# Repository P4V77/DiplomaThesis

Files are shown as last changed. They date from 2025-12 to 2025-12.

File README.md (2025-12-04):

# Modular Current Source
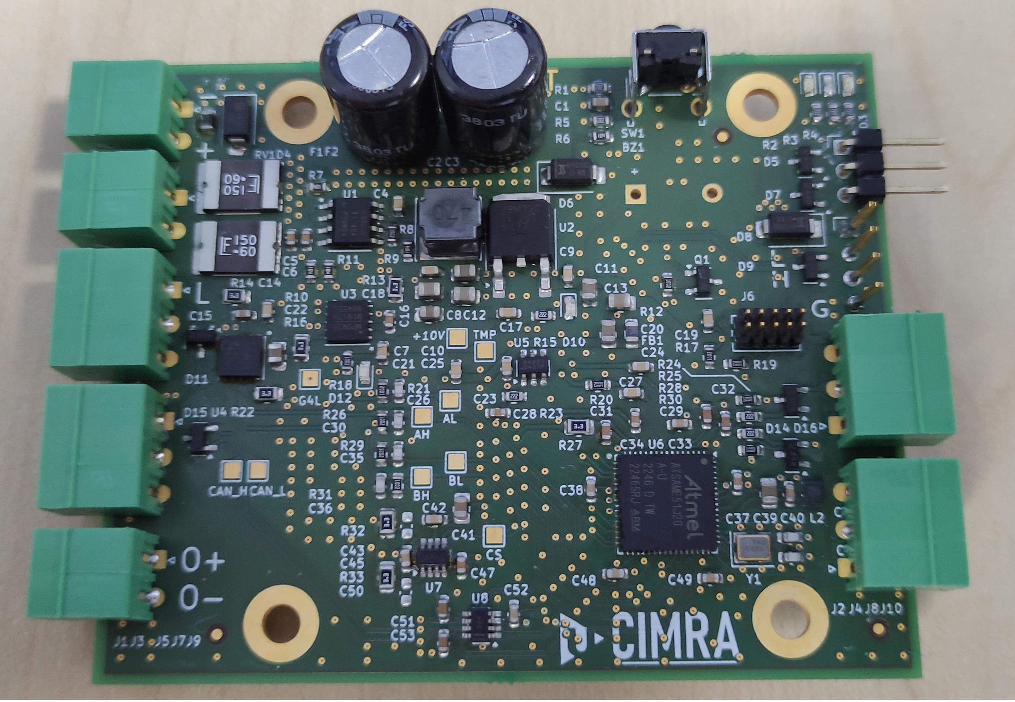
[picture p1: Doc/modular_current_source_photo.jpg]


## Specifications
### v2.0
- **U<sub>IN</sub>** = 12 - 48V
- **I<sub>OUT_DC</sub>** = &plusmn;10 A (max output power limited by PTC fuses to 144W/48V, current is load and input voltage dependent)
- **I<sub>OUT_AC</sub>** = &plusmn;10 A (0 A DC offset, max output power limited by PTC fuses to 144W/48V, current is load and input voltage dependent)
- **Waveforms:**
  - Harmonic with settable DC offset
  - Square with settable DC offset and Duty Cycle <0,100> %
  - Triangle with settable DC offset
- **Default settings:**  
  - I = 0 A
  - DC offset = 0
  - Duty Cycle = 50%
  - Waveform LUT not initialized (DC output set by default)
- **L<sub>load</sub>** at least 100&micro;H, preferably more than 150 &micro;H
- **Communication:**
  - **CAN FD**
    - Baudrate: 500 kb/s
  - **UART**
    - Baudrate: 921 600 Bd
    - 8 data bits
    - 1 stop bit
    - No parity

#### Set New ID
- **Command:** `ID`
- **Data:** Desired ID (0-250)
- **Description:** Sets a new ID for the current source.

**Example:**
```
1ID5  // Sets the ID of the current source to 5
```

#### Set Current
- **Command:** `I`
- **Data:** Desired current as a signed integer in mA (plus sign not allowed)
- **Description:** Sets the current for DC output and amplitude for AC output.

**Examples:**
```
1I650    // Sets current to 650mA for source ID 1
3I-5000  // Sets current to -5A for source ID 3
```

#### Choosing AC/DC Output
- **Commands:**
  - `D` - DC output
  - `A` - AC output
- **Data:**
  - `1` - Enable AC/DC output
  - `0` - Disable output
- **Note:** For AC output, waveform must be chosen first (see "Set Waveform").

**Examples:**
```
1D1  // Enables DC output for source ID 1
4A1  // Enables AC output for source ID 4
```

#### Set Waveform
- **Commands:**
  - `H` - Harmonic waveform
  - `S` - Square waveform
  - `T` - Triangle waveform
- **Data:** Desired frequency in Hz (unsigned integer)
- **Notes:**
  - Zero DC offset, duty cycle defaults to 50% (square)
  - Max waveform frequency from MoSeZ: **6000 Hz** (actual max depends on load)

**Examples:**
```
1H50     // Sets harmonic waveform at 50 Hz for source ID 1
3S6000   // Sets square waveform at 6000 Hz for source ID 3
2T1000   // Sets triangle waveform at 1000 Hz for source ID 2
```

#### Set DC Offset
- **Command:** `O`
- **Data:** Desired DC current offset of alternating current (signed integer in mA, plus sign not allowed)
- **Applicable for:** All AC waveforms

**Examples:**
```
1O650   // Sets DC offset to 650mA for source ID 1
3O-5000 // Sets DC offset to -5A for source ID 3
```

#### Set Duty Cycle (Square Wave Only)
- **Command:** `C`
- **Data:** Desired duty cycle in % (1-99)

**Examples:**
```
1C40  // Sets duty cycle to 40% for source ID 1
3C80  // Sets duty cycle to 80% for source ID 3
```

#### Set Ramp Time (Square Wave Only)
- **Command:** `RT`
- **Data:** Ramp time in percents (unsigned integer)

**Examples:**
```
1RT50  // Sets ramp time of square waveform to 50% (makes triangle waveform) for source ID 1
2RT10 // Sets ramp time of square waveform to 10% for source ID 2
```

#### Set Phase Shift
- **Command:** `F`
- **Data:** Phase shift in degrees (unsigned integer, 0-359)

**Examples:**
```
1F90   // Sets phase shift to 90° for source ID 1
3F180  // Sets phase shift to 180° for source ID 3
```

#### Position Control
- **Command:** `P`
- **Data:**
  - `1` - Enable position control
  - `0` - Disable output
- **Description:** Enables position control for a linear vibrator with position feedback.

**Example:**
```
9P1  // Enables position control for source ID 9
```

#### Set Position Amplitude
- **Command:** `R`
- **Data:** Position amplitude in micrometers (unsigned integer)
- **Constraints:**
  - **Max position offset + amplitude** ≤ 8 mm
  - **Min position offset - amplitude** ≥ 1 mm

**Examples:**
```
1R3500  // Sets position amplitude to 3.5 mm for source ID 1
5R1000  // Sets position amplitude to 1 mm for source ID 5
```

#### Set Position Offset
- **Command:** `V`
- **Data:** Position offset in micrometers (unsigned integer)
- **Constraints:** Same as "Set Position Amplitude"

**Examples:**
```
1V4000  // Sets position offset to 4 mm for source ID 1
5V7000  // Sets position offset to 7 mm for source ID 5
```

#### Start Logging Position to CAN
- **Command:** `CL`
- **Data:**
  - `1` - Start logging
  - `0` - Stop logging
- **Description:** Sends position data every millisecond (ID, actual position, requested position).

**Example:**
```
1CL1  // Starts position logging for source ID 1
```

#### Define Sequence (Whole Period)
- **Command:** `SP`
- **Data:** Duration of the sequence step in whole periods 
- **Description:** Starts defining a new/next sequence command step with a duration measured in whole periods of the waveform.

**Example:**
```
1SP5  // Starts a new sequence step with a duration of 5 whole periods for source ID 1
```

#### Define Sequence (Half Period)
- **Command:** `SH`
- **Data:** Duration of the sequence step in half periods 
- **Description:** Starts defining a new/next sequence command step with a duration measured in half periods of the waveform.

**Example:**
```
2SH10 // Starts a new sequence step with a duration of 10 half periods for source ID 2
```

#### Define Sequence (Milliseconds)
- **Command:** `SW`
- **Data:** Duration of the sequence step in milliseconds 
- **Description:** Starts defining a new/next sequence command step with a duration measured in milliseconds.
**Example:**
```
4SW100 // Starts a new sequence step with a duration of 100 milliseconds for source ID 4
```

#### Stop Filling Current Sequence
- **Command:** `SF`
- **Data:** No data required (value is ignored)
- **Description:** Stops adding commands to the currently being defined sequence step.

**Example:**
```
1SF  // Stops filling the current sequence step for source ID 1
```

#### Start Sequence
- **Command:** `ST`
- **Data:** Any value accepted
- **Description:** Starts the execution of a pre-configured sequence of commands.

**Example:**
```
1ST  // Starts the stored sequence for source ID 1
```

#### Clear All Sequences
- **Command:** `SC`
- **Data:** Any value accepted
- **Description:** Clears all pre-configured sequences of commands.

**Example:**
```
3SC  // Clears all stored sequences for source ID 3
```

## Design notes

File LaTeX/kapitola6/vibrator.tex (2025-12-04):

\newpage

\chapter{Vibrační podavač s voicecoily firmy \emph{DESSEQ}}
\label{sec::voicecoil_function}

Běžné vibrační podavače generují vibrace pomocí rotačních vibrátorů,
což jsou elektrické motory, na jejichž hřídeli je umístěno nevyvážené závaží.
Při otáčení motoru vznikají oscilace v důsledku tohoto nevyvážení rotačního ústrojí.
U takového typu vibrátoru lze řídit pouze výkon otáčky, což má přímý vliv na frekvenci oscilací.

Motivací pro použití vibračního podavače na principu voicecoilu je možnost širšího řízení,
které zahrnuje nejen frekvenci oscilací, ale i jejich amplitudu, výšku vysunutí jádra voicecoilu a
fázi oscilací mezi jednotlivými voicecoily.
Tento přístup umožňuje mnohem přesnější kontrolu nad rychlostí a směrem pohybu součástek po platě,
zejména při kombinaci s dodatečnou snímaním a vyhodnocováním polohy součástek pomocí obrazu z kamery.
Tímto způsobem lze dosáhnout vyšší přesnosti a efektivity při manipulaci jak s drobnými, tak s velkými součástkami.

\begin{figure}[htbp]
	\centering
	
	\caption{Testend vibrační stolice firmy \emph{DESSEQ}}
	\label{fig::vibrator_DESSEQ}
\end{figure}

\section{Snímání polohy}

Pro snímání polohy jádra voicecoilu byla určena metoda snímání změn velikosti
magnetické indukce pomocí senzorů na bázi Hallova jevu.
Optické senzory s dostatečnou datovou prostupností a rozlišením by byly příliš drahé a
kontaktní měření nepřicháyelo v úvahu vzhledem k vibracím a pohybu jádra.
Byly otestovány dvě umístění senzoru.
První umístění bylo na jádře uvnitř voicecoilu a byla měřena magentická indukce jádra.
Druhé umístění bylo na aktuátoru, kde byl měřen magnetický tok přidaného permanentního magnetu.

\subsection{Měření magnetické indukce v jádře voicecoilu}

V prvním prototypu voicecoilu se experimentovalo s umístěním Hallovy sondy na pohyblivém jádře uvnitř voicecoilu.
V tomto případě je magnetická indukce závislá nejen na poloze, ale i na závislosti proudu.
Pro správné určení polohy jádra je nutné znát závislost indukce na proudu a poloze.
Bylo provedeno měření velikosti Hallova napětí při různých proudech a polohách jádra.
Změřená data byla interpolována a následně zdiskretizována do převodní \textit{LUT} tabulky,
která je v tomto případě pole, respektive matice hodnot.
Tato matice hodnot byla nahrána do mikrokontroléru,
který na základě naměřeného Hallova napětí a aktuálního proudu určoval polohu jádra.

\begin{figure}[htbp]
	\centering
	
	\caption{Funkce využitá pro určení polohy jádra prvního prototypu}
	\label{fig::hall_oncore_map}
\end{figure}

Ačkoliv tento způsob umístění a řízení polohy jádra voicecoilu fungoval,
jeho největší nevýhodou bylo obtížnější integrace Hallovy sondy do jádra a
také by do útrob jádra musely vést 3 vodiče navíc,
což by ztěžovalo výrobu a montáž.
Bylo tedy přistoupeno k alternativnímu umístění sondy.

\subsection{Měření indukce permanentního magnetu umístěného zvenku voicecoilu}
\label{section::hall_perm_magnet}

V druhém prototypu voicecoilu byl došlo k umístění permanentního neodymového magnetu na statickém magnetickém obvodu jádra.
Hallova sonda byla umístěna na nástavbě připěvněné na pohyblivém jádře.
Motivací k tomuto umístění je nezávislost magnetické indukce na proudu,
což umožňuje přímo měřit polohu jádra bez ohledu na proud procházející cívkou,
ovšem nevýhodou je potřeba přidání permanenetního magnetu.

\begin{figure}[htbp]
	\centering
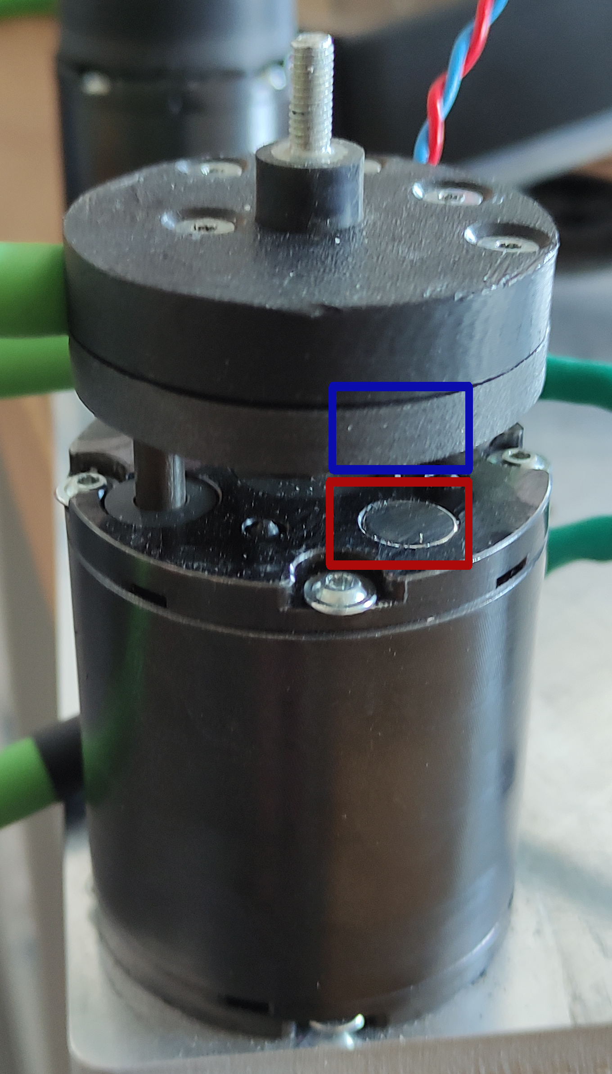
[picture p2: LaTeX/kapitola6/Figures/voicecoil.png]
	
	\caption{Druhý prototyp voicecoilu. V \textbf{červeném} poli umístěn permanentní magnet,
		v \textbf{modrém} poli pod plastovým krytem umístěna Hallova sonda.}
	\label{fig::voice_coil_second_prototype}
\end{figure}

Pro implementaci do mikrokontroléru bylo změřeno výstupní napětí Hallovy sondy při různých polohách jádra.
Výsledky měření byly interpolovány a zdiskretizovány do převodní \textit{LUT} tabulky,
což je v tomto případě pole, respektive pole, viz \oref{fig::hall_perm_magnet}.
Tato předpočítaná \textit{LUT} tabulka byla nahrána do mikrokontroléru.
Konkrétní implementace ve firmwaru je vidět v \nameref{section::position_regulator}.

\begin{figure}[htbp]
	\centering
	
	\caption{Funkce využitá pro určení polohy jádra druhého prototypu}
	\label{fig::hall_perm_magnet}
\end{figure}

\subsection{Přesun součástek}

Omtimální nastavení frekvence a amplitudy kmitů, případně fázového posunu mezi jednotlivými voicecoily,
je závislé na velikosti a hmotnosti součástek, které mají být přesouvány.
V ideálním případě by mělo být nastavování těchto parametrů automatizováno,
například pomocí algoritmu, který by na základě snímání polohy součástek skrze kameru,
určil nastavení proudových zdrojů.
Hledání optimálního nastavení pro přesun součástek je však mimo rámec této práce.

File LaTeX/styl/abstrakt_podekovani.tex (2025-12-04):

\clearpage

\pagenumbering{roman}

%ABSTRAKT

\chapter*{Abstrakt}

Tato diplomová práce se zabývá návrhem a realizací rozšířené verze \emph{modulární platformy MoSeZ} pro řízení elektromagnetických aktuátorů.
Hlavním cílem bylo rozšíření funkcí a zvýšení spolehlivosti původní verze MoSeZ Rev. A.

Vylepšení zahrnují novou revizi jednokanálového proudového zdroje s výstupním proudem až \SI{8}{\ampere},
podporu střídavého výstupu pomocí přímé digitální syntézy \emph{DDS} a implementaci softwarové \textit{PID} regulace ve firmwaru.

Modulární architektura byla zachována – vícekanálové systémy lze sestavit pomocí sběrnice \textit{CAN} a vlastního komunikačního protokolu.
Praktická část zahrnuje návrh \textit{DPS}, vývoj firmwaru v jazyce \textit{C++} a vývoj aplikace \textit{Staff 2.0} pro konfiguraci proudového výstupu zařízení.

Laboratorní měření prokázala přesnost řízení v režimech DC i AC.
Zařízení bylo úspěšně nasazeno k řízení čtyř voicecoilů ve vibračním podavači firmy \emph{DESSEQ}
a závěrem jsou nastíněny možné směry dalšího vývoje.

\vfill\section*{Klíčová slova}

proudový zdroj, elektromagnetické aktuátory, H-můstek, modulární platforma, PID regulace, přímá digitální syntéza, embedded systémy, CAN sběrnice

\vspace{1cm}

\newpage
\chapter*{Abstract}

This thesis deals with the design and implementation of an extended version of the \emph{modular MoSeZ} platform for controlling electromagnetic actuators.
The main objective was to extend the functionality and improve the reliability of the original MoSeZ Rev. A version.

Enhancements include a new revision of the single-channel current source with an output current up to \SI{8}{\ampere}, 
support for alternating output using direct digital synthesis \textit{DDS}, 
and the implementation of software-based \textit{PID} control in \textit{firmware}.

The modular architecture has been retained — multi-channel systems can be assembled using the \textit{CAN} bus and a custom communication protocol. 
The practical part includes the design of the \textit{PCB}, \textit{firmware} development in \textit{C++}, and the \textit{Staff 2.0} application for configuring the current output.

Laboratory measurements confirmed control precision in both DC and AC modes. 
The system was successfully deployed to control four voice coils in a \emph{DESSEQ} vibratory feeder, 
and possible directions for further development are outlined.

\vfill\section*{Keywords}
\noindent
current source, electromagnetic actuators, H-bridge, modular platform, PID control, direct digital synthesis, embedded systems, CAN bus
\vspace{1cm}

%PODEKOVANI

\newpage
\clearpage

\vspace*{3cm}
\section*{Poděkování}\vspace{1.5em}
\noindent
Rád bych poděkoval vedoucímu diplomové práce, \emph{Ing. Martinu Vítkovi}, za cenné odborné rady, vstřícný přístup a metodické vedení, 
které významně přispěly k úspěšnému dokončení této práce. Dále děkuji společnosti \emph{DESSEQ} za poskytnutí \emph{voicecoilů} a 
experimentálních vibračních stolic a za možnost ověřit návrh v praxi.  Poděkování patří také \emph{Ing. Zdeňku Kubíkovi, Ph.D.}, 
který umožnil měření vyzařování v EMC komoře. 
V neposlední řadě děkuji za sílu a vnitřní klid, které mi byly v průběhu práce dopřány z míst, jež přesahují každodennost.

\newpage
\clearpage

\vspace*{3cm}
\section*{Prohlášení}\vspace{1.5em}
\noindent
Během přípravy této práce autor použil \textit{ChatGPT} a \textit{Gemini AI}
k zlepšení čitelnosti a jazykové kvality rukopisu. 
Po použití tohoto nástroje/služby autor pečlivě zkontroloval a
upravil obsah podle potřeby a přebírá plnou odpovědnost za výsledný obsah práce.

% Tato diplomová práce se zaměřuje na návrh a realizaci rozšířené verze modulární platformy \emph{MoSeZ} určené pro řízení elektromagnetických aktuátorů. 
% Cílem práce bylo zvýšit modularitu, spolehlivost a funkční rozšiřitelnost původní verze zařízení \emph{MoSeZ Rev. A}, 
% a přizpůsobit ji pro širší spektrum technických aplikací.

% Navržená vylepšení zahrnují novou hardwarovou revizi jednokanálového proudového zdroje s výstupním proudem až \SI{8}{\ampere}, 
% doplněnou o podporu střídavých proudových výstupů pomocí přímé digitální syntézy (\emph{DDS}) a 
% řešení regulace pomocí softwarového \emph{PID} regulátoru.

% Významným aspektem návrhu je zachování modulární architektury platformy, 
% která umožňuje sestavení vícekanálového systému z jednotlivých jednokanálových modulů propojených pomocí průmyslové sběrnice \emph{CAN}. 
% Vlastní komunikační protokol založený na sběrnici \emph{CAN} zajišťuje kompatibilitu a integraci do rozsáhlejších systémů.

% Teoretická část práce se zabývá rešerší komunikačních protokolů využívajících sběrnici \emph{CAN}.
% Praktická část zahrnuje návrh desky plošných spojů, vývoj firmwaru v jazyce \emph{C++} a 
% tvorbu desktopové aplikace \emph{Staff 2.0} pro konfiguraci a diagnostiku proudového výstupu zařízení.

% Navržené řešení bylo ověřeno sérií laboratorních měření zaměřených na výstupní proud, 
% účinnost, harmonické zkreslení a přesnost regulace. 
% Výsledky prokázaly, že zařízení splňuje požadavky na přesné řízení elektromagnetických aktuátorů v režimech \emph{DC} i \emph{AC}.
% Zařízení bylo rovněž úspěšně nasazeno pro řízení čtyř voicecoilů v experimentálním vibračním podavači firmy \emph{DESSEQ}. 
% Závěrem je navrženo možné směřování dalšího vývoje platformy.

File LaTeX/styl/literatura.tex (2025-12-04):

%https://www.overleaf.com/learn/latex/Biblatex_bibliography_styles
\renewcommand\bibname{Seznam použité literatury}
\printbibliography
\addcontentsline{toc}{chapter}{Seznam použité literatury}

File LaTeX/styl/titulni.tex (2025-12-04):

\begin{titlepage}
\begin{center}

	\textsc{\huge Západočeská univerzita v Plzni}

	%\textcolor[RGB]{91, 155, 213}{\rule{\textwidth}{1.5pt}}
	\textcolor{blue-light}{\rule{\textwidth}{1.5pt}}
    
    \Large{Fakulta elektrotechnická} \\
    \large{\thesisdepartment}

	\vspace{7cm}

	\Huge{\textsc{\textbf{\thesistype}}} \\
	\vspace{0.5cm}
	\Large{\thesistopic} \\
	
	\vfill

	\large
	\begin{tabular}{ m{4cm} m{6cm} } 
		Autor práce: & \textbf{\thesisauthor} \\
		Vedoucí práce: & \textbf{\thesissupervisor} \\
		% Konzultant práce: & \textbf{\thesisconsultant} \\
	\end{tabular}

	\textcolor[RGB]{91, 155, 213}{\rule{\textwidth}{1.5pt}}
	\Large\number\year

\end{center}

\cleardoublepage
\end{titlepage}

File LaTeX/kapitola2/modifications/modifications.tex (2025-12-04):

\chapter{Úpravy desky plošného spoje proudového zdroje \emph{MoSeZ Rev. A}}

Při nové revizi desky (Rev. B) byl kladen důraz na zvýšení maximálního napájecího napětí z \SI{12}{\volt} na \SI{48}{\volt}, 
s možností pracovat již od \SI{12}{\volt}. 
Byly identifikovány a odstraněny některé problémy v původní verzi (Rev. A) proudového zdroje \textit{MoSeZ}. 
Rovněž byly rozšířeny funkce a věnována pozornost zmenšení velikosti desky plošného spoje.

Z pohledu součástkové základny byl značně zredukován počet druhů součástek. 
Operační zesilovače nejsou v nové revizi vůbec použity a druhy kondenzátorů a rezistorů byly výrazně sníženy. 
Zůstalo čtyřvrstvé \textit{DPS} (\textit{TOP} – \textit{IN1} – \textit{IN2} – \textit{BOT}), 
avšak vrstevní uspořádání bylo upraveno na \textit{SIGNÁL} – \textit{GND} – \textit{GND} – \textit{SIGNÁL} 
namísto původního \textit{SIGNÁL} – \SI{3,3}{\volt} – \textit{GND} – \textit{SIGNÁL}. 
Většina součástek byla přesunuta na \textit{TOP} stranu desky, 
zatímco na \textit{BOT} straně zůstaly pouze výkonové \textit{MOSFET} tranzistory a ochranné \textit{TVS} diody. 
Celkové rozměry desky byly zredukovány o přibližně \SI{21}{\percent}.

Další detailní úpravy jsou popsány v následujících podkapitolách, 
které odpovídají blokovému rozdělení v elektrickém schématu, viz obr. \ref{fig::block_diagram}.

\begin{figure}[htpb]
	\centering
	
	\caption{Blokové schéma MoSeZ rev. B}
	\label{fig::block_diagram}
\end{figure}

\section{Vstupní obvody}

Vstupní obvody desky MoSeZ (rev. B) jsou navrženy tak,
aby zajistily spolehlivou ochranu a stabilní napájení.
Zvlnění vstupního napětí efektivně minimalizuje kombinace dvou elektrolytických kondenzátorů.
Pro ochranu proti přetížení jsou na vstupu dvě \textit{PTC} pojistky.
Jakmile proud překročí bezpečný limit, pojistky zvýší svůj odpor a odpojí napájení.
Proti přepólování je deska chráněna kombinací diody a \textit{PTC} pojistek,
zatímco varistor a \textit{TVS} dioda poskytují ochranu proti přepětí.
Měření vstupního napětí probíhá přes napěťový dělič,
který převádí maximální napětí na úroveň vhodnou pro analogově-digitální převodník mikrokontroléru.

\subsection{Vstupní elektrolytické kondenzátory}
\label{section::input_capacitors}
Minimální kapacitu vstupního kondenzátoru lze vypočítat podle jednoduchého vzorce:

\begin{equation}
	C_{\text{IN}} \geq \frac{I_{\text{LOAD}}}{f_{\text{SW}} \cdot \Delta U_{\text{ripple}}},
	\label{eq:min_capacity}
\end{equation}

kde:
\begin{itemize}
	\item $C_{\text{IN}}$ je minimální kapacita vstupního kondenzátoru ve \SI{}{\farad}
	\item $I_{\text{LOAD}}$ je proud zátěže v \SI{}{\ampere}
	\item $f_{\text{SW}}$ je spínací frekvence \SI{}{\hertz}
	\item $\Delta U_{\text{max\_zvlnění}}$ je maximální povolené zvlnění napětí \SI{}{\volt}
\end{itemize}

Maximální plánovaný výstupní proud zdroje \emph{MoSeZ} je $I_{\text{LOAD}} = \SI{8}{\ampere}$, 
ale pro rezervu ve výpočtech byl zvolen proud $I_{\text{LOAD}} = \SI{10}{\ampere}$.
Plánovaná spínací frekvence je $f_{\text{SW}} = \SI{100}{\kilo\hertz}$
a maximální přípustné zvlnění vstupního napětí bylo určeno na \SI{0,5}{\volt},
takže po dosazení do rovnice \eqref{eq:min_capacity} dostáváme:

\begin{equation}
	C_{\text{IN}} \geq \frac{10}{100 \cdot 10^3 \cdot 0,5}
\end{equation}

takže,

\begin{equation}
	C_{\text{IN}} \geq  240 \,\mu\mathrm{F}
\end{equation}

Zvolené zvlnění \SI{0,5}{\volt} zohledňuje napájecí napětí \SI{12}{\volt} a
potřebu dostatečné rezervy pro napájení pomocného spínaného zdroje \textit{LMR38010} (viz \nameref{section::smps_LMR38010}).
Tento pomocný zdroj zajišťuje výstupní napětí \SI{10}{\volt},
které je kritické pro napájení budičů \textit{MOSFET} tranzistorů \textit{MP1917}.
Napájecí napětí těchto budičů se totiž rovná spínacímu napětí na jejich výstupu (viz \cite{mp1917_ds}).
Pokud by spínací napětí MP1917 kleslo pod \SI{10}{\volt},
hrozilo by neúplné otevření hradel MOSFET tranzistorů,
což by mohlo vést k jejich přehřívání (viz \cite{ISC080N10NM6_ds}).
Vzhledem k tomu, že k významnému zvlnění dochází při vyšších výstupních proudech,
hrozí v takovém případě poškození tranzistorů vlivem tepelného průrazu.

Kvůli běžné toleranci kapacity elektrolytických kondenzátorů \SI{\pm 20}{\percent} jsem
pro filtraci napájení zvolil dvojici \SI{150}{\micro\farad} \textit{THT} kondenzátorů.
Použití \textit{THT} kondenzátorů v této kapacitní kategorii přináší finanční úsporu oproti povrchově montovaným (\textit{SMD}) kondenzátorům,
které byly použity v předchozí verzi desky \emph{MoSeZ} (rev. A).

\subsection{Nadproudová ochrana a ochrana proti přepolování}

Pro nadproudovou ochranu byly použity \textit{PTC} pojistky \textit{2920L150/60 od firmy Littelfuse}.
Oproti původnímu návrhu desky (\textit{MoSeZrev. A}) byl počet těchto pojistek snížen na dvě.
Každá z pojistek je dimenzována pro trvalý proud \SI{1,5}{\ampere},
což dohromady postačuje pro jištění trvalého proudu do \SI{3}{\ampere}.
Původní ochranná dioda byla nahrazena levnějším modelem \textit{BYG10D}.
Tato dioda spolu s \textit{PTC} pojistkami slouží jako ochrana proti přepólování.
V případě nechtěné záměny polarity napájecího napětí se dioda \textit{BYG10D} stane vodivou a zkratuje vstupní napětí.
Pokud proud z napájecího zdroje v takové situaci překročí \SI{3}{\ampere}, \textit{PTC} pojistky se zahřejí a obvod rozpojí.

V případě, kdy proud z napájecího zdroje nepřekročí prahový proud \textit{PTC} pojistek,
hrozí tepelný průraz diody \textit{BYG10D}.
To by ovšem znamenalo, že se dioda pravděpodobně stane trvale vodivou,
takže by došlo k vyřazení zdroje z provozu do doby její výměny.
Elektrolytické kondenzátory by však zůstaly ochráněny.

\section{Ochrana proti přepětí}

Pro ochranu proti přepětí na vstupu slouží kombinace varistoru a \textit{TVS} diody,
obě s pracovním napětím \SI{48}{\volt}.
Při návrhu je klíčové umístit tyto součástky co nejblíže vstupnímu konektoru.
Důležité je i jejich fyzické uspořádání od nejpomalejší po nejrychlejší,
tedy nejblíže ke vstupnímu konektoru varistor a za ním \textit{TVS} dioda.
Tím je zajištěno, že rychlá \textit{TVS} dioda omezí přepětí do doby, než se aktivuje varistor,
který následně převezme hlavní část svodového výkonu.
Varistory, jakožto pomalejší ochranné prvky, jsou schopny dlouhodobě svádět větší výkon než \textit{TVS} diody.
V případě opačného pořadí hrozí, že \textit{TVS} dioda bude muset odvést veškerý výkon,
protože na varistor, se nedostane žádné přepětí, což by mohlo vést ke zničení \textit{TVS} diody.

\subsection{Měření vstupního napětí}

Vstupní napětí je měřeno pomocí děliče napětí,
který je navržen tak, aby při \SI{48}{\volt} na vstupu dával na výstupu \SI{1,65}{\volt}.
Maximální napětí, které jsou schopny měřit AD převodníky použitého mikrokontroléru (viz \nameref{section::mcu_hw}),
je \SI{2,5}{\volt}, přičemž jsou tolerantní vůči napětí \SI{3,3}{\volt}.
To znamená, že jsou schopny měřit vstupní napětí až do \SI{106}{\volt}
a k poškození analogových vstupů MCU dojde až při napětí \SI{141}{\volt}.
Tato velká rezerva je zvolena z důvodu ochrany analogových vstupů mikrokontroléru,
a tím i jeho převodníku, před přepětím, nebo v případě, že by uživatel připojil příliš vysoké napětí.
Velikost vstupního napětí se nepoužívá pro regulaci a jeho znalost slouží pouze pro orientační měření.
Proto není kritická přesnost tohoto měření.

\section{Pomocný zdroj napětí \SI{10}{\volt}}
\label{section::smps_LMR38010}

V nové revizi \textit{DPS} zajišťuje \SI{10}{\volt} výstup pro budiče \textit{MOSFET} tranzistorů obvod \textit{LMR38010}.
Tento synchronní snižující měnič reguluje široký rozsah vstupního napětí
a minimalizuje potřebu externích ochranných součástek a
umožňuje nastavit spínací frekvenci v rozsahu \SI{200}{\kilo\hertz} až \SI{2.2}{\mega\hertz}.
Vestavěné ochrany zahrnují proudové omezení po jednotlivých cyklech,
ochranu proti zkratu a tepelnou ochranu při nadměrném vyzářeném výkonu.

\subsection{Výpočet velikosti odporů v napěťové zpětné vazbě}

Rovnice pro výpočet zpětnovazebního rezistoru z datasheetu viz \cite{mp1917_ds} říká, že

\begin{equation}
	R_{FBT} = \frac{U_{OUT} - U_{REF}}{U_{REF}} \cdot R_{FBB},
	\label{eq:lmr_fb}
\end{equation}

kde

\begin{enumerate}
	\item \(R_{FBT} \) : Odpor horního rezistoru (mezi \(U_{OUT} \) a \textit{FB} pinem), měl by vyjít v rozmezí mezi \SI{10}{\kilo\ohm} až \SI{100}{\kilo\ohm}.
	\item \(U_{OUT} \) : Požadované výstupní napětí stabilizátoru.
	\item \(U_{REF} \) : Referenční napětí, \SI{1}{\volt} pro \textit{LMR38010}.
	\item \(R_{FBB} \) : Odpor dolního rezistoru (mezi FB pinem a zemí).
\end{enumerate}

dosazením $ \quad U_{OUT} = \SI{10}{\volt}$ a $R_{FBB} = \SI{10}{\kilo\ohm}$ dostávám:

\begin{equation}
	R_{FBT} = 9 \cdot 10 \cdot 10^3 = \SI{90}{\kilo\ohm}
\end{equation}

Nicméně pro unifikaci pasivních součástek byl zvolen $ \quad R_{FBT} = \SI{100}{\kilo\ohm}$ a $R_{FBB} = \SI{10}{\kilo\ohm}$,
takže upravení rovnice \eqref{eq:lmr_fb} dostávám výstupní napětí pro tuto kombinaci, asice:

\begin{equation}
	U_{OUT} = U_{REF} \cdot \left(\frac{R_{FBT}}{R_{FBB}} + 1 \right) = 1 \cdot \left(\frac{100}{10} + 1 \right) = \SI{11}{\volt}.
	\label{eq:lmr_vout_real}
\end{equation}

Těmito \SI{11}{\volt} jsou napájeny budiče \textit{MP1917},
což znamená, že se zároveň jedná o napětí,
kterými budou budiče spínat gaty \textit{MOSFET} transistorů, viz \cite{mp1917_ds}.
Napětí \SI{11}{\volt} je dle datasheetu tranzistorů \textit{ISC080N10} přípustná velikost spínacího napětí gatů,
viz \cite{ISC080N10NM6_ds}.

\subsection{Výpočet velikosti odboru programujícího spínací kmitočet}

Rovnice pro výpočet odporu RT z datasheetu \cite{mp1917_ds} říká, že

\begin{equation}
	R_{T} = 30970 \cdot f_{SW}^{-1,027},
	\label{eq:lmr_rt}
\end{equation}

kde

\begin{enumerate}
	\item $R_{T}$ : Odpor mezi pinem textit{RT/SYNC} a zemí, udávaný v\SI{}{\kilo\ohm}.
	\item $f_{SW}$ : Spínací frekvence, udávaná v \SI{}{\kilo\hertz}.
\end{enumerate}

Pro unifikaci pasivních součástek byl zvolen R\_{T} = \SI{50}{\kilo\ohm},
respektive paralelní kombinace dvou \SI{100}{\kilo\ohm} odborů použitých v napěťové zpětné vazbě \textit{LMR38010}.
Upravením rovnice \eqref{eq:lmr_rt} dostávám skutečnou spínací frekvenci pro tuto hodnotu terminačního odporu, a sice:

\begin{equation}
	f_{SW} = \left(\frac{R_T}{30970} \right)^{-\frac{1}{1,027}} =
	\left(\frac{50}{30970} \right)^{-\frac{1}{1,027}} \approx \SI{628}{\kilo\hertz}.
	\label{eq:lmr_fsw_real}
\end{equation}

Vyšší spínací frekvence umožňují použití menších induktorů a kondenzátorů ve výstupním LC filtru,
což vede k úspoře místa a potenciálně lepší dynamické odezvě měniče.
Nicméně s rostoucí frekvencí se zvyšují ztráty způsobené parazitními kapacitami
a svody v pasivních součástkách i na plošném spoji, což může negativně ovlivnit účinnost,
zejména při nízkých výstupních výkonech.
Při velmi malých zátěžových proudech a vysokých spínacích frekvencích mohou tyto parazitní ztráty tvořit významnou část celkového výkonu,
a proto bývá výhodnější zvolit nižší spínací frekvenci, kde jsou tyto ztráty menší.
Optimální volba spínací frekvence tak závisí na kompromisu mezi velikostí pasivních součástek,
účinností a požadavky na elektromagnetickou kompatibilitu (EMI), viz \cite{buck_switching_freq_affection}

\subsection{Výpočet velikosti výstupního dolnopropustého LC filtru}

LC filtr je nezbytnou součástí každého spínaného zdroje, zejména pokud má na výstupu stejnosměrné napětí.
Pro správný výběr induktoru jsou klíčové hodnota indukčnosti a saturační proud.
Indukčnost se obvykle volí tak, aby zvlnění výstupního proudu bylo mezi \SI{20}{\percent} a \SI{40}{\percent}.

Pro výpočet minimální indukčnosti platí vztah:

\begin{equation} L \geq \frac{(U_{IN} - U_{OUT})}{f_{SW} \cdot K \cdot I_{OUT(MAX)}} \cdot \frac{U_{OUT}}{U_{IN}}. \label{eq:lmr_inductance} \end{equation}

Saturační proud induktoru by měl být alespoň tak velký jako maximální očekávaný výstupní proud, aby se zabránilo jeho nasycení.
Pro spínací frekvence nad \SI{1}{\mega\hertz} se doporučují induktory s feritovým jádrem kvůli nižším ztrátám.

Maximální výstupní proud $ I_{OUT(MAX)} $ byl zvolen \SI{0,5}{\ampere} pro zajištění dostatečné výkonové rezervy.
I přes špičkové odběry budičů se očekává, že střední hodnota výstupního proudu bude výrazně nižší.
Minimální napájecí napětí bylo stanoveno na $U_{IN} = \SI{12}{\volt}$
a požadované výstupní napětí $U_{OUT} = \SI{11}{\volt}$, viz rovnice \eqref{eq:lmr_vout_real}.
Koeficient zvlnění proudu byl zvolen $K = 0,2$ (tj. \SI{20}{\percent}) a
spínací frekvence $f_{SW} = \SI{628}{\kilo\hertz}$, viz rovnice \eqref{eq:lmr_fsw_real}.

Dosazením do rovnice \eqref{eq:lmr_inductance} dostáváme:

\begin{equation} L \geq \frac{(12 - 11)}{628 \cdot 10^3 \cdot 0,2 \cdot 0,5} \cdot \frac{11}{12} \approx \SI{29,3}{\micro\henry}. \end{equation}

Dle doporučení v datasheetu \cite{mp1917_ds} byla zvolena nejbližší vyšší vyráběná hodnota, tedy $L = \SI{33}{\micro\henry}$.

Minimální kapacita $C_{OUT}$ byla určena podle vztahu, který neuvažuje statické zvlnění,
ale zaměřuje se na schopnost zdroje reagovat na skokové změny výstupního proudu.
To je klíčové, protože zdroj bude primárně napájet budiče \textit{MOSFET} tranzistorů,
kde dochází k rychlým změnám odběru.

\begin{equation}
	C_{OUT} \geq \frac{\Delta I_{OUT}^2 \cdot L}{2 \cdot U_{OUT} \cdot U_{\text{zvlnění}}}
	\label{eq:cout_min_cap_smps}
\end{equation}

kde:

\begin{itemize}
	\item $C_{OUT}$ : Minimální kapacita výstupního kondenzátoru pro omezení překmitu napětí.
	\item $\Delta I_{OUT}$ : Maximální změna výstupního proudu v aplikaci.
	\item $L$ : Indukčnost cívky.
	\item $U_{OUT}$ : Výstupní napětí.
	\item $U_{\text{zvlnění}}$ : Maximální povolená změna výstupního napětí vlivem proudového skoku.
\end{itemize}

Pokud dosadíme následující parametry:

$\Delta I_{OUT} = \SI{1}{\ampere}, \quad
	L = \SI{33}{\micro\henry}, \quad
	U_{OUT} = \SI{11}{\volt}, \quad
	U_{\text{zvlnění}} = \SI{50}{\milli\volt}$
do rovnice \eqref{eq:cout_min_cap_smps}, dostaneme:

\begin{equation}
	C_{OUT} \geq \frac{1^2 \cdot 33 \cdot 10^{-6}}{2 \cdot 11 \cdot 50 \cdot 10^{-3}} \approx \SI{30}{\micro\farad}.
\end{equation}

Na filtraci jsou použity keramické kondenzátory s dielektrikem \textit{X7R} dimenzované na napětí \SI{25}{\volt}.
Keramika \textit{X7R} má následující vlastnosti:

\begin{itemize}
	\item \textbf{Snížení kapacity při DC napětí} – při $\frac{1}{2}$ nominálního napětí a
	      pokojové teplotě je kapacita až o \SI{30}{\percent} nižší než nominální hodnota.
	\item \textbf{Teplotní drift} – změna kapacity až $\pm15\%$ v rozsahu \SI{-50}{\degreeCelsius} až \SI{+125}{\degreeCelsius}.
	\item \textbf{Stárnutí materiálu} – kapacita klesá o jednotky procent v čase.
\end{itemize}

Vzhledem k těmto faktorům a snaze unifikovat součástky na desce \emph{MoSeZ} byla použita kombinace:

\begin{itemize}
	\item $3 \cdot \SI{22}{\micro\farad}$ keramické kondenzátory \textit{X7R}.
	\item $1 \cdot \SI{100}{\nano\farad}$ keramický kondenzátor umístěný co nejblíže k cívce pro redukci vysokofrekvenčního rušení.
\end{itemize}

Tato kombinace zajišťuje \textbf{dostatečnou rezervu kapacity}, \textbf{nižší ESR} a \textbf{lepší potlačení rušení}.

\subsection{Vstupní filtrační kondenzátory}

Na vstupu je pouze paralelní kombinace dvou \SI{22}{\nano\farad} kondenzátorů pro filtraci vysokofrekvenčního rušení.
Další kondenzátory s vyšší kapacitou byly z návrhu vyřazeny.
Důvodem je umístění obvodu \textit{LMR38010} v těsné blízkosti velkých vstupních filtračních kondenzátorů
(viz \nameref{section::input_capacitors}).
Vzhledem k této skutečnosti se ukázalo použití lokálních filtračních kondenzátorů s větší kapacitou jako zbytečné.
Toto řešení přineslo značnou prostorovou úsporu na DPS,
což bylo velmi výhodné, protože v oblasti usazení obvodu \textit{LMR38010} byl prostor velmi omezený.

\section{Pomocný zdroj napětí \SI{3,3}{\volt}}
\label{sec::linear_lm78}

Napětí \SI{3,3}{\volt} pro mikroprocesor a 
ostatní obvody jako \textit{TCAN334G}, \textit{INA241B1},
či \textit{MCP1501T}  obstarává obvod \textit{LMA78M33}.
Jedná se o lineární stabilizátor napájený \SI{10}{\volt} výstupu z \textit{LMR38010}, viz \nameref{section::smps_LMR38010}.
Filtrační kondenzátory byly zvoleny dle jasného doporučení v datasheetu bez jakýchkoliv kalkulací,
viz \cite{LM78M_ds}.
Samotý obvod je tak jednoduchý a obecně známý, že nemá cenu o něm cokoliv více psát.

V původní verzi zdroje byly pro snižování vstupního napětí použity dva snižující měniče v integrovaném obvodu \textit{MP2344}.
Tyto obvody poskytovaly napětí \SI{10}{\volt} pro napájení budičů \textit{MOSFET} tranzistorů a \SI{3,3}{\volt} pro napájení mikroprocesoru.
V důsledku náhodných přepětí na výstupu těchto obvodů docházelo k poškození mikroprocesorů.
Záměnou řešení s \textit{MP2344} se podařilo problém odstranit,i když to nemusela být vina obvodů jako takových,
ale například špatného návrhu snižujících měničů. 
Nové řešení s \textit{LM78M33} je v každém případě mnohem jednodušší a levnější.

\section{Mikrokontrolér}
\label{section::mcu_hw}

V mikrokontroléru bude implementovaný regulátor a bude obstarávat veškerou komunikaci,
včetně zpracovávání vstupů z tlačítka a rozsvicování indikačních \textit{LED}.
Nová revize využívá stejný typ mikrokontroléru, asice \textit{ATSAME51J20A}.
V původním návrhu desky byl jako zdroj kmitočtu pro mikroprocesor použit \SI{32}{\kilo\hertz} krystalový rezonátor.
Tento rezonátor způsoboval nespolehlivé spouštění při inicializaci procesoru.
V nové verzi desky byl použit \SI{20}{\mega\hertz} rezonátor, 
který byl ověřen v jiných projektech s \textit{MCU} od \textit{Microchip}.
Došlo také k opravě záměny pinů programovacího konektoru \textit{SWDIO} a \textit{SWDCLK},
což byla chyba v původním návrhu desky \textit{MoSeZ}, která vedla k výrobě specialního programovacího kabelu.

Každý digitální napájecí vstupní pin \textit{VDDIO} je odfiltrován keramickým kondenzátorem s kapacitou \SI{100}{\nano\farad}.
Ke spínanému zdroji integrovaného v mikrokontroléru je připojena indukčnost o velikosti \SI{10}{\micro\henry},
která filtruje výstupní proud a za ni je pro filtrování vzniklého napětí \textit{VDDCORE} připojena kombinace \SI{22}{\micro\farad} a \SI{100}{\nano\farad} kondenzátorů.
Analogové napětí \textit{VDDANA} se tvoří z napětí \textit{VDDIO} přes LC filtr tvořený dvěma kondenzátory a feritovou perličkou zapojenými do $\pi$ článku.
Kondenzátory mají kapacitu \SI{22}{\micro\farad} a feritová perlička o impedanci \SI{330}{\ohm} na frekvenci \SI{100}{\mega\hertz}.
Součástky byly vybrány a zapojeny dle doporučení v datasheetu, viz \cite{ATSAME51J20A_ds}.

\section{Proudový výstup}

Řízení elektromagnetických aktuátorů vyžaduje spolehlivý a výkonný proudový výstup, 
který je schopen generovat obousměrné stejnosměrné (DC) a střídavé (AC) signály s požadovanými parametry. 
Z tohoto důvodu byla v rámci proudových zdrojů \textit{MoSeZ} navržena výstupní část založená na topologii \textit{H-můstku}, 
která umožňuje obousměrný tok proudu a generování dynamicky tvarovaných průběhů.
Klíčovými aspekty návrhu výstupního obvodu jsou vhodná volba výkonových tranzistorů, 
účinné řízení spínacích prvků a tepelný management. 
V následujících podsekcích jsou rozebrány konstrukční i výpočetní aspekty této části obvodu.

\subsection{H-můstek}

Tranzistory \textit{MOSFET} původní revize desky \textit{MoSeZ} by nemohly pracovat na napětí \SI{48}{\volt}, 
proto bylo nutné zvolit nové tranzistory s parametrem \(U_{DS\_MAX} > 2 \cdot \SI{48}{\volt}\). 
Výběr padl na \textit{Infineon ISC080N10}, u kterého bylo nutné ověřit, 
že může být dlouhodobě zatěžován proudem \SI{8}{\ampere} bez rizika tepelného průrazu. 
Maximální proud do zátěže bude uvažován jako \SI{10}{\ampere}, což zajistí určitou výkonovou rezervu.

Pro výpočet celkových ztrát na \textit{MOSFET} tranzistoru se dle \cite{mosfet_losses} se používá následující vztah:

\begin{equation}
    P_{LOSS} = P_{J} + P_{SW} + P_{G}
\end{equation}

kde:

\begin{itemize}
    \item \(P_{LOSS}\): Celkové ztráty na \textit{MOSFET} tranzistoru.
    \item \(P_{J}\): Ztráty způsobené odporem kanálu \textit{MOSFET} tranzistoru (vodivostní ztráty).
    \item \(P_{SW}\): Ztráty vznikající při spínání a rozepínání tranzistoru (spínací ztráty).
    \item \(P_{G}\): Ztráty způsobené kapacitou gate tranzistoru (ztráty hradlem).
\end{itemize}

Vodivostní ztráty se vypočítají jako:

\begin{equation}
    P_{J} = I_{D}^{2} \cdot R_{DS\_ON}
    \label{eq:joullossesfet}
\end{equation}

kde ze zadání a datasheetu \cite{ISC080N10NM6_ds}:

\begin{itemize}
    \item \(I_D\): Proud protékající tranzistorem (Drain current) – \SI{10}{\ampere}.
    \item \(R_{DS\_ON}\): Odpor kanálu tranzistoru v sepnutém stavu (Drain-source resistance on-state) – \SI{8.5e-3}{\ohm}.
\end{itemize}

Dosazením těchto hodnot do rovnice \eqref{eq:joullossesfet} dostaneme:

\begin{equation}
    P_{J} = 10^2 \cdot 8.5 \cdot 10^{-3} = \SI{0,85}{\watt}
\end{equation}

Spínací ztráty se vypočítají jako:

\begin{equation}
    P_{SW} = 0,5 \cdot U_{CC} \cdot I_{D} \cdot (t_{r} + t_{f}) \cdot f_{SW}
    \label{eq:switchingFETlosses}
\end{equation}

kde dle zadání a datasheetu \cite{ISC080N10NM6_ds}:

\begin{itemize}
    \item \(U_{CC}\): Napájecí napětí – \SI{48}{\volt}.
    \item \(t_{r}\): Náběžná doba spínání – \SI{2,9e-9}{\second}.
    \item \(t_{f}\): Sestupná doba spínání – \SI{2,6e-9}{\second}.
    \item \(f_{SW}\): Spínací frekvence – \SI{100}{\kilo\hertz}.
\end{itemize}

Dosadíme tyto hodnoty do rovnice \eqref{eq:switchingFETlosses}:

\begin{equation}
    P_{SW} = 0,5 \cdot 48 \cdot 10 \cdot 2,9 \cdot 10^{-9} + 2,6 \cdot 10^{-9} \cdot 100 \cdot 10^{3} = \SI{0,1392}{\watt}
\end{equation}

Ztráty hradlem se vypočítají jako:

\begin{equation}
    P_{G} = Q_{G} \cdot U_{CC} \cdot f_{SW}
    \label{eq:FETleakgatelosses}
\end{equation}

kde dle předchozích výpočtů a datasheetu \cite{ISC080N10NM6_ds}:

\begin{itemize}
    \item \(Q_{G}\): Celkový náboj hradla (gate charge total) – \SI{2,38e-8}{\coulomb}.
\end{itemize}

Pro výše uvedené parametry, po dosazení do rovnice \eqref{eq:FETleakgatelosses} dostáváme:

\begin{equation}
    P_{G} = 2,38 \cdot 10^{-8} \cdot 48 \cdot 100 \cdot 10^{3} = \SI{0,1142}{\watt}
\end{equation}

Celkové ztráty se vypočítají jako součet všech ztrát:

\begin{equation}
    P_{LOSS} = P_{J} + P_{SW} + P_{G} = 0,85 + 0,1392 + 0,1142 = \SI{1,1034}{\watt}
\end{equation}

Maximální přípustné ztráty tranzistoru při chlazení footprintem DPS lze určit jako:

\begin{equation}
    P_{Z\_MAX} = \frac{T_{J\_MAX} - T_{\text{SURR}}}{R_{\text{thJA}}}
\end{equation}

kde dle datasheetu \cite{ISC080N10NM6_ds}:

\begin{itemize}
    \item \(T_{J\_MAX}\): Maximální přípustná teplota přechodu tranzistoru – \SI{175}{\celsius}.
    \item \(T_{\text{SURR}}\): Okolní teplota – \SI{50}{\celsius} (určeno jako teplota okolí s velkou rezervou).
    \item \(R_{\text{thJA}}\): Tepelný odpor tranzistor-okolí – \SI{75}{\kelvin\per\watt}. 
	Dle datasheetu \cite{ISC080N10NM6_ds} je \SI{50}{\kelvin\per\watt} pro \SI{6}{\centi\meter^2}. 
	Ačkoliv plánuji ještě větší chladící plochu, pro jistotu jsem přidal rezervu.
\end{itemize}

Po dosazení:

\begin{equation}
    P_{Z\_MAX} = \frac{175 - 50}{75} = \SI{1,6667}{\watt} > P_{LOSS} % Opraveno na >
\end{equation}

Takže tranzistor by neměl mít s provozem \SI{8}{\ampere} sebemenší problém. 
Teplota přechodu se při těchto provozních parametrech dá spočítat jako:

\begin{equation}
    T_{J} = T_{\text{SURR}} + P_{LOSS} \cdot R_{\text{thJA}}
\end{equation}

Po dosazení hodnot známých z předchozích výpočtů dostaneme:

\begin{equation}
    T_{J} = \SI{50}{\celsius} + \SI{1,1034}{\watt} \cdot \SI{75}{\kelvin\per\watt} = \SI{132,758}{\celsius} % Opraveno na 132,758
\end{equation}

Vypočtená teplota přechodu \SI{132,758}{\celsius} je mnohem nižší než maximální výrobcem přípustná teplota \SI{175}{\celsius}, 
takže tranzistor by měl být schopen pracovat bez rizika tepelného průrazu s relativně slušnou teplotní rezervou.
Proudový výstup je chráněn proti náhodným přepětím dvěma \textit{TVS} diododami s pracovním napětím \SI{48}{\volt},
viz \pref{priloha:schema_CurrentOutput}.

\subsection{Budiče tranzistorů}

Jsou využity dva budiče \textit{MOSFET} tranzistorů \textit{MP1917}.
Každý je řízen dvěma \textit{PWM} signály, z nichž jeden je pro řízení \textit{low-side} tranzistoru a
druhý pro řízení \textit{high-side} tranzistoru.
\textit{High-side} tranzistor je označován jako plovoucí, protože jeho \textit{Source} elektroda není přímo spojen se zemí,
ale je připojen k zátěži a \textit{low-side} tranzistoru.
Proto je výhodnější použít speciálně navržené budiče.
Pro otevření \textit{low-side} tranzistoru by stačil i napěťově zesílený signál z mikrokontroléru, což neplatí pro \textit{high-side} tranzistor.
Podmínka pro otevření libovolného \textit{MOSFET} tranzistoru je:

\begin{equation}
	U_{G} > U_{T} + U_{S}
\end{equation}

kde:

\begin{itemize}
	\item \(U_{G}\): Napětí na gate elektrodě tranzistoru.
	\item \(U_{T}\): Prahové napětí \textit{MOSFET} tranzistoru, tj. napětí při kterém se začíná otevírat (konstanta součástky).
	\item \(U_{S}\): Napětí na source elektrodě transistoru.
\end{itemize}

Pro \textit{high-side} tranzistor H-můstku platí:

\begin{equation}
	U_{GSH} > U_{T} + U_{LOAD} + U_{LS\_MOSFET}
\end{equation}

kde:

\begin{itemize}
	\item \(U_{LOAD}\): Napětí na zátěži.
	\item \(U_{LS\_MOSFET}\): Napětí na \textit{low-side} tranzistoru.
\end{itemize}

Pro plné otevření tranzistoru je nutné napětí výrazně vyšší než prahové napětí \(U_{T}\).
Tranzistory \textit{ISC080N10} jsou podle datasheetu plně otevřeny při \(U_{GS} = \SI{10}{\volt}\),
přičemž \(U_{GSMAX} = \SI{20}{\volt}\) (viz \cite{ISC080N10NM6_ds}).
Pro plné otevření tedy platí:

\begin{equation}
	U_{GSH} \ge \SI{10}{\volt} + U_{LOAD} + U_{LS\_MOSFET} < \SI{20}{\volt}
	\label{eq:mosfet_hs_opening_floatin}
\end{equation}

Napětí na zátěži \(U_{LOAD}\) a napětí na \textit{low-side} tranzistoru \(U_{LS\_MOSFET}\) jsou závislé na velikosti proudu protékajícího zátěží.
Z rovnice \eqref{eq:mosfet_hs_opening_floatin} vyplývá,
že i napětí potřebné pro otevření \textit{high-side} tranzistoru \(U_{GSH}\) se mění (plave), odtud název „plovoucí“ tranzistor.
Jednou z nejčastěji používaných metod,
jak splnit nerovnici \eqref{eq:mosfet_hs_opening_floatin},
je použití \textit{bootstrap} kondenzátoru a \textit{bootstrap} diody.

Bootstrap kondenzátor slouží jako zdroj napětí pro \textit{high-side} \textit{CMOS} budič,
který je v tomto případě integrován v \textit{MP1917}.
Kondenzátor musí být jednou elektrodou připojen přes \textit{bootstrap} diodu k napájecímu napětí budiče a
druhou elektrodou k potenciálu sourcu \textit{MOSFET} tranzistoru,
respektive k potenciálu zátěže.
Na obrázku \ref{fig::bootstrap_explained_LS_ON} je vidět,
že při sepnutí \textit{low-side} tranzistoru protéká zátěží proud \(I_{LOAD}\) a na zátěži vzniká úbytek \(U_{LOAD}\).
Zároveň je nabíjen \textit{bootstrap} kondenzátor napájecím napětím budiče,
v \oref{fig::bootstrap_explained_LS_ON} jako \(U_{DD} = \SI{10}{\volt}\),
přes \textit{bootstrap} diodu na napětí:

\begin{equation}
	U_{BSC} = \SI{10}{\volt} - U_{D} -  U_{LS} \approx \SI{10}{\volt}
	\label{eq:bootstrap_voltage_LSON}
\end{equation}

\begin{figure}[htpb]
	\centering
	
	\caption{Nabíjení \textit{bootstrap} kondenzátoru přes sepnutý \textit{low-side} tranzistor na napájecí napětí budiče (\SI{10}{\volt}).}
	\label{fig::bootstrap_explained_LS_ON}
\end{figure}

Při rozepnutí tranzistoru \textit{LS} přestává být spodní elektroda kondenzátoru uzemněna a dostává se na potenciál zátěže, takže:

\begin{equation}
	U_{BSC} = \SI{10}{\volt} +  U_{LOAD}
	\label{eq:bootstrap_voltage_LSOFF} % Změněno na LSOFF pro konzistenci
\end{equation}

V tomto momentě zabraňuje vybíjení kondenzátoru \textit{bootstrap} dioda a
na \textit{bootstrap} kondenzátoru se udržuje napětí \(U_{DD} + U_{LOAD}\) vůči zemi.
Při sepnutí \textit{high-side} tranzistoru se toto napětí připojí na gate \textit{MOSFET} tranzistoru,
v \oref{fig::bootstrap_explained_LS_ON} označené jako \(U_{G}\),
a do gatu tranzistoru začne protékat vyrovnávací proud \(I_{G}\),
dokud se kapacita \(C_{G}\) nenabije na napětí \(U_{G}\). Tím je zajištěno, že

\begin{equation}
	U_{GS} = U_{BSC} \approx \SI{10}{\volt}
	\label{eq:bootstrap_voltage_lsoff} % Změněno na lsoff pro konzistenci
\end{equation}

a je dosaženo spínání \textit{high-side} tranzistoru.
Z popsaného principu je jasné, že \textit{high-side} tranzistor nemůže být spínán se střídou \SI{100}{\percent},
protože \textit{bootstrap} kondenzátor musí být nabíjen spínáním \textit{low-side} tranzistoru, viz \oref{fig::bootstrap_explained_LS_ON}.
V současnosti jsou \textit{bootstrap} diody běžně integrovány v budičích,
takže při návrhu stačí zvolit vhodný \textit{bootstrap} kondenzátor.

\begin{figure}[htpb]
	\centering
	
	\caption{Sepnutí \textit{high-side} tranzistoru pomocí součtu napětí na \textit{bootstrap} kondenzátoru a napětí zátěže. Směr proudu zátěží \(I_{LOAD}\) zachován z \oref{eq:bootstrap_voltage_LSON}}
	\label{fig::bootstrap_explained_LS_OFF}
\end{figure}

Tranzistory \textit{Infineon ISC080N10} mají téměř dvojnásobnou kapacitu hradla oproti původním Infineon \textit{BSZ0703L} (\emph{MoSeZ} revize A).
Proto bylo nutné přepočítat hodnoty \textit{bootstrap} kondenzátorů pro budiče \textit{MP1917}.
Výpočet minimální kapacity \textit{bootstrap} kondenzátoru \(C_{\textit{bootstrap}}\) se provádí pomocí provnic \eqref{eq:cboot_min_cap} až \eqref{eq:delta_uhs}
převzatých z \cite{bootstrap_moudra}:

\begin{equation}
	C_{\textit{bootstrap}} \geq \frac{Q_{total}}{\Delta U_{BSTQ}}
	\label{eq:cboot_min_cap}
\end{equation}

kde:

\begin{itemize}
	\item \(C_{\textit{bootstrap}}\): Minimální požadovaná kapacita \textit{bootstrap} kondenzátoru.
	\item \(Q_{total}\): Celkový náboj potřebný pro nabití a udržení hradla \textit{MOSFET} tranzistoru v otevřeném stavu.
	\item \(\Delta U_{BSTQ}\): Maximální přípustný pokles napětí na \textit{bootstrap} kondenzátoru během spínacího cyklu.
\end{itemize}

Celkový náboj \(Q_{total}\) se vypočítá podle vztahu:

\begin{equation}
	Q_{total} = Q_G + I_{DDQ} \cdot \frac{D_{max}}{f_{sw}} + I_{BSTQ} \cdot \frac{1-D_{max}}{f_{sw}}
	\label{eq:qtotal}
\end{equation}

kde:

\begin{itemize}
	\item \(Q_G\): Celkový náboj hradla vybraného \textit{MOSFET} tranzistoru.
	\item \(I_{DDQ}\): Klidový (svodový) proud \textit{\textit{high-side}} budiče.
	\item \(I_{BSTQ}\): Klidový (svodový) proud \textit{bootstrap} obvodu budiče.
	\item \(D_{max}\): Maximální střída \textit{PWM} signálu,
	      v desetiném vyjádření (např. 0.985 pro \SI{98.5}{\percent}).
	\item \(f_{sw}\): Spínací frekvence \textit{PWM} signálu.
\end{itemize}

Dosazením konkrétních hodnot z datasheetu \cite{mp1917_ds}:
\(Q_G = \SI{19}{\nano\coulomb}\),
\(I_{DDQ} = \SI{150}{\micro\ampere}\),
\(I_{BSTQ} = \SI{90}{\micro\ampere}\),
\(D_{max} = 0.985\), \(f_{sw} = \SI{100}{\kilo\hertz}\),
lze vypočíst hodnotu celkového \(Q_{total}\) dle rovnice \eqref{eq:qtotal} jako:

takže

\begin{equation}
	Q_{total} = 19 \cdot 10^{-9} + 150 \cdot 10^{-6} \cdot \frac{0,985}{100 \cdot 10^{3}} + 
	90 \cdot 10^{-6} \cdot \frac{1-0,985}{100 \cdot 10^{3}} \approx \SI{20,48}{\nano\coulomb},
\end{equation}

Maximální přípustný pokles napětí na \textit{bootstrap} kondenzátoru \(\Delta V_{BSTQ}\) se určí z rovnice:

\begin{equation}
	\Delta V_{BSTQ} = U_{DD} - U_{DH} - U_{UPFT} = U_{DD} - U_{DH} - U_{UPRT} - U_{HT}
	\label{eq:delta_uhs}
\end{equation}

kde:

\begin{itemize}
	\item \(U_{DD}\): Napájecí napětí budiče hradla \textit{IC}.
	\item \(U_{DH}\): Úbytek napětí na \textit{bootstrap} diodě.
	\item \(U_{UPFT}\): Prahová hodnota podpěťové ochrany budiče při poklesu napětí na napájecím pinu.
	\item \(U_{UPRT}\): Prahová hodnota podpěťové ochrany budiče při náběhu napětí na napájecím pinu.
	\item \(U_{HT}\): Hystereze podpěťové ochrany budiče.
\end{itemize}

Dosazením konkrétních hodnot z datasheetu \cite{mp1917_ds}:
\(U_{DD} = \SI{11}{\volt}\),
\(U_{DH} = \SI{0,95}{\volt}\),
\(U_{UPRT} = \SI{7,2}{\volt}\),
\(U_{HT} = \SI{0,5}{\volt}\),
lze vypočíst hodnotu celkového \(U_{BSTQ}\) dle rovnice \eqref{eq:delta_uhs} jako:

\begin{equation}
	\Delta U_{BSTQ} = 11 - 0,95 - 7,2 - 0,5 = \SI{2,35}{\volt}.
\end{equation}

Výpočet minimální kapacity \textit{bootstrap} kondenzátoru \(C_{\textit{bootstrap}}\) dle rovnice \eqref{eq:cboot_min_cap}:

\begin{equation}
	C_{\textit{bootstrap}} \geq \frac{\SI{20,48}{\nano\coulomb}}{\SI{2,35}{\volt}} \approx \SI{8,71}{\nano\farad}.
\end{equation}

Pro zajištění dostatečné funkční rezervy byl v obvodu zvolen \textit{bootstrap} kondenzátor s kapacitou \SI{22}{\nano\farad}.
Je však důležité poznamenat, že volba příliš vysoké kapacity \textit{bootstrap} kondenzátoru není žádoucí.
S rostoucí kapacitou se totiž zvyšuje náchylnost k oscilacím na hradle tranzistorů během spínání a rozpínání,
což je způsobeno vznikem rezonancí s parazitními indukčnostmi v budicím obvodu, viz \cite{bootstrap_moudra}.

Naopak, nedostatečná kapacita \textit{bootstrap} kondenzátoru by mohla vést k neúplnému otevření hradla tranzistoru,
a tím ke zvýšení jeho spínacího odporu a ztrátového výkonu.
Zvýšené ztráty by se mohly projevit nepřijatelným zahříváním tranzistorů a potenciálně i jejich poškozením tepelným průrazem.
Pro potlačení oscilací na hradle tranzistoru se doporučuje zařadit tlumící odpor sériově mezi výstup budiče a hradlo tranzistoru.
Tlumící účinek rezistoru se zvyšuje s jeho odporem,
nicméně příliš vysoká hodnota tlumícího odporu zpomaluje nabíjení a vybíjení hradla,
prodlužuje spínací časy a opětovně zvyšuje spínací ztráty.

\section{Měření výstupního proudu}
\label{section::current_meassure}

Pro měření proudu je použit integrovaný obvod \textit{INA241},
což je vysoce přesný obousměrný senzor proudu s pevně nastaveným zesílením.
Tento senzor umožňuje měřit úbytek napětí na snímacích rezistorech v širokém rozsahu souhlasného napětí,
konkrétně od \SI{-5}{\volt} do \SI{110}{\volt},
a to zcela nezávisle na napájecím napětí obvodu.

Vysoká přesnost měření je u obvodu \textit{INA241} zajištěna zejména nízkým vstupním offsetem,
který dosahuje maximálně \SI{\pm10}{\micro\volt},
vysokým poměrem potlačení souhlasného signálu (\textit{CMRR}) pro stejnosměrný proud, typicky \SI{166}{\decibel},
a efektivní schopností potlačení rušení \textit{PWM} signálem díky speciální vnitřní konstrukci,
která by měla minimalizovat přenos rušení, generovaného spínáním tranzistorů, na vstup měřicího obvodu.

\subsection{Napěťová reference}
\label{section::voltage_ref}

Obvod \textit{INA241B1} umožňuje použití vnitřního nebo vnějšího referenčního napětí.
Vnitřní referenční zdroj se aktivuje ponecháním pinů \textit{REF1} a \textit{REF2} nezapojených.
V tomto režimu je výstupní napětí při nulovém proudu rovno polovině napájecího napětí,
což znamená, že výstup je přirozeně ratiometrický – jeho hodnota se mění v závislosti na napájecím napětí.

Bohužel, AD převodníky integrované v mikrokontroléru \textit{ATSAME51J20A} se
dostávají do saturace při napětích vyšších než \SI{2,5}{\volt},
což omezuje využití plného rozsahu výstupu obvodu \textit{INA241B1} při použití vnitřní reference.
Z tohoto důvodu bylo zvoleno zapojení s externí referencí, kde
\textit{REF1} je připojen na výstup přesné napěťové reference a \textit{REF2} je uzemněn.
Tím se výstupní napětí při nulovém proudu posouvá na polovinu napětí referenčního zdroje.
Použitím externí referenční napěťové reference \textit{MCP1501T-25E} s hodnotou \SI{2.5}{\volt}
je pracovní bod výstupu nastaven na \SI{1.25}{\volt} při nulovém vstupním proudu.

Pokud je stejné referenční napětí \SI{2.5}{\volt} použito jako referenční vstup pro AD převodník mikrokontroléru,
je opět zajištěn ratiometrický převod.
To znamená, že výstupní napětí zesilovače i referenční napětí AD převodníku jsou vzájemně proporcionální ke stejnému zdroji,
čímž se eliminuje vliv kolísání napájecího napětí na výsledek měření.

\subsection{Snímací rezistor}

Při výpočtu snímacího rezistoru měření proudu vycházíme z maximálního proudu zátěží,
\(I_{\text{LOAD\_MAX}}\), který je specifikován v zadání úlohy jako \SI{10}{\ampere}.
Dále je nezbytné definovat maximální přípustný výkon, \(P_{D\_MAX}\),
který se bude vyzařovat na snímacím rezistoru.
Obecně platí, že s rostoucím odporem snímacího rezistoru klesají nároky na zesílení zesilovače,
což typicky vede k vyšší přesnosti měření.
Hlavní nevýhodou většího odporu je však nárůst ztrátového výkonu,
který se musí vyzářit, což má negativní dopad na celkovou účinnost systému.

Předpokládejme, že maximální přípustný ztrátový výkon je stanoven na \(P_{D\_MAX} = \SI{0,5}{\watt}\).
Tato hodnota představuje rozumný kompromis, kdy vyzářené teplo lze ještě efektivně odvádět.
V dalším kroku určíme maximální přípustnou velikost snímacího rezistoru, \(R_{\text{SENSE}_\text{MAX}}\), z hlediska ztrátového výkonu:

\begin{equation}
	\label{eq::eq_rsense_maxR}
	R_{\text{SENSE\_PMAX}} = \frac{P_{D\_MAX}}{I_{\text{LOAD\_MAX}}} = \frac{0,5}{10} = \SI{50}{\milli\ohm},
\end{equation}

Pak je nutné zvolit odpor, jehož velikost bude menší než \(R_{\text{SENSE}\_MAX}\)
a který v kombinaci se zesílením \(G\) plně využije dynamický rozsah následujících obvodů.
V tomto konkrétním případě následuje \textit{AD} převodník integrovaný v mikrokontroléru s rozsahem \SI{0}{\volt} až \SI{2,5}{\volt}.
Pro nulový proud je však výstupní napětí zesilovače \textit{INA241} (\(U_{OUT}\)) nastaveno na \SI{1,25}{\volt}
díky napěťové referenci \(U_{REF}\) (viz \nameref{section::voltage_ref}).
Efektivní napěťový rozsah pro měření proudu v jednom směru je tedy \(U_{RANGE} = \SI{1.25}{\volt}\).
Obvod \textit{INA241} se vyrábí s různými zesíleními \(G\). Pro úvodní výpočet zvolíme nejmenší dostupné zesílení, a to \(G = 10 \cdot\).

\begin{equation}
	\label{eq::eq_rsense_maxURANGE}
	R_{\text{SENSE\_UMAX}} = \frac{U_{RANGE}}{I_{\text{LOAD\_MAX}} \cdot G} = \frac{1,25}{10 \cdot 10} = \SI{12,5}{\milli\ohm},
\end{equation}

Pokud nepplatí, že:

\begin{equation}
	\label{eq::eq_rsense_check_PMAX}
	R_{\text{SENSE\_UMAX}} \le R_{\text{SENSE\_PMAX}},
\end{equation}

je nutné přistoupit k úpravě návrhu.
Jednou z možností je volba zesilovače s větším zesílením \(G\).
Alternativně lze zvážit i navýšení maximálního přípustného ztrátového výkonu \(P_{D\_MAX}\).
V tomto konkrétním případě však nerovnice \eqref{eq::eq_rsense_check_PMAX} platí s dostatečnou rezervou ztrátového výkonu.
Proto postačí nalézt nejbližší menší standardně vyráběný snímací odpor, kterým je v tomto případě \SI{12}{\milli\ohm}.

Po zvolení odporu \(R_{SENSE} = \SI{12}{\milli\ohm}\) je klíčové vypočítat citlivost měření proudu v jednotkách \SI{}{\volt/\ampere}.
Znalost citlivosti je nezbytná pro následný výpočet aktuálního proudu z naměřeného výstupního napětí na obvodu \textit{INA241B1},
respektive z napětí na \textit{AD} převodníku mikrokontroléru.
Tuto citlivost lze stanovit z rovnice:

\begin{equation}
	\label{eq::sensitivity_INA}
	\text{Citlivost} = \frac{U_{RANGE}}{I_{\text{LOAD\_MAX}}} = \frac{1,25}{10} = \SI{0,125}{\volt/\ampere}.
\end{equation}

takže

\begin{equation}
	\label{eq::sensitivity_INA_val}
	Citlivost = \SI{0,12}{\volt/\ampere},
\end{equation}

\subsection{Filtrování napětí na snímacím odporu}

Pro eliminaci nežádoucího rušení v měřeném napětí na snímacím rezistoru \(R_{SENSE}\) se v obvodu používají dva typy dolnopropustných filtrů:

\begin{enumerate}
	\item \textit{Common-mode} filtr – Tento typ filtru je určen k potlačení rušení,
	      které je společné pro oba vstupy měřicího obvodu.
	      Jinými slovy, potlačuje rušení, které se na obou vstupech objevuje ve stejné fázi.
	      Hlavními zdroji rušení jsou kapacitní vazba mezi spínacími tranzistory H-můstku a zemí,
	      elektromagnetické rušení (EMI) a nekvalitní zemnění.
	\item \textit{Differential-mode} filtr – Tento typ filtru slouží k potlačení rušení,
	      které se projevuje jako rozdíl mezi napětími na obou vstupech měřicího obvodu.
	      Toto rušení se na obou vstupech objevuje se stejnou amplitudou, avšak v opačné fázi.
	      Hlavním zdrojem jsou rychlé změny proudu při spínání tranzistorů H-můstku,
	      které způsobují napěťové přechody na tomto snímacím rezistoru.
\end{enumerate}

Zlomová frekvence \textit{Common-mode} filtru, označená \(f_{CM}\), se vypočítá dle následujícího vztahu:

\begin{equation}
	f_{CM} = \frac{1}{2 \pi R_{CM} C_{CM}}
\end{equation}

kde:

\begin{itemize}
	\item \(f_{CM}\): Zlomová frekvence \textit{Common-mode} filtru.
	\item \(R_{CM}\): Hodnota odporu použitého v \textit{Common-mode} filtru.
	\item \(C_{CM}\): Hodnota kapacity použitého v \textit{Common-mode} filtru.
\end{itemize}

Pro hodnoty součástek \(R_{CM} = \SI{2.2}{\kilo\ohm}\) a \(C_{CM} = \SI{1}{\nano\farad}\) získáme:

\begin{equation}
	f_{CM} = \frac{1}{2 \pi \cdot \SI{2.2}{\kilo\ohm} \cdot \SI{1}{\nano\farad}} \approx \SI{72}{\kilo\hertz}.
\end{equation}

Vzhledem k charakteru rušení je nezbytné aplikovat \textit{Common-mode}
filtr na oba vodiče vedoucí od snímacího rezistoru.
Schéma zapojení filtru je detailněji znázorněno v \pref{priloha:schema_CurrentOutput}.

Zlomová frekvence \textit{Differential-mode} filtru, označená \(f_{DM}\), se vypočítá dle následujícího vztahu:

\begin{equation}
	f_{DM} = \frac{1}{2 \pi R_{DM} C_{DM}} =  \frac{1}{2 \pi (2 \cdot R_{CM}) C_{DM}}
\end{equation}

kde:

\begin{itemize}
	\item \(f_{DM}\): Zlomová frekvence \textit{Differential-mode} filtru.
	\item \(R_{DM}\): Hodnota odporu použitého v \textit{Differential-mode} filtru. V zapojení, kde odpory \(R_{CM}\) tvoří část \textit{Differential-mode} filtru, je \(R_{DM}\)  paralelní kombinací \(R_{CM} || R_{CM} = \frac{R_{CM}}{2}\).
	\item \(C_{DM}\): Hodnota kapacity použitého v \textit{Differential-mode} filtru.
\end{itemize}

Pro hodnoty součástek \(R_{DM} = \SI{4.4}{\kilo\ohm}\) a \(C_{DM} = \SI{1}{\nano\farad}\) dostaneme:

\begin{equation}
	f_{DM} = \frac{1}{2 \pi \cdot \SI{4.4}{\kilo\ohm} \cdot \SI{1}{\nano\farad}} \approx \SI{36}{\kilo\hertz}.
\end{equation}

\begin{figure}[htpb]
	\centering
	
	\caption{Útlumové charakteristiky pro dolnopropustné filtry prvního řádu \textit{CM} a \textit{DM} připojené mezi diferenciální zesilovač \textit{INA241B1} a snímací odpor}
	\label{fig::LP_filtter}
\end{figure}

Frekvence užitečného signálu by měla být menší než  \(\frac{1}{10}\) nejnižší mezní frekvence z obou filtrů.
To je jeden z důvodů, proč je v řešení \nameref{section::dds_implementation} maximální nastavitelná frekvence výstupního proudu stanovena na \SI{3}{\kilo\hertz}, 
vyznačená v amplitudové charakteristice na \oref{fig::LP_filtter}.
Maximální reálná frekvence bude ovlivněna indukčností zátěže.

\section{CAN Bus Driver}
\label{section::CAN_Bus_Driver}

Při vedení vodivých cest pro \textit{CAN bus} byly využity diferenciální páry s řízenou diferenciální impedancí o velikosti \SI{120}{\ohm}. 
Každá deska má dva možné způsoby připojení ke sběrnici \textit{CAN}. 
První je přes \textit{\textit{THT} pass throug header}, 
kde se desky skládáním do sebe automaticky připojí k \textit{CAN} sběrnici, viz zelený rámeček v \oref{fig::CAN_connector}. 
Druhou možností jsou dva konektory, kde jeden slouží jako vstup a druhý jako výstup \textit{CAN} sběrnice, viz bílý rámeček v \oref{fig::CAN_connector}. 
Vzhledem k tomu, že sběrnice vzniká skládáním desek, je důležité vyřešit její terminaci.

\begin{figure}[htpb]
	\centering
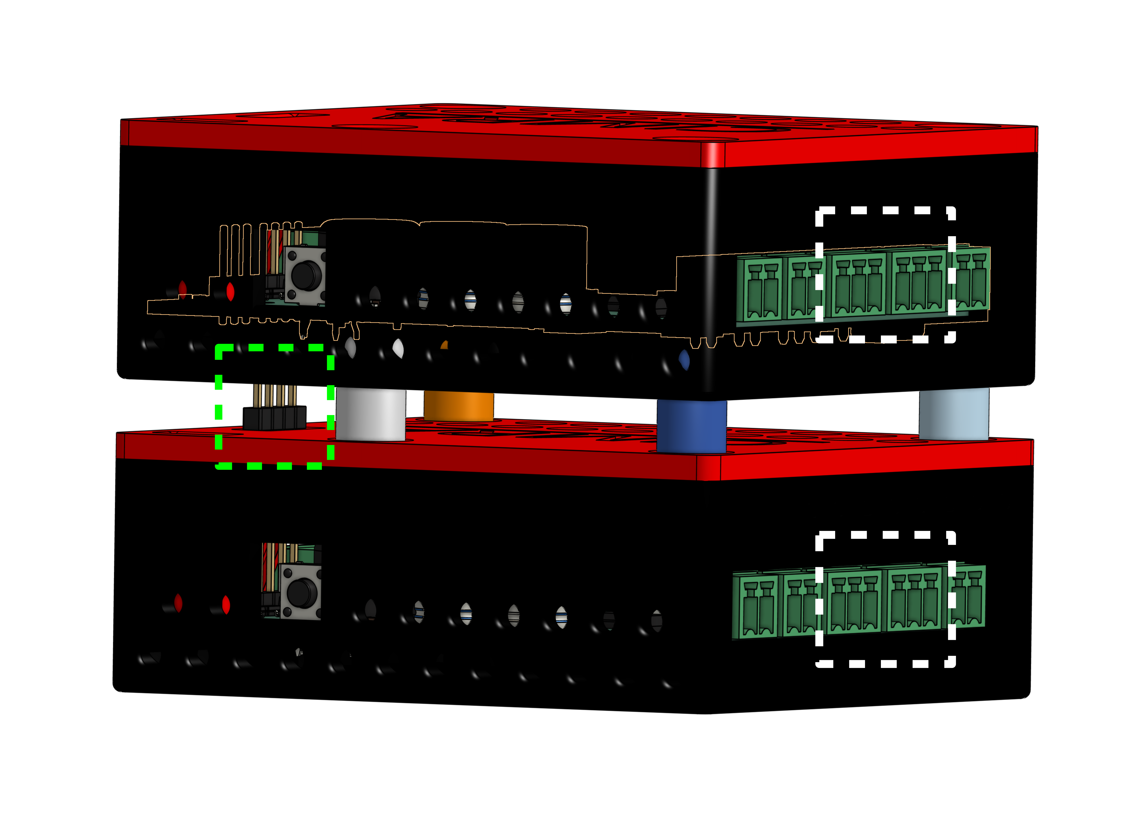
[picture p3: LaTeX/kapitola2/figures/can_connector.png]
	
	\caption{Možnosti připojení ke \textit{CAN} sběrnici, \textbf{zelený} rámeček \textit{\textit{THT} pass throug header}, přes konektory v  \textbf{bílém} rámečku}
	\label{fig::CAN_connector}
\end{figure}	

Na desce nejsou přítomny žádné terminační odpory, a to z toho důvodu, že terminační odpory by měly být přítomny pouze na začátku a 
konci sběrnice.
Vzhledem ke konstrukci, kdy sběrnice vzniká skládáním desek, 
by terminační odpor měla obsahovat pouze první a poslední deska na sběrnici. 
Aby mohly být všechny desky plošných spojů stejné, tj. bez vytváření dedikovaných terminačních desek \textit{MoSeZ}, 
respektive desek, které mají terminační odpory připájené, bylo rozhodnuto, že terminační odpory se budou na první a 
poslední desku připojovat do jednoho z \textit{CAN} konektorů, viz bílý rámeček v \oref{fig::CAN_connector}.

\section{Interface}

Každý ze vstupů je chráněn \textit{TVS} diodami proti přepětím, 
zejména proti \textit{ESD}.
Pro zajištění dobré funkce \textit{TVS} diod je nutné je umístit co nejblíže ke konektorům a headerům.
V nové revizi je možnost měřit až dva analogové signály s rozsahem \SIrange{0}{2,5}{\volt} připojené k desce.
Hlavním záměrem je možnost zavedení informace o stavu aktuátorů do zpětné vazby regulátoru.
Toho se v této práci využívá při sledování polohy jádra voicecoilu pomocí vhodně umístěného hallova senzoru, viz \nameref{sec::voicecoil_function}.
Ovšem lze tyto vstupy využít pro měření libovolného analogového napětí v rozsahu \SI{3,3}{\volt}.

Ze staré revize zůstávají dva napájecí dvoupinové konektory, dva \textit{CAN} třípinové konektory, 
jeden dvoupinový konektor pro proudový výstup, 
třípinový header pro komunikaci přes \textit{UART} a jeden čtyřpinový header pro rozvod \textit{CAN} a napětí \SI{3,3}{\volt}.

\begin{figure}[htpb]
    \centering
    
    \caption{Přední strana DPS MoSeZ rev. B, zadní strana DPS viz příloha A: \nameref{priloha:pcb_back}}
    \label{fig::mosez_pcb_front}
\end{figure}

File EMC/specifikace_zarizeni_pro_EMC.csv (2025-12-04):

ETL - Elektrotechnická laboratoř, akreditovaná zkušební laboratoř dle ČSN EN ISO/IEC 17025:2018 ETL - Electrical Laboratory, accredited by ČIA according to ČSN EN ISO/IEC 17025:2018
tab_2022/01
Specifikace zařízení pro zkoušky elektromagnetické kompatibility Specifications of tested subject for EMC tests
Prosíme o doplnění tabulky (žlutá pole). U některých položek je vytvořen rozbalovací seznam pro rychlejší vyplnění, případně jsou předvyplněny vzorovým příkladem. Please fill the table (yellow fields). A drop-down list is created for some items for faster completion, or some fields are pre-filled with a an example.
Po vyplnění tabulek budeme schopni vytvořit adekvátní nabídku na Vaše zařízení. We will be able to create an adequate offer for your device after filling of the tables.
Poptávající: Costumer: | nextdrop s.r.o.
Adresa: Address: | Cukrovarská 3006/20, Jižní Předměstí, 301 00 Plzeň
IČ / DIČ: VAT number: | 10818065 |  | CZ
Název zařízení: Device name: | Řídící jednotka elektromagnetického ventilu
Sériové číslo*1): Serial number: | EMC prototyp 01
Verze HW: HW version: | 2.0
Verze FW / SW: FW / SW version: | 2.01
*1) V případě, že zařízení nemá přiřazené sériové číslo, uveďte označení prototypu (např. EMC protoyp 01). When the tested device doesn´t have a serial number, state the prototype number (f.e. EMC prototype 01).
EMC měření: EMC measurement: | certifikační /compliance
Protokol: Test report: | ano /yes
Jazyk protokolu: Test report language: | česky /Czech
Typ zařízení: Device type: |  |  | Řídící jednotka pro ovládání elektromagnetických aktuátorů a ventilu
Určeno pro prostředí: Intended for environment: |  |  | průmysl /industrial
Rozměry zařízení ŠxVxH: Device dimension Equipment WxHxD: |  |  | cca /approx 0,062 x 0,076 x 0,018 m
Hmotnost zařízení: Device weight: |  |  | cca /approx 0,1 kg
Napájení zařízení: Powered from: |  |  | DC jiné /DC different
 | Specifikovaný AC/DC adaptér*2): Specified AC/DC adapter: |  | ano /yes
 | Typ specifikovaného AC/DC adaptéru*2): AC/DC adapter type: |  | USB-C
Maximální vnitřní pracovní kmitočet zařízení: Max. inner frequency of device: |  |  | > 108 MHz
Možné provozní režimy: Possible operating modes: |  |  | Standby, DC výstup, AC výstup s možným DC offsettem, (harmonický, trojúhelníkový a obdélníkový). Možné ukládání příchozích povelů do paměti (spolu s časovým úsekem, po který by měli být platné) a jejich násedné sekvenční vykonání v pořadí FIFO.
Pomocná zařízení: Auxiliary devices: |  |  | Převodník USB na UART
Zařízení obsahuje magneticky citlivé komponenty: The device contains magnetically sensitive components: |  |  | ne /no
Požadavky na posouzení shody výsledků dle norem (vyberte, případně doplňte požadované): Standards specification: |  | emise: emission: | ČSN EN 55011
 |  | odolnost: susceptibility: | ČSN EN 61000-6-2
*2) Pouze pro DC napájená zařízení. Pokud je specifikovaný AC/DC adaptér, je nutné jej dodat ke zkouškám EMC společně s testovaným zařízením. For DC powered devices only. If an AC / DC adapter is specified, it must be provided for EMC testing with the tested device..
Prosíme o doplnění možných rozhraní dle uvedených vzorů. Pokud je určena maximální délka připojeného kabelu a jeho typ, měl by být uveden v návodu použití výrobku. Please fill all interfaces according to the given patterns. If the length of the connected cable and its type are specified, it should be stated in the product's manual.
Po vyplnění také rovnou uvidíte (orientačně, platí pro zařízení do domácností / průmyslu), jaké testy by se měly na zařízení provést (ANO v zeleném poli). After filling all interfaces, you will also immediately see what tests should be performed on the device (ANO in the green field) (only for guidance, applies to household / industrial equipment)
Rozhraní /Interface |  |  |  |  | Testy odolnosti dle 61000-6-1 / 2 /susceptibility tests according to 61000-6-2 / 2 |  |  |  |  |  |  |  |  | Emise dle 61000-6-3 / 4 /emission
Typ Type | Označení designation | Délka rozhraní possible cable lenght | Typ kabelu cable type | Kabel připojený během měření Cable is connected during tests | 61000-4-2 | 61000-4-3 | 61000-4-4 | 61000-4-5 | 61000-4-6 | 61000-4-8 | 61000-4-11 | 61000-4-12 | 61000-4-18 | Vzduchem radiated | napěťově conducted | proudově conducted
kryt | – | – | – | – | ANO | ANO | – | – | – | NE | – |  |  | ANO | – | –
vstup DC 24 V |  | < 3 m | nestíněný /unshielded | ano /yes | – | – | ANO* | ANO* | ANO* | – | NE |  |  | – | ANO | NE
vstup analogový ADC 1 |  | < 3 m | stíněný /shielded | ano /yes | – | – | ANO* | ANO* | ANO* | – | NE |  |  | – | ANO | NE
vstup analogový ADC 2 |  | < 3 m | stíněný /shielded | ne /no | – | – | NE | NE | NE | – | NE |  |  | – | ANO | NE
RS232-2 | – | < 3 m | nestíněný /unshielded | ano - servisní port /yes - service port | – | – | NE | NE | NE | – | NE |  |  | – | NE | ANO
výstup DC nebo AC max 10 A |  | < 3 m | stíněný /shielded | ano /yes | – | – | ANO | ANO | ANO | – | NE |  |  | – | ANO | NE
CAN |  | < 30 m (neopouští budovu) /not leave building | stíněný+kroucený pár /shielded twisted pair | ano /yes | – | – | ANO | NE | ANO | – | NE |  |  | – | NE | ANO
* Pokud je specifikován AC/DC napájecí adaptér, poté je testováno na AC straně tohoto adaptéru If the AC/DC adapter is specified, then the test is performed ad AC side of the adapter.
V případě potřeby dalších rozhraní prosím zkopírujte řádky If you need add next interfaces, please copy the lines
Poznámka / doplňující informace pro laboratoř: Note / additional information to the laboratory:
Pokud byste chtěli upřesnit některé chybějící informace… Sběrnice CAN je vyvedena také na 4 pinový header. Jeden stíněný kabel připojuje proudový výstup k zátěži a případnou zpětnou vazbu (např poloha ventilu, apod.) ze zátěže na analogové konektory (ADC1, ADC2) zpět do zdroje.

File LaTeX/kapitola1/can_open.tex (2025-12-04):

\newpage

\chapter{Komunikační protokoly založené na sběrnici \textit{\textit{CAN} }}

Sběrnice \textit{CAN} (Controller Area Network) byla původně vyvinuta společností Bosch pro automobilový průmysl jako řešení rostoucí složitosti kabelových rozvodů.
Její robustní návrh a efektivita vedly k širokému nasazení i v dalších oblastech průmyslové automatizace.
Mezi klíčové vlastnosti této sběrnice patří:

\begin{itemize}
	\item \textbf{Robustní fyzická vrstva:}  Je navržen pro spolehlivý provoz v náročných průmyslových prostředích.
	\item \textbf{Nízká režie:} Protokol  má relativně nízkou režii, což znamená efektivní využití přenosového média.
	\item \textbf{Jednoduché rozhraní:} Implementace  nevyžaduje rozsáhlé hardwarové prostředky,
	      často postačuje i méně výkonný 8-bitový mikroprocesor s malou pamětí (řádově \SI{4}{\kilo\byte} programové paměti a \SI{256}{\byte} \textit{RAM}).
	\item \textbf{Bitová arbitráž:}  Využívá nedestruktivní bitovou arbitráž pro řízení přístupu k síti.
	      Pokud více uzlů započne vysílání současně, arbitrážní mechanismus zajistí,
	      že zpráva s vyšší prioritou (definovanou identifikátorem) získá přístup k sběrnici bez ztráty dat.
	      Vítězný uzel pokračuje ve vysílání, zatímco ostatní uzly, které prohrály arbitráž, se stáhnou a čekají na uvolnění sběrnice.
	      Uzel může započít vysílání jen pokud je sběrnice uvolněna.
	      Pokud začne uzel s vyšším \textit{ID} (nižší prioritou) úspěšně vysílat,
	      musí všechny ostatní uzly čekat na uvolnění sběrnice,
	      bez ohledu na jejich \textit{ID} (prioritu).
	\item \textbf{Datové a vzdálené rámce:}  Definuje formáty zpráv,
	      jako je datový rámec (pro přenos dat) a vzdálený rámec (pro vyžádání dat).
	\item \textbf{Řízení chyb:}  Zahrnuje mechanismy pro detekci a signalizaci chyb při přenosu dat.
\end{itemize}

Původní specifikace \textit{CAN} (verze 1.2) používala \SI{11}{\bit} identifikátor,
umožňující adresovat až 2047 různých zařízení nebo zpráv.
Pozdější specifikace \textit{CAN} 2.0 rozšířila velikost identifikátoru na \SI{29}{\bit},
což zvýšilo počet unikátních možností adresace na více než $\approx$ 536 milionů.
Většina bitů identifikátoru slouží k logickému rozdělení zpráv do skupin, což je výhodné v komunikačních protokolech založených na \textit{CAN},
jako je \textit{CANopen} \cite{canopen_spec}.

\section{\textit{CANopen}}

\textit{CANopen} je nadstavbový komunikační protokol založený na sběrnici \textit{CAN} (\textit{Controller Area Network}).
Byl vyvinut organizací \textit{CiA} (\textit{CAN in Automation}) pro potřeby průmyslové automatizace, ale našel uplatnění i v dalších odvětvích,
jako jsou zdravotnická technika, dopravní systémy, robotika a řízení strojů.
Díky své otevřené architektuře, modularitě a široké podpoře je \textit{CANopen} vhodný pro aplikace,
které vyžadují spolehlivou a efektivní komunikaci mezi decentralizovanými inteligentními zařízeními.

\subsection{Fyzická vrstva a topologie}
\textit{CANopen} využívá fyzickou vrstvu standardu \textit{CAN}, což zahrnuje specifikaci kabeláže, zakončení a topologie sítě.

\textbf{Klíčové parametry fyzické vrstvy:}
\begin{itemize}
	\item Používá dvoudrátovou kroucenou dvojlinku (diferenciální přenos).
	\item Podporuje různé rychlosti (od \SI{10}{\text{kbps}} do \SI{1}{\text{Mbps}}).
	\item Sběrnicová topologie s možností odboček (stub lines).
	\item Terminace sběrnice pomocí 120$\Omega$ odporů na koncích vedení.
\end{itemize}

\begin{table}[H]
	\centering
	\caption{Maximální délka sběrnice v závislosti na přenosové rychlosti}
	\begin{tabular}{|c|c|}
		\hline
		\textbf{Rychlost(\SI{}{\text{kbps}})} & \textbf{Max. délka vedení (m)} \\
		\hline
		1000                                  & 40                             \\
		500                                   & 100                            \\
		250                                   & 250                            \\
		125                                   & 500                            \\
		50                                    & 1000                           \\
		20                                    & 2500                           \\
		\hline
	\end{tabular}
\end{table}

\subsection{Komunikační protokoly v \textit{CANopen}}

\textbf{PDO – Process Data Object}
Umožňuje přenos procesních dat mezi zařízeními bez potvrzení, což zajišťuje minimální latenci. Data mohou být synchronní nebo asynchronní.

\textbf{Vlastnosti PDO:}
\begin{itemize}
	\item Maximální velikost dat je \SI{8}{\byte}.
	\item Lze konfigurovat mapování dat.
	\item Přenos může být vyvolán změnou hodnoty nebo synchronizační zprávou (SYNC).
\end{itemize}

\textbf{SDO – Service Data Object}
Umožňuje čtení a zápis dat do objektového slovníku zařízení. Používá se pro konfiguraci a diagnostiku.

\textbf{Princip SDO:}
\begin{itemize}
	\item Každý \textit{SDO} rámec má identifikátor klient-server.
	\item Používá \SI{16}{\bit} index a \SI{8}{\bit} subindex pro adresaci dat.
	\item Podporuje segmentovaný přenos větších datových bloků.
\end{itemize}

\textbf{Další komunikační objekty}
\begin{itemize}
	\item \textbf{NMT (Network Management)} – Řízení stavu zařízení v síti.
	\item \textbf{SYNC} – Synchronizace komunikace mezi uzly.
	\item \textbf{EMCY (Emergency)} – Rychlé hlášení poruch.
	\item \textbf{Heartbeat / Node Guarding} – Monitorování dostupnosti zařízení.
\end{itemize}

\section{Objektový slovník}
Každé zařízení v \textit{CANopen} obsahuje objektový slovník (\textit{Object Dictionary, OD}), který obsahuje konfiguraci a data.

\begin{table}[H]
	\centering
	\caption{Ukázka objektového slovníku \textit{CANopen}}
	\begin{tabular}{|c|c|c|}
		\hline
		\textbf{Index} & \textbf{Název}        & \textbf{Popis funkce}     \\
		\hline
		0x1000         & Device Type           & Typ zařízení              \\
		0x1018         & Identity Object       & ID výrobce, verze SW      \\
		0x6040         & Control Word          & Např. Ovládání motoru     \\
		0x6064         & Position Actual Value & Např. Aktuální poloha osy \\
		\hline
	\end{tabular}
\end{table}

\subsection{Diagnostika a bezpečnost}
\textit{CANopen} obsahuje pokročilé mechanismy pro diagnostiku a detekci chyb:

\textbf{Hlavní diagnostické funkce:}
\begin{itemize}
	\item \textbf{Heartbeat a Node Guarding} – Monitorování aktivních uzlů.
	\item \textbf{EMCY zprávy} – Hlášení chybových stavů.
	\item \textbf{Time-out mechanizmy} – Detekce neodpovídajících zařízení.
\end{itemize}

\begin{table}[H]
	\centering
	\caption{Ukázka chybových kódů EMCY v \textit{CANopen}}
	\begin{tabular}{|c|c|}
		\hline
		\textbf{Kód chyby} & \textbf{Popis chyby} \\
		\hline
		0x8110             & Přepětí na motoru    \\
		0x8120             & Nedostatek napájení  \\
		0x8130             & Přehřátí pohonu      \\
		\hline
	\end{tabular}
\end{table}

\subsection{Aplikace protokolu \textit{CANopen}}
\textit{CANopen} je široce využíván v různých průmyslových odvětvích:

\begin{itemize}
	\item \textbf{Automatizace strojů} – Řízení motorů, snímačů a akčních členů.
	\item \textbf{Automobilový průmysl} – Ovládání vestavěných systémů a komunikace mezi moduly.
	\item \textbf{Zdravotnická technika} – Řízení laboratorních přístrojů, dávkovacích systémů.
	\item \textbf{Robotika} – Koordinace pohybu víceosých systémů.
\end{itemize}

\textit{DeviceNet} staví na základech protokolu \textit{CAN},
sériové komunikační normy určené pro inteligentní zařízení.

\section{\textit{DeviceNet}}

Je průmyslový komunikační protokol vytvořený společností Allen-Bradley,
který si od svého vzniku v polovině 90. let 20. století získal důležité postavení v oblasti automatizace.
Jeho popularita spočívá v možnosti spolehlivě propojovat různá průmyslová zařízení obdobně jako u \textit{CANopen}.
Je součástí rodiny sítí,
které na svých vyšších vrstvách implementují \textit{Common Industrial Protocol} (\textit{CIP}),
standardizovaný protokol pro průmyslovou automatizaci.

Kromě \textit{DeviceNet} do této rodiny \textit{CIP} protokolů patří i další významné technologie, jako například:

\begin{itemize}
	\item \textbf{\textit{\textit{EtherNet/IP} }}: Průmyslový ethernetový protokol, který rozšiřuje \textit{CIP} na standardní ethernetovou infrastrukturu.
	      Je široce používán pro aplikace vyžadující vysokou rychlost a velkou šířku pásma.
	\item \textbf{\textit{ControlNet}}: Síť s deterministickým přístupem k médiu,
	      určená pro aplikace vyžadující vysokou spolehlivost a synchronizaci v reálném čase, typicky pro řízení a \textit{I/O} data.
	\item \textbf{\textit{CompoNet}}: Nízkonákladová průmyslová síť určená pro propojení jednoduchých zařízení,
	      jako jsou senzory a akční členy.
\end{itemize}

\begin{figure}[htbp]
	\centering
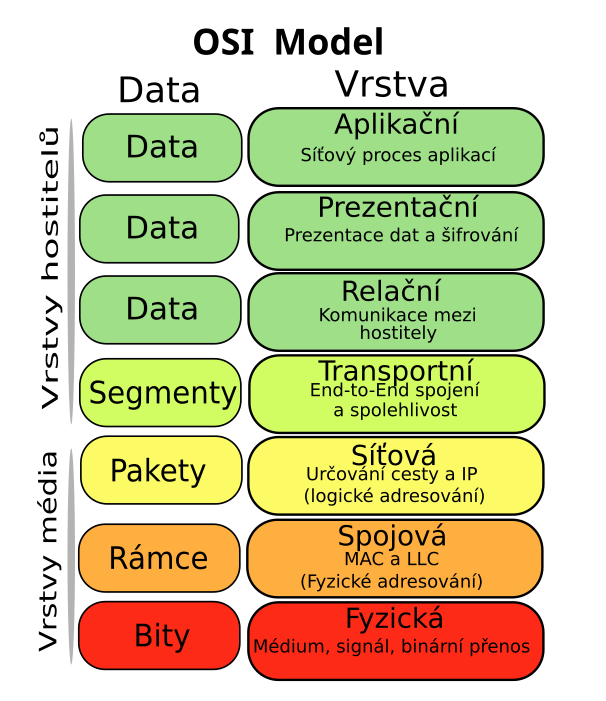
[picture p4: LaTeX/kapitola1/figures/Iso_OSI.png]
	
	\caption[Referenční model \textit{ISO/OSI}]{Referenční model \textit{ISO/OSI}. Zdroj: \cite{osi_model_wiki}}
	\label{fig::isoosi}
\end{figure}

Všechny tyto sítě sdílejí společný \textit{CIP} na svých aplikačních vrstvách,
což umožňuje jednotný přístup k datům a konfiguraci zařízení napříč různými typy sítí.
Z hlediska referenčního modelu \textit{ISO/OSI}, viz \oref{fig::isoosi}, definuje \textit{DeviceNet} síťovou, transportní vrstvu, linkovou a fyzickou vrstvu,
ve kterých sběrnice \textit{CAN} zajišťuje dvě nejnižší vrstvy – fyzickou a linkovou \cite{devicenet_spec}.
Zprávy obsahují specifické informace uspořádané do definovaných polí, jako je číslo třídy objektu a kód služby.

\subsection{\textit{CIP} (\textit{Common Industrial Protocol})}

Je komplexní komunikační protokol umožňující výměnu automatizačních dat mezi zařízeními,
kde každé zařízení je reprezentováno jako sada objektů.

\textbf{Typy objektů v \textit{CIP}:}
\begin{itemize}
	\item \textbf{Požadované objekty (Required Objects)} – Identity Object, Message Router Object, Network Object, Connection Object.
	\item \textbf{Aplikační objekty (Application Objects)} – specifické pro funkci daného zařízení (např. motor, analogový vstup).
	\item \textbf{Objekty sestavení (Assembly Objects)} – sdružují atributy z různých aplikačních objektů.
	\item \textbf{Objekty specifické pro výrobce (Vendor Specific Objects)} – pro dodatečné funkce zařízení.
\end{itemize}

\subsection{Komunikační protokoly v \textit{CIP}:}
\begin{itemize}
	\item \textbf{Explicitní zprávy} - Požadavek/odpověď, např. pro konfiguraci zařízení.
	\item \textbf{\textit{I/O} zprávy} - Přenos výstupů a vstupů mezi master a slave.
	      \begin{itemize}
		      \item \textbf{Dotazování (Polled)} - Master se pravidelně ptá slave.
		      \item \textbf{Cyklické zprávy} - Slave pravidelně vysílá data.
		      \item \textbf{Při změně stavu (Change-of-State)} - Data se přenášejí pouze při změně nebo v intervalech.
	      \end{itemize}
\end{itemize}

\subsection{Architektura sítě \textit{DeviceNet}}

\textit{DeviceNet} využívá sběrnicovou topologii s hlavním vedením (trunk line) a odbočkami (drop line).
Maximální počet uzlů je 64, s adresami 0-63.
Podporované rychlosti jsou \SI{125}{\text{kbps}},  \SI{250}{\text{kbps}} a  \SI{500}{\text{kbps}},
přičemž rychlost ovlivňuje maximální délku vedení.
Terminace probíhá pomocí  \SI{125}{\ohm} odporů na koncích trunk line.
Konfigurace zařízení probíhá softwarově nebo pomocí specializovaných hardware nástrojů.
Při zapnutí nového uzlu v síti probíhá automatická detekce duplicitních adres, což zabraňuje konfliktům.

\section{\textit{Ethernet} v průmyslových aplikacých}

V dnešní době se stále více používají \textit{Ethernetové} technologie v průmyslových aplikacích,
a proto uznávám za vhodné uvést i protokoly založené na \textit{Ethernetu} a
následně je porovnat s protokoly založenými na sběrnici \textit{CAN}.
Mezi nejpoužívanější protokoly patří \textbf{\textit{EtherNet/IP} }, \textbf{\textit{PROFINET} } a \textbf{\textit{EtherCAT} }.
Každý z nich má své specifické vlastnosti, které je činí vhodnými pro různé aplikace.

\subsection{\textit{EtherNet/IP} }
\textit{EtherNet/IP} je průmyslový síťový protokol využívající standardní protokol \textit{Common Industrial Protocol (CIP)}.
Tento protokol umožňuje komunikaci mezi řídicími systémy a (\textit{I/O}) zařízeními.

\textbf{Hlavní vlastnosti:}
\begin{itemize}
	\item Pracuje na aplikační vrstvě \textit{OSI}.
	\item Používá standardní síťovou infrastrukturu Ethernet (\textit{IEEE 802.3}).
	\item Podporuje komunikaci producent-konzument (\textit{producer-consumer}).
	\item Používá standardní \textit{Ethernetové} přepínače a směrovače.
	\item Využívá protokoly \textit{TCP/IP} pro explicitní zasílání zpráv a \textit{UDP} pro rychlou výměnu dat.
\end{itemize}

\subsection{\textit{PROFINET} }
\textit{\textit{PROFINET} } je průmyslový komunikační protokol vyvinutý z \textit{PROFIBUSu}.
Protokol je standardizován a rozšiřuje možnosti deterministické komunikace v reálném čase pomocí technologií jako \textit{RT} a \textit{IRT} \cite{profinet_basics}.

\textbf{Hlavní vlastnosti:}
\begin{itemize}
	\item Podporuje deterministickou komunikaci (v režimu 	\textit{IRT} – Isochronous Real Time).
	\item Pracuje na fyzické vrstvě \textit{Ethernetu} podle \textit{IEEE 802.3} .
	\item Používá různé třídy komunikace.
	\item Podporuje synchronizaci s přesností pod \SI{1}{\micro\second}.
	\item Vyžaduje specifický hardware pro nejrychlejší režimy komunikace.
\end{itemize}

\subsection{\textit{EtherCAT} }
\textit{EtherCAT (Ethernet for Control Automation Technology)} je vysoce výkonný průmyslový protokol navržený pro rychlou a deterministickou komunikaci.
EtherCAT vyniká minimální latencí a možností synchronizace pomocí distribuovaných hodin \cite{ethercat_intro}.

\textbf{Hlavní vlastnosti:}
\begin{itemize}
	\item Umožňuje komunikaci v reálném čase s minimální latencí.
	\item Používá princip průchozího zpracování dat (telegramy se zpracovávají během průchodu uzly).
	\item Podporuje synchronizaci zařízení pomocí distribuovaných hodin.
	\item Může pracovat s kruhovou, hvězdicovou a stromovou topologií.
	\item Dosahuje cyklických časů pod 100 µs.
\end{itemize}

\section{Porovnání \textit{EtherNet/IP}, \textit{PROFINET} a \textit{EtherCAT} }

Tabulkové porovnání vybraných protokolů vychází z jejich oficiálních specifikací a dokumentací \cite{canopen_spec, devicenet_spec, profinet_basics, ethercat_intro}.

\begin{table}[H]
	\centering
	\caption{Porovnání průmyslových Ethernetových protokolů}
	\begin{tabular}{|l|c|c|c|}
		\hline
		\textbf{Parametr} & \textbf{EtherNet/IP} & \textbf{PROFINET} & \textbf{EtherCAT} \\
		\hline
		Komunikační model & Producer-Consumer    & Master-Slave      & Master-Slave      \\
		\hline
		Protokol          & TCP/IP, UDP/IP       & Ethernet Frame    & Ethernet Frame    \\
		\hline
		Determinismus     & Částečný             & Ano (IRT)         & Ano               \\
		\hline
		Rychlost          & 10/100/1000 Mbps     & 100/1000 Mbps     & 100 Mbps          \\
		\hline
		Topologie         & Hvězda               & Hvězda, kruh      & Linie, kruh       \\
		\hline
		Synchronizace     & IEEE 1588            & IEEE 1588         & DC Sync           \\
		\hline
		Latence           & 5-10 ms              & <1 ms             & <100 µs           \\
		\hline
	\end{tabular}
	\label{tab:protocol_comparison}
\end{table}

\section{Ethernet vs. \textit{CAN}}

Průmyslové Ethernetové protokoly (\textit{EtherNet/IP}, \textit{PROFINET}, \textit{EtherCAT}) nabízejí vyšší přenosové rychlosti,
flexibilnější síťovou topologii a možnost rozsáhlé konfigurace zařízení.
Na druhé straně si sítě založené na sběrnici \textit{CAN} a jejich nadstavby, jako \textit{CANopen},
stále udržují pevné postavení v aplikacích, kde jsou klíčové požadavky na odolnost vůči rušení, predikovatelné chování při zatížení a nízkou spotřebu energie.

Zatímco Ethernetové sítě vyžadují výkonnější hardware (např. síťové stacky, větší paměť, větší výpočetní výkon),
systémy postavené na \textit{CAN} lze provozovat i na nízkopříkonových 8bitových mikrořadičích.
To výrazně snižuje jejich energetickou náročnost, což je výhodné v bateriových systémech, distribuovaných senzorech nebo automobilových jednotkách.

\textbf{Hlavní rozdíly mezi \textit{Ethernetem} a \textit{CAN}:}

\begin{table}[H]
	\centering
	\caption{Srovnání vybraných vlastností protokolů založených na \textit{Ethernetu} a sběrnici \textit{CAN}}
	\begin{tabular}{|p{3.5cm}|p{5.25cm}|p{5.25cm}|}
		\hline
		\textbf{Parametr}             & \textbf{Ethernetové protokoly}                              & \textbf{\textit{CAN} a nadstavby}                                          \\
		\hline
		\textbf{Rychlost}             & Až 1~Gbit/s (\textit{PROFINET}, \textit{EtherNet/IP})       & Max. 1~Mbit/s (\textit{CAN 2.0}), až 5–8~Mbit/s (\textit{CAN FD})          \\
		\hline
		\textbf{Determinismus}        & Vysoký při použití \textit{IRT}, \textit{EtherCAT}, TSN     & Bitová arbitráž s predikovatelným chováním, vhodné pro malé sítě           \\
		\hline
		\textbf{Topologie}            & Hvězda, kruh, strom                                         & Sběrnicová (bus)                                                           \\
		\hline
		\textbf{Synchronizace}        & Možná (Distributed Clocks, IEEE~1588/PTP)                   & Není integrovaná, nutno implementovat softwarově                           \\
		\hline
		\textbf{Spotřeba energie}     & Vyšší                                                       & Nízká                                                                      \\
		\hline
		\textbf{Odolnost vůči rušení} & Závisí na kvalitě stínění a zařízení                        & Vysoká – robustní fyzická vrstva s diferenciálním přenosem                 \\
		\hline
		\textbf{Nasazení}             & Vysokorychlostní komunikace, robotika, synchronizace pohybů & Automobilový průmysl, decentralizované řídicí systémy, snímače a aktuátory \\
		\hline
	\end{tabular}
	\label{tab:ethernet_vs_can}
\end{table}

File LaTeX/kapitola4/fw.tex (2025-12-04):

\newpage

\chapter{\textit{Firmware} ARON}

Kapitola je rozčleněna do několika sekcí,
které popisují hlavní funkce \textit{firmwaru} a jeho implementaci.
Každá sekce se zaměřuje na konkrétní oblasti, které jsou klíčové pro správný chod systému.
Struktura kapitol zhruba odpovídá hlavním třídám, jež se v \textit{\textit{firmwaru}} nacházejí.
Začínáme základním nastavením mikrokontroléru, které je nezbytné pro inicializaci celého systému,
pokračujeme přes popis komunikačních protokolů, implementaci regulátorů, metody řízení
až po hlavní smyčku a obslužná přerušení.

\section{Nastavení systému}
\label{section::System_settings}
Tato sekce popisuje základní nastavení mikrokontroléru a jeho inicializaci,
která je obsažena v souboru \texttt{system\_settings.hpp}.

\subsection{Konfigurace hodin}
Nejprve je nakonfigurován systém hodin.
Jako zdroj hodinového signálu GCLK2 je použit externí krystal s frekvencí \SI{20}{\mega\hertz}.
Tento signál je předdělen na \SI{1}{\mega\hertz} a použit jako GCLK1,
což usnadňuje další násobení ve dvou fázových závěsech (\texttt{DPLLx}).

\begin{figure}[htbp]
	\centering
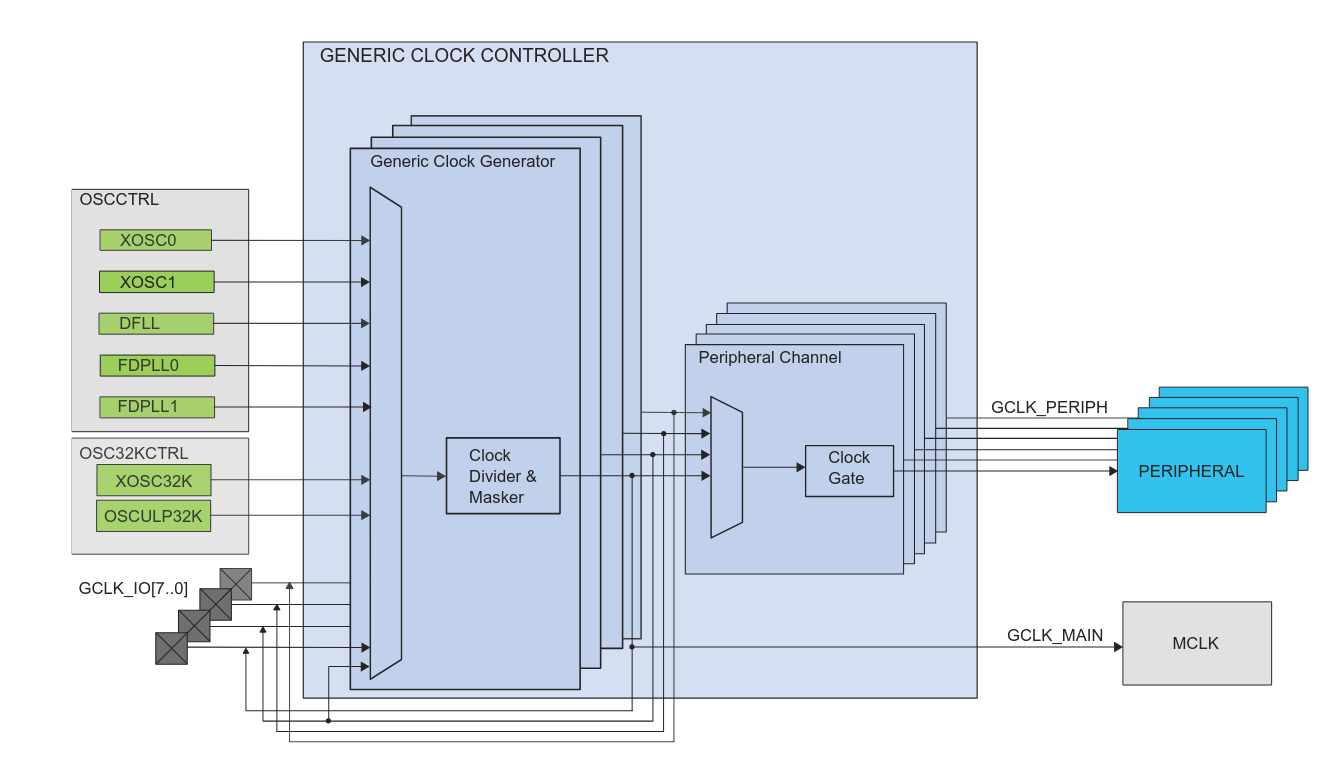
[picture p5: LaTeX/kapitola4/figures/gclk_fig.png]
	
	\caption{Rozvod hodin \textit{GCLK} v mikrokontroléru \texttt{ATSAME51J20A} (převzato z \cite{ATSAME51J20A_ds}, s. 139)}
	\label{fig:Datasheet_gclk}
\end{figure}

\begin{itemize}
	\item Výstup z prvního fázového závěsu \texttt{DPLL1} poskytuje \SI{120}{\mega\hertz} jako GCLK0,
	      který slouží jako hlavní systémové hodiny a je využíván ve všech periferiích,
	      pokud není uvedeno jinak.
	\item Dělením frekvence GCLK0 vzniká GCLK3 s hodnotou \SI{30}{\mega\hertz} je využit pro taktování obou ADC.
	\item Výstup z druhého fázového závěsu \texttt{DPLL2} poskytuje GCLK4 s frekvencí \SI{200}{\mega\hertz} slouží pro taktování PWM čítače \texttt{TCC0}.
\end{itemize}

\subsection{Inicializace \texttt{ADC1}}
\label{section::system_settings}
AD převodník \texttt{ADC1} je zde inicializován a aktivován.
Periferie \texttt{ADCx} v tomto mikrokontroléru mají maximální doporčený taktovací kmitočet určený jako \SI{16}{\mega\hertz}.
Vzhledem k vytvořeným hodinám \texttt{GCLKx} byly vybrány hodiny \texttt{GCLK3} vydělené předděličkou dvěma na \SI{15}{\mega\hertz}.
Pro co možná nejpřesnější měření je jako referneční napětí je využito \SI{2,5}{\volt} z externí reference \textit{MCP1501T-25E},
viz \nameref{section::current_output}.
Převodník je nastaven jako \SI{12}{\bit} a po zahájení konverze automaticky průměruje \SI{64}{} po sobě jdoucích vzorků.
Teprve po ukončení průměrování nastavý flag \texttt{RESRDY}, který ohlašuje úspěšné ukončení konverze.
Dále je nastaveno, aby zahíjení konverze bylo možné spustit hardwarově,
jako reakci na libovolný flag přes \texttt{Event System}.
Převodníku \texttt{ADC1} je z \texttt{Event System} přiřazen kanál číslo \SI{14}.
Kdykoliv se objeví logická \SI{1} na tomto kanále, dojde automaticky k zahájení konverze.
Logickou jedničku jde v \texttt{Event System} možné nastavit softwarově,
na požadavek uživatele.

\begin{figure}[htbp]
	\centering
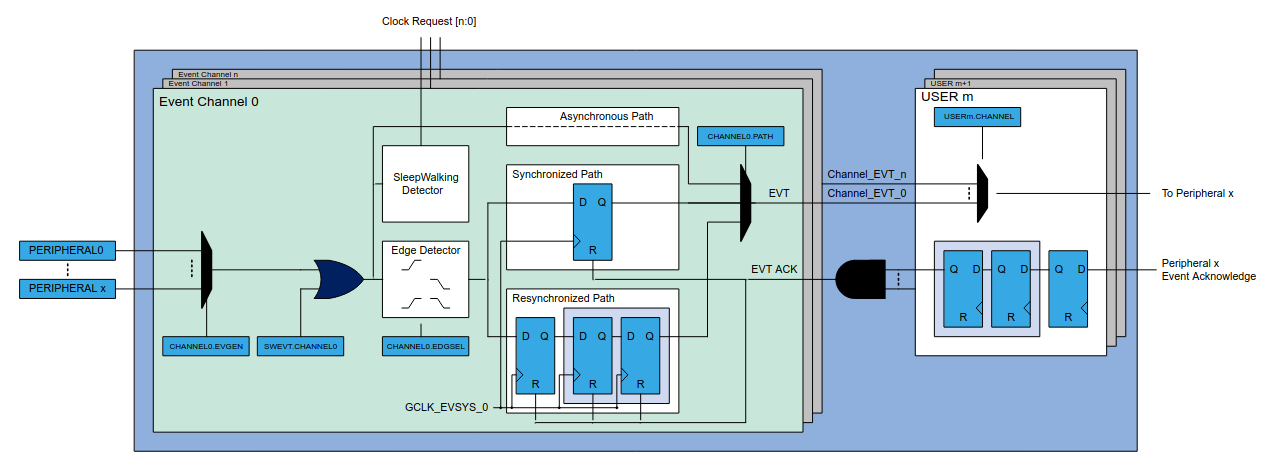
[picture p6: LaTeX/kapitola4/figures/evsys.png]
	
	\caption{Blok Event System v \texttt{ATSAME51J20A} (převzato z \cite{ATSAME51J20A_ds}, s. 783)}
	\label{fig:evsys}
\end{figure}

Vzhledem k plánovanému využití pro snímání z více pinů je zpracování výsledků konverze řízeno přerušením \texttt{ADC1}.
V rámci tohoto přerušení je vyhodnocen výsledek konverze na základě aktuálně nastavených vstupních pinů v registru \texttt{INPUTCTRL}.
Po dokončení konverze je vyvoláno přerušení, kde je zpracován výsledek z aktuálně snímaných pinů.
Po dokončení každé konverze je multiplexer automaticky přepnut na výchozí vstupní konektor \textbf{ADC1} na desce \emph{MoSeZ}.
Toto zajišťuje definovaný výchozí stav po každém zpracování výsledku.

\lstset{language=C++, basicstyle=\ttfamily\footnotesize, breaklines=true, captionpos=b}

\begin{lstlisting}[caption=Ukázka obsluhy ADC převodníku a multiplexeru vstupů, label=lst:adc_handler]
void adc1_1_handler() {
  switch (ADC1->INPUTCTRL.reg) {
    case (ADC_INPUTCTRL_MUXPOS_AIN0 | ADC_INPUTCTRL_MUXNEG_GND):
      // Měření teploty (AIN0)
      aron::adc1_temperature_read();
      ADC1->INPUTCTRL.reg = (ADC_INPUTCTRL_MUXPOS_AIN6 | ADC_INPUTCTRL_MUXNEG_GND); // Přepnutí na AIN6
      break;
    case (ADC_INPUTCTRL_MUXPOS_AIN6 | ADC_INPUTCTRL_MUXNEG_GND):
      // Měření pozice (AIN6)
      aron::Position_control::adc1_position_handler();
      break;
    case (ADC_INPUTCTRL_MUXPOS_AIN7 | ADC_INPUTCTRL_MUXNEG_GND):
      // Měření napětí na konektoru 2 (AIN7)
      float adc1_result_temp = (nd::utils::digital_to_analog_voltage(12, aron::Current_source::get_adc_vref(), ADC1->RESULT.reg));
      log().debug("{}", adc1_result_temp);
      ADC1->INPUTCTRL.reg = (ADC_INPUTCTRL_MUXPOS_AIN6 | ADC_INPUTCTRL_MUXNEG_GND); // Přepnutí zpět na AIN6
      break;
    default:
      ADC1->INPUTCTRL.reg = ADC_INPUTCTRL_MUXPOS_AIN6 | ADC_INPUTCTRL_MUXNEG_GND; // Výchozí stav: AIN6
      break;
  }
  ADC1->INTFLAG.bit.RESRDY = 1; // Vymazání příznaku přerušení
}
\end{lstlisting}

Kód ukazuje princip přepínání analogových vstupů pomocí registru \texttt{ADC1->INPUTCTRL}.
V každé větvi \texttt{switch} se nastavuje jiný vstup pro ADC převodník
(např. \texttt{AIN0} pro teplotní senzor, \texttt{AIN6} a \texttt{AIN7} pro další měření).
Po provedení měření se obvykle multiplexer přepne na další požadovaný vstup, nebo zpět na výchozí vstup.
Důležité je i mazání příznaku přerušení \texttt{RESRDY} po obsloužení požadavku.

\subsection{Ochrana proti přehřátí}

Pokud teplota překročí \SI{90}{\degreeCelsius},
výstup se automaticky vypne a současně se aktivuje červená \textit{LED} signalizující problém.
K opětovnému zapnutí nedojde pouhým poklesem teploty, výstup musí zapnout uživatel.

\subsection{Watchdog Timer}

Také zde dochází k inicializaci \textit{Watchdog Timer} \texttt{(WDT)}, což je periferie určená k monitorování správného běhu programu.
Jeho hlavním účelem je detekovat a umožnit zotavení se z chybových stavů, jako je například zablokování programu nebo nekontrolované vykonávání kódu.
Po aktivaci běží \texttt{WDT} nepřetržitě na základě předem definovaného časového limitu.
Pokud program neprovede vynulování (tzv. \textit{feeding}) \texttt{WDT} včas,
časovač vyvolá reset systému.
Kromě resetu lze využít také přerušení s předběžným varováním,
které signalizuje blížící se vypršení časovače
a v tomto přerušení podniknout kroky k obnovení chodu systému bez tvrdého restartu.
\texttt{WDT} je asynchronní a běží z nezávislého hodinového zdroje \texttt{OSCULP32K}, což znamená,
že funguje i v případě selhání hlavních systémových hodin.

\subsection{RAM ECC (Error Correction Code)}
RAM ECC zajišťuje vyšší spolehlivost systému detekcí a opravou paměťových chyb - automaticky opravuje jednobitové a detekuje dvoubitové chyby,
za cenu zabrání \SI{50}{\percent} celkové kapacity SRAM.
Aktivace probíhá zápisem do flash oblasti \texttt{USERROW} přes řadič \texttt{NVMCTRL},
přičemž před zápisem je nutné stránku kompletně vymazat.

\texttt{USERROW} obsahuje kromě ECC nastavení i kritické výrobní kalibrace.
Jakákoliv manipulace s touto oblastí vyžaduje extrémní opatrnost - nejprve je potřeba nahrát obsah do proměnné,
upravit pouze potřebné bity a poté provést zápis. Chybný zásah může \textit{MCU} zcela vyřadit z provozu.
\section{Interface}

Třída \texttt{Interface} zajišťuje inicializaci základních periferií systému, konkrétně \textit{LED} indikátorů,
tlačítka a komunikačního rozhraní \texttt{CAN} a \texttt{UART}.
Jejím cílem je připravit hardware pro správnou funkci a umožnit interakci s uživatelem i nadřazeným řídicím systémem.
Veškeré prvky jsou definovány jako statické atributy, což zajišťuje jejich snadnou dostupnost v celém programu.

\subsection{LED indikátory}

Zařízení disponuje třemi \textit{LED} indikátory,
které jsou pojmenovány jako \texttt{led\_green}, \texttt{led\_yellow} a \texttt{led\_red}.
Tyto diody slouží k vizuální signalizaci stavu systému.
Metoda \texttt{init\_led()} nastavuje všechny tři \textit{LED} jako výstupy a inicializuje je do výchozích stavů.
Ihned po spuštění systému se rozsvítí zelená a žlutá \textit{LED}, zatímco červená zůstává zhasnutá,
což umožňuje rychlou diagnostiku správného spuštění systému.
Během provozu se konfigurace rozsvícení diod mění dle aktuálního stavu zařízení.

Použití staticky definovaných instancí třídy \texttt{Gpio\_same5x} umožňuje přímou manipulaci s piny mikrokontroléru z libovolného místa v kódu.

\subsection{Tlačítko}

Tlačítko, pojmenované v kódu jako \texttt{button\_1},
je konfigurováno jako digitální vstup s aktivovaným vnitřním pull-up rezistorem,
což zajišťuje jeho stabilní stav při neuvedení do sepnuté polohy.
Pro detekci dlouhého stisku je využit časovač \texttt{TC2}, k
terý běží s hodinovým zdrojem \SI{1}{\mega\hertz} a využívá děličku frekvence \texttt{DIV64}.
Díky tomu lze přesně měřit dobu stisku tlačítka.
Časovač je nakonfigurován tak, aby vyvolal přerušení po přibližně 3 sekundách (\texttt{CC[0] = 46875}),
což umožňuje spolehlivou detekci dlouhého stisku a jeho odlišení od krátkého stisku.
Aktivace časovače probíhá v metodě \texttt{init\_button()},
kde se kromě konfigurace GPIO pinů nastavuje i přerušení pro \texttt{TC2}.
Přerušení je povoleno pomocí \texttt{NVIC\_EnableIRQ(TC2\_IRQn)}.
Obsluha tohoto přerušení je vyvolána po přetečení čítače,
což umožňuje systémové reakce na dlouhý stisk tlačítka.
Krátký stisk tlačítka je obsloužen v \texttt{main()} – pokud je tlačítko uvolněno před přetečením čítače \texttt{TCC2},
je stisk vyhodnocen jako krátký.

Krátký stisk tlačítka slouží k zapínání a vypnutí výstupu zařízení,
zatímco dlouhý stisk zajišťuje napřed vypnutí výstupu a poté restart celého systému.

\subsection{Třída \texttt{Logger}}

Třída \texttt{Logger} je implementována jako singleton, což znamená, že existuje pouze jedna instance loggeru v celém systému.
Tato instance je dostupná prostřednictvím metody \texttt{getLogger()}. Logger umožňuje nastavit jednotlivé úrovně záznamu
a poskytuje metody pro generování logovacích zpráv.
Každá zpráva je opatřena časovou značkou a výstupní formát je konstruován pomocí knihovny \texttt{fmt}.
Zprávy jsou poté předány metodě \texttt{log()}, která zajistí jejich odeslání do konkrétního výstupního zařízení.

\subsection{Třída \texttt{LoggerUart}}

Pro odesílání logovacích zpráv přes sériovou linku \texttt{UART} byla implementována odvozená třída \texttt{LoggerUart}.
Tato třída dědí z \texttt{Logger} a přepisuje metodu \texttt{log()}, která zajistí přenos zprávy prostřednictvím
ovladače \texttt{Usart\_blocking\_same5x}.

\subsection{Třída \texttt{CAN\_ATSAM\_C\_E}}

Třída slouží jako komplexní rozhraní pro práci s \textit{CAN} komunikací na mikrokontroléru \textit{ATSAM5X}.
Tento řadič sběrnice \textit{CAN} (Controller Area Network) je v systému realizován pomocí periferie \texttt{CAN1} a transceiveru \textit{TCAN334}.
Implementace třídy zahrnuje veškeré potřebné funkce – od inicializace a konfigurace periferie až po odesílání,
přijímání a filtrování zpráv, včetně zpracování chyb.

V konstruktoru třídy dochází k nastavení všech klíčových parametrů komunikace.
Konkrétně se jedná o konfiguraci pinů mikrokontroléru, aktivaci režimu \textit{CAN FD}, nastavení bitové rychlosti a konfiguraci filtrů zpráv.
Inicializace sběrnice \textit{CAN} probíhá v několika krocích.
Nejprve je nutné správně nakonfigurovat piny mikrokontroléru vyhrazené pro komunikaci a
povolit hodinový signál pro periferii. Následně je aktivován režim \textit{CAN FD}, který umožňuje vyšší přenosové rychlosti a
efektivnější komunikaci. Řadič \texttt{CAN1} je taktován generátorem \texttt{GCLK2} s frekvencí \SI{20}{\mega\hertz}.
Poté jsou nastaveny parametry časování, aby byla zajištěna optimální bitová rychlost.
Filtraci přijatých zpráv zajišťují standardní i rozšířené ID filtry,
které umožňují efektivně řídit, jaké zprávy budou zpracovány.

Pro příjem zpráv je využíván FIFO buffer, který po zpracování každou zprávu automaticky odstraňuje.
Odesílání zpráv funguje na principu vyrovnávací paměti (bufferu).
Zprávy se nejprve zapíší do bufferu a poté jsou odeslány po sběrnici.
Pokud není v bufferu dostatek volného místa, odeslání zprávy se neprovede, čímž se předchází zahlcení sběrnice.
Spolehlivost komunikace zajišťují implementované mechanismy pro detekci a zpracování chyb.
Třída dokáže rozpoznat chyby v přenosu, detekovat ztrátu zpráv a řešit další možné problémy,
které by mohly narušit správnou funkčnost \textit{CAN} sběrnice.

\subsection{Komunikační rozhraní}

Vytvořením instancí tříd \texttt{LoggerUart} a
\texttt{CAN\_ATSAM\_C\_E} unitř třidy \texttt{Interface} je inicializováno komunikační rozhraní systému.
Tyto tři výše jmenované třídy mi byly poskytnuty vedoucím práce, kterémuž tímto děkuji.
Pro účely ladění a diagnostiky je k dispozici sériový komunikační kanál \texttt{UART}.
Inicializace tohoto kanálu probíhá v metodě \texttt{init\_communication()},
kde je vytvořen objekt \texttt{LoggerUart}.
Tento objekt zajišťuje přenos dat prostřednictvím modulu \texttt{SERCOM4} s přenosovou rychlostí \SI{921 600}{\baud}.
Po úspěšné aktivaci \texttt{UART} kanálu je logger nastaven jako výchozí nástroj pro výpis zpráv.
Následně jsou do konzole odeslány úvodní inicializační zprávy.

Pro efektivní záznam událostí a ladění systému je implementována flexibilní struktura logování.
Tato struktura je založena na třídě \texttt{Logger},
která definuje několik úrovní závažnosti zpráv.
Mezi tyto úrovně patří \texttt{error} (chyba), \texttt{warn} (varování),
\texttt{info} (informace), \texttt{debug} (ladění), \texttt{CAN} a \texttt{CANopen}.
Díky této struktuře je možné snadno filtrovat a zaznamenávat pouze relevantní zprávy,
což usnadňuje proces ladění a diagnostiky.

Pro komunikaci desek mezi sebou je implementováno rozhraní \texttt{CAN}.
Hardwarovou vrstvu tvoří transceiver \texttt{TCAN334}, viz \nameref{section::CAN_Bus_Driver},
který je přes piny \texttt{PB13} a \texttt{PB12} propojen s řadičem sběrnice \texttt{CAN1}.

Metoda \texttt{init\_communication()} se stará o aktivaci transceiveru a inicializaci \texttt{CAN} řadiče.
Tento proces zahrnuje povolení napájení, nastavení režimu komunikace a konfiguraci odpovídajících GPIO pinů.
Tím je zajištěno, že zařízení je připraveno k přenosu a příjmu dat přes sběrnici \texttt{CAN}.

\subsection{Kompletní inicializace všech používaných interfaců}
Pro snadnou možnost inicializace periferií interface současně,
byla vytvořena metoda \texttt{init\_all()}.
Tato metoda postupně volá \texttt{init\_led()}, \texttt{init\_button()} a \texttt{init\_communication()},
čímž zajišťuje, že všechny nezbytné komponenty jsou správně nastaveny před zahájením hlavního běhu programu.

\section{Protokol komunikace po \texttt{CAN} a \texttt{UART}}
\label{section::comunication_protocol}

Sběrnice \textit{CAN} slouží k obecné komunikaci mezi zdroji.
Rozhraní \textit{UART} slouží jako jednoduchý kanál pro připojení jednoho zdroje \emph{MoSeZ} k PC.
Pokud je ovšem z PC adresován zdroj s jiným \textit{ID}, než je zdroj, který je připojen k PC,
dojde k automatickému přesměrování zprávy na sběrnici \textit{CAN}.

Přijatá zprává s validním \textit{ID} je předána metodě \texttt{aron::CommandHandler::message\_handler},
která zkontroluje správnost přijatých dat.
Pokud jsou přijatá data v pořádku,
je zpráva předána k vykonání, či předána k plnění sekvence.

Obě rozhraní dodržují formát zpráv ve tvaru stringu,
kde první je \textbf{Id}, pak \textbf{Příkaz} a nakonec \textbf{Data}.
Psáno bez oddělujících mezer tak, že:

\begin{center}
	\textbf{Id Příkaz Data}
\end{center}

kde:
\begin{enumerate}
	\item \textbf{Id} – identifikátor adresovaného zdroje,
	\item \textbf{Příkaz} – požadavek na adresovaný zdroj,
	\item \textbf{Data} – hodnoty předané zdroji.
\end{enumerate}

%===========================================================
\begin{table}[htbp]
	\centering
	\caption{Základní příkazy pro nastavení výstupu zdroje.
		*Pro zapnutí střídavého výstupu a řízení polohy je nutné nejprve nastavit tvar a frekvenci střídavého průběhu.}
	\begin{tabular} { | >{\centering\arraybackslash}m{3cm} | >{\centering\arraybackslash}m{3cm} | >{\raggedright\arraybackslash}m{8cm} | }
		\hline
		\textbf{Příkaz} & \textbf{Příklad} & \textbf{Popis}                                                                                                  \\
		\hline
		\texttt{I}      & \texttt{1I650}   & Požadovaná amplituda výstupního proudu. \newline Rozsah: \SI{-8000}{\milli\ampere} až \SI{8000}{\milli\ampere}. \\
		\hline
		\texttt{D}      & \texttt{1D1}     & Zapnutí/vypnutí DC výstupu. \newline 1 = zapnuto, 0 = vypnuto.                                                  \\
		\hline
		\texttt{A}      & \texttt{4A1}     & Zapnutí/vypnutí AC výstupu. \newline 1 = zapnuto, 0 = vypnuto.                                                  \\
		\hline
		\texttt{P}      & \texttt{1P1}     & Zapnutí/vypnutí řízení polohy voicecoilu. \newline 1 = zapnuto, 0 = vypnuto.                                    \\
		\hline
	\end{tabular}
	\label{tab:basic_commands}
\end{table}

%===========================================================\begin{table}[htpb]
%===========================================================
\begin{table}[htbp]
	\centering
	\caption{Příkazy pro nastavení průběhu a frekvence}
	\begin{tabular} { | >{\centering\arraybackslash}m{2.5cm} | >{\centering\arraybackslash}m{2.5cm} | >{\raggedright\arraybackslash}m{8.5cm} | }
		\hline
		\textbf{Příkaz} & \textbf{Příklad} & \textbf{Popis}                                                                                                                                       \\
		\hline
		\texttt{H}      & \texttt{1H50}    & Nastavení harmonického výstupu s~požadovanou frekvencí jako unsigned integer v~\SI{}{\hertz}. \newline Rozsah: \SI{1}{\hertz} až \SI{3000}{\hertz}.  \\
		\hline
		\texttt{T}      & \texttt{2T60}    & Nastavení trojúhelníkového výstupu frekvencí jako unsigned integer v~\SI{}{\hertz}. \newline Rozsah: \SI{1}{\hertz} až \SI{3000}{\hertz}.            \\
		\hline
		\texttt{S}      & \texttt{3S6000}  & Nastavení obdélníkového výstupu s~požadovanou frekvencí jako unsigned integer v~\SI{}{\hertz}. \newline Rozsah: \SI{1}{\hertz} až \SI{3000}{\hertz}. \\
		\hline
		\texttt{C}      & \texttt{2C75}    & Nastavení střídy obdélníkového výstupu v~procentech. \newline Rozsah: \SI{0}{\percent} až \SI{100}{\percent}.                                        \\
		\hline
		\texttt{RT}     & \texttt{3RT10}   & Nastavení doby náběhu obdélníkového signálu v~procentech periody. \newline Rozsah: \SI{0}{\percent} až \SI{50}{\percent}.                            \\
		\hline
		\texttt{F}      & \texttt{1F90}    & Nastavení fázového posunu výstupu ve stupních. \newline Rozsah: \SI{0}{\degree} až \SI{360}{\degree}.                                                \\
		\hline
		\texttt{O}      & \texttt{1O1000}  & Nastavení offsetu AC výstupu v~\SI{}{\milli\ampere}. \newline Rozsah: \SI{-6000}{\milli\ampere} až \SI{6000}{\milli\ampere}.                         \\
		\hline
	\end{tabular}
	\label{tab:waveform_commands}
\end{table}

%===========================================================
\begin{table}[htpb]
	\centering
	\caption{Příkazy použitelné pouze pro řízení polohy voicecoilu}
	\begin{tabular} { | >{\centering\arraybackslash}m{2.5cm} | >{\centering\arraybackslash}m{2.5cm} | >{\raggedright\arraybackslash}m{8.5cm} | }
		\hline
		\textbf{Příkaz} & \textbf{Příklad} & \textbf{Popis}                                                                                                                                                            \\
		\hline
		\texttt{R}      & \texttt{1R5000}  & Nastavení amplitudy polohy v~\SI{}{\milli\metre}. Hodnota je zadávána v tisícinách milimetru. \newline Součet offsetu a amplitudy musí být $\leq$ \SI{8.0}{\milli\metre}. \\
		\hline
		\texttt{V}      & \texttt{1V3500}  & Nastavení offsetu polohy v~\SI{}{\milli\metre}. Hodnota je zadávána v tisícinách milimetru. \newline Součet offsetu a amplitudy musí být $\leq$ \SI{8.0}{\milli\metre}.   \\
		\hline
	\end{tabular}
	\label{tab:position_commands}
\end{table}
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

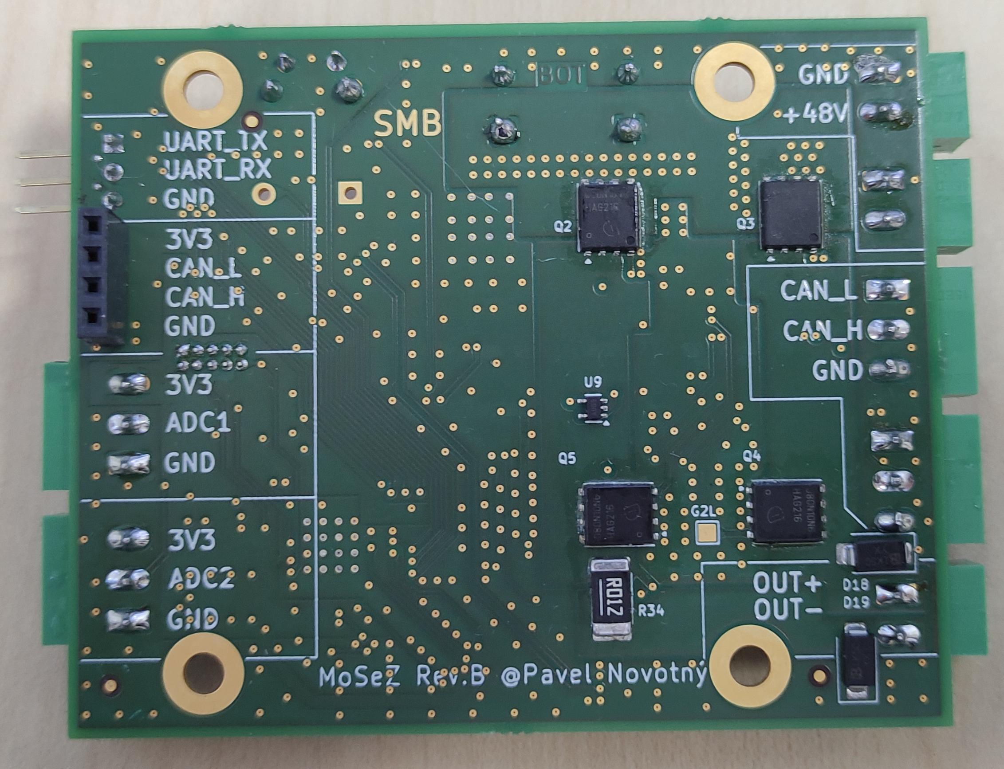
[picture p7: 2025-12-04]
LaTeX/kapitola1/figures/pcb_back.jpg

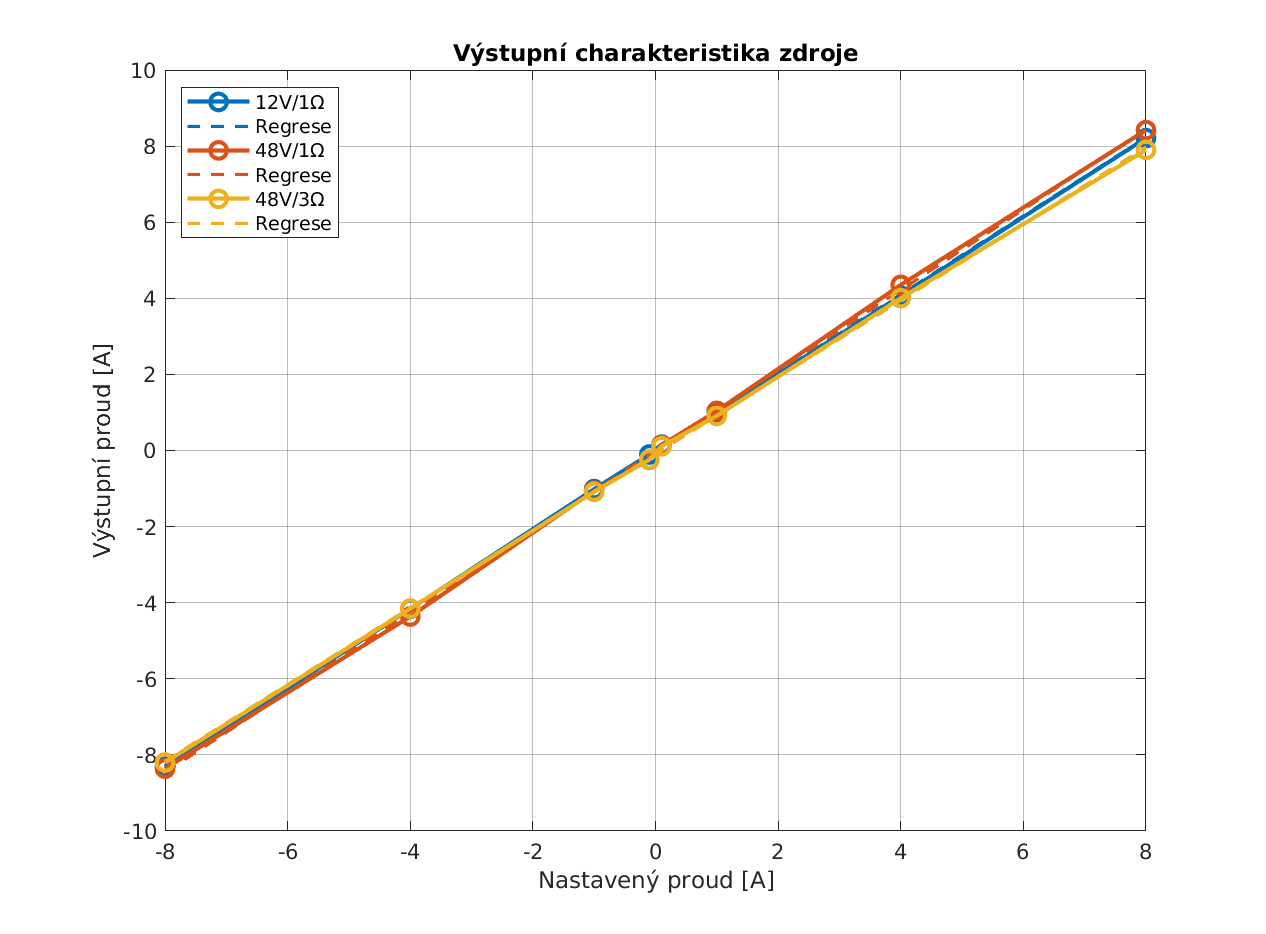
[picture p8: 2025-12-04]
LaTeX/kapitola5/Figures/Graf1_Vystupni_charakteristika.png

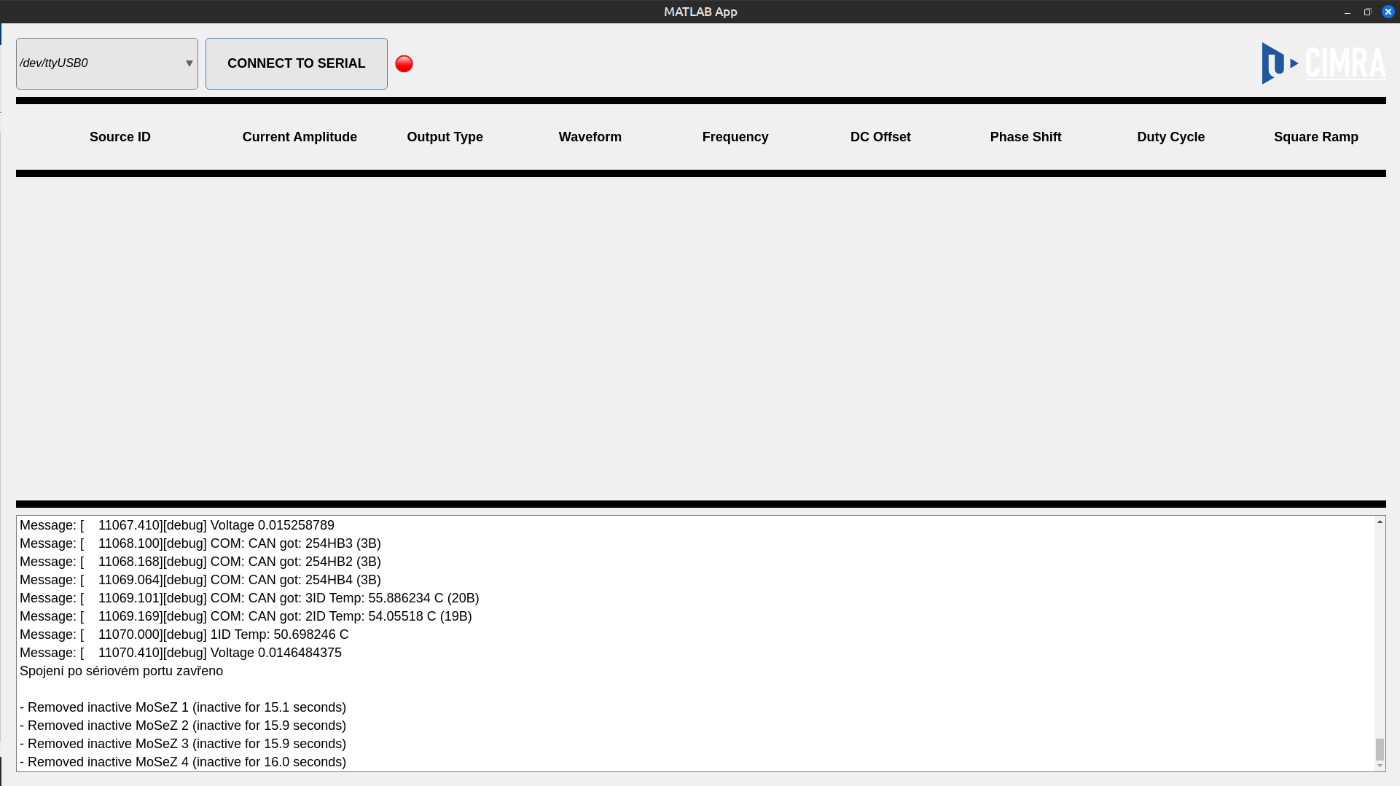
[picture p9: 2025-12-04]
LaTeX/kapitola7/Figures/staff_sources_timeout.png

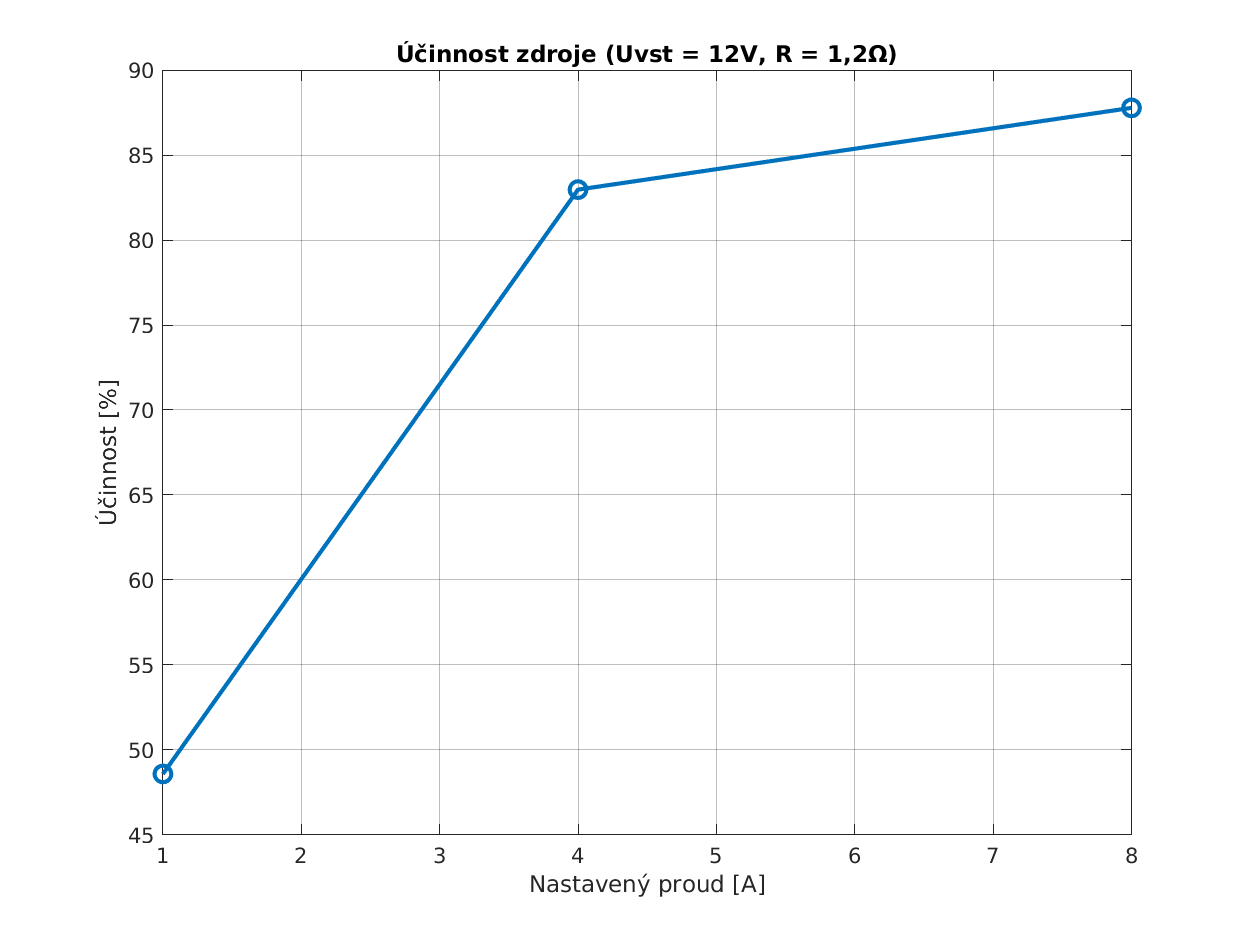
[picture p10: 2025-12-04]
LaTeX/kapitola5/Figures/DC_ucinnost_12V.png

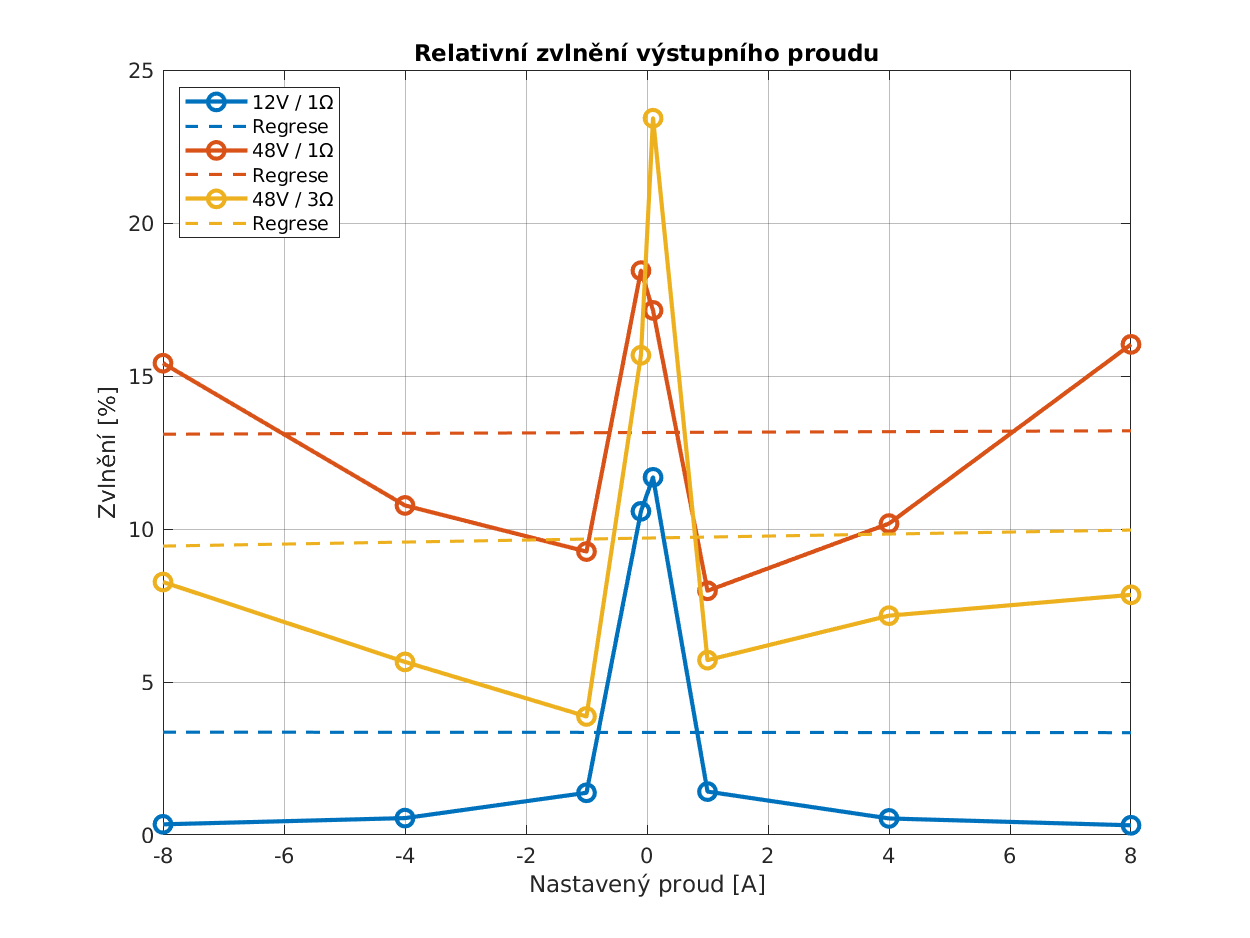
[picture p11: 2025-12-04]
LaTeX/kapitola5/Figures/DC_relativni_zvlneni.png

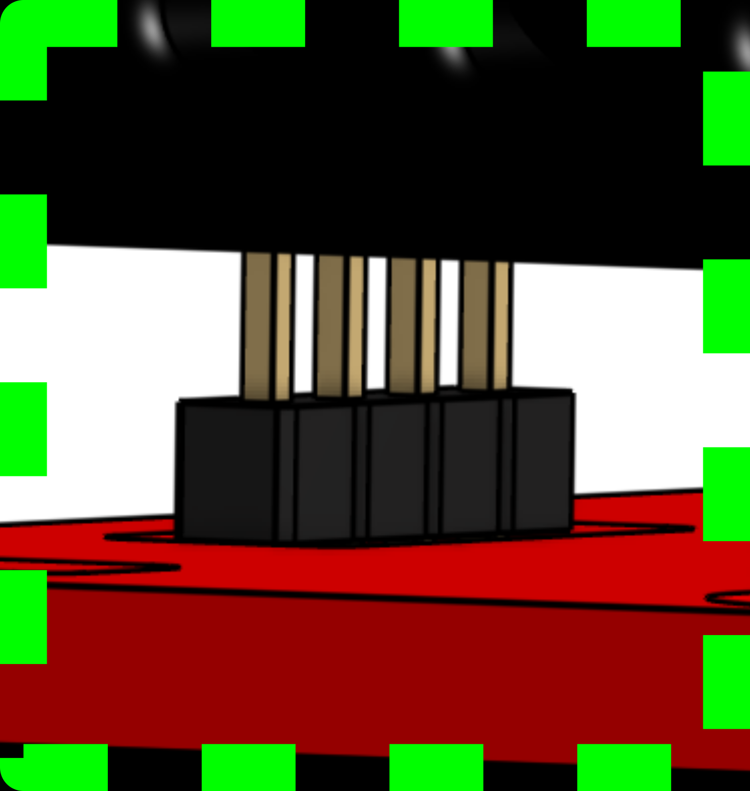
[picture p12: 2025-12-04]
LaTeX/kapitola2/figures/rect4484.png

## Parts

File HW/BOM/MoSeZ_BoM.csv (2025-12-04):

Source: | /home/pavel/modular-current-source/HW_2.0/MoSeZ_2.kicad_sch
Date: | Thu 04 Apr 2024 10:45:10 AM CEST
Tool: | Eeschema 7.0.11-7.0.11~ubuntu22.04.1
Generator: | /usr/share/kicad/plugins/bom_csv_grouped_by_value.py
Component Count: | 138
Collated Components:
Item | Qty | Reference(s) | Value | LibPart | Footprint | Datasheet | DNP | CENA | MNUMBER | OBJCISLO | POZN | Sim.Device | Sim.Library | Sim.Name | Sim.Params | Sim.Pins | Vendor
1 | 1 | BZ1 | CMI1295IC0385(1285) | MiSPiZ-rescue:Buzzer-Device | Buzzer_Beeper:Buzzer_12x9.5RM7.6 | https://cz.mouser.com/datasheet/2/670/cmi_1295ic_0385t-1776836.pdf |  | 24,33 | CMI-1295IC-0385T | 490-CMI-1295IC-0385T |  |  |  |  |  |  | https://cz.mouser.com/ProductDetail/CUI-Devices/CMI-1295IC-0385T?qs=OlC7AqGiEDk2g42uzfEhlg%3D%3D
2 | 23 | C1, C4, C7, C9, C14, C17, C19, C21, C23, C24, C25, C27, C33, C37, C38, C40, C42, C43, C45, C48, C49, C50, C52 | 100nF/25V | Device:C_Small | Capacitor_SMD:C_0603_1608Metric | https://cz.mouser.com/datasheet/2/585/MLCC_Automotive-1837966.pdf |  | 2,23 | CL10B104KA8WPNC | 187-CL10B104KA8WPNC | v cimře |  |  |  |  |  | https://cz.mouser.com/ProductDetail/KEMET/C0603C104M3RACTU?qs=7q2aiX3Gdlh4qBRaMcnohQ%3D%3D
3 | 2 | C2, C3 | 150uF | MiSPiZ-rescue:CP_Small-Device | Capacitor_THT:CP_Radial_D10.0mm_P5.00mm | https://cz.mouser.com/datasheet/2/315/Panasonic_08082018_Capacitor_Radial_Leaded_Lytic_(-1387098.pdf |  | 18.31 | EEU-FS1K151B | 667-EEU-FS1K151B |  |  |  |  |  |  | https://cz.mouser.com/ProductDetail/Panasonic/EEU-FS1K151B
4 | 7 | C5, C6, C15, C18, C28, C31, C47 | 22nF/100V | Device:C_Small | Capacitor_SMD:C_0603_1608Metric | https://cz.mouser.com/datasheet/2/447/KEM_C1002_X7R_SMD-3316098.pdf |  | 2,23 | C0603C223K1RACTU | 80-C0603C223K1R |  |  |  |  |  |  | https://cz.mouser.com/ProductDetail/KEMET/C0603C223K1RACTU?qs=XbM9o1La6yBUeoWn89gwrQ%3D%3D
5 | 7 | C8, C10, C11, C12, C13, C20, C39 | 22uF/25V | Device:C_Small | Capacitor_SMD:C_0805_2012Metric | https://cz.mouser.com/datasheet/2/585/MLCC-1837944.pdf |  | 5,59 | CL21A226MAYNNNE | 187-CL21A226MAYNNNE |  |  |  |  |  |  | https://cz.mouser.com/ProductDetail/Samsung-Electro-Mechanics/CL21A226MAYNNNE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
6 | 3 | C16, C22, C41 | 2.2uF/25V | Device:C_Small | Capacitor_SMD:C_0805_2012Metric | https://cz.mouser.com/datasheet/2/585/MLCC-1837944.pdf |  | 2.69 | CL21A225KAFNNNG | 187-CL21A225KAFNNNG |  |  |  |  |  |  | https://cz.mouser.com/ProductDetail/Samsung-Electro-Mechanics/CL21A225KAFNNNG?qs=yOVawPpwOwlfuACaawXMWQ%3D%3D
7 | 6 | C26, C30, C35, C36, C44, C46 | 18pF/10V | Device:C_Small | Capacitor_SMD:C_0603_1608Metric | https://cz.mouser.com/datasheet/2/447/UPY_NP0X5R_01005_4V_to_25V_V10-3003057.pdf |  | 2,23 | CC0603JRNP09BN180 | 603-CC603JRNPO9BN180 | v cimře |  |  |  |  |  | https://cz.mouser.com/ProductDetail/YAGEO/CC0603JRNP09BN180?qs=50q%252BZR8McTHRfBNgel14eQ%3D%3D
8 | 4 | C29, C32, C51, C53 | 1nF | Device:C_Small | Capacitor_SMD:C_0603_1608Metric | https://product.tdk.com/system/files/dam/doc/product/capacitor/ceramic/mlcc/catalog/mlcc_automotive_midvoltage_en.pdf |  | 2,23 | CGA3E2X7R2A102K080AA | 810-CGA3E2X7R2A102K |  |  |  |  |  |  | https://cz.mouser.com/ProductDetail/TDK/CGA3E2X7R2A102K080AA?qs=NRhsANhppD%2FkMFCdFnDSsQ%3D%3D
9 | 1 | D1 | Green | Device:LED | Diode_SMD:D_0603_1608Metric | https://cz.mouser.com/datasheet/2/239/Lite-On-LTST-C190GKT-1175335.pdf |  | 5,14 | LTST-C190GKT | 859-LTST-C190GKT | v cimře |  |  |  |  |  | https://cz.mouser.com/ProductDetail/Lite-On/LTST-C190GKT?qs=drxkyCeiWgbQzclgbojDOg%3D%3D
10 | 1 | D2 | Red | Device:LED | Diode_SMD:D_0603_1608Metric | https://cz.mouser.com/datasheet/2/239/LTST_C190KRKT-1141828.pdf |  | 5,35 | LTST-C190KRKT | 859-LTST-C190KRKT | v cimře |  |  |  |  |  | https://cz.mouser.com/ProductDetail/Lite-On/LTST-C190KRKT?qs=kAD5fFa1n5VY3YYNWPC1Fg%3D%3D
11 | 1 | D3 | Yellow | Device:LED | Diode_SMD:D_0603_1608Metric | https://cz.mouser.com/datasheet/2/239/Lite_On_LTST_C190YKT-3045572.pdf |  | 5,81 | LTST-C190YKT | 859-LTST-C190YKT | v cimře |  |  |  |  |  | https://cz.mouser.com/ProductDetail/Lite-On/LTST-C190YKT?qs=wDJfsqwEKoQ00yiPP8kQ9g%3D%3D
12 | 3 | D4, D18, D19 | SMAJ48CA | Diode:SMAJ48CA | Diode_SMD:D_SMA | https://cz.mouser.com/datasheet/2/447/SMAJ_1-1954892.pdf |  | 6.7 | SMAJ48CA/TR13 | 603-SMAJ48CA/TR13 |  |  |  |  |  |  | https://cz.mouser.com/ProductDetail/YAGEO/SMAJ48CA-TR13?qs=PzGy0jfpSMtwTD%2FntLzwHQ%3D%3D
13 | 7 | D5, D7, D9, D11, D14, D15, D16 | PESD3V3S2UT | Device:D_TVS_Dual_AAC | Package_TO_SOT_SMD:SOT-23 | https://cz.mouser.com/datasheet/2/916/PESD3V3S2UT-3162503.pdf |  | 8.71 | PESD3V3S2UT,215 | 771-PESD3V3S2UT-T/R | v cimře |  |  |  |  |  | https://cz.mouser.com/ProductDetail/Nexperia/PESD3V3S2UT215?qs=LOCUfHb8d9uvXk1XKyOSVw%3D%3D
14 | 2 | D6, D8 | BYG10D | Device:D | Diode_SMD:D_SMA | https://diotec.com/request/datasheet/byg10d.pdf |  | 3,58 | BYG10D | 637-BYG10D |  | D |  |  |  | 1=K 2=A | https://cz.mouser.com/ProductDetail/Diotec-Semiconductor/BYG10D?qs=OlC7AqGiEDkrQ9cudWHEKw%3D%3D
15 | 2 | D10, D12 | Blue | Device:LED | Diode_SMD:D_0603_1608Metric | https://cz.mouser.com/datasheet/2/239/Lite-On-LTST-C193TBKT-5A-1175300.pdf |  | 6,48 | LTSTC193TBKT5A | 859-LTSTC193TBKT5A | v cimře |  |  |  |  |  | https://cz.mouser.com/ProductDetail/Lite-On/LTST-C193TBKT-5A?qs=xIkB7y1OTorvzzuuxuVkOA%3D%3D
16 | 2 | F1, F2 | 2920L150/60MR | Device:Polyfuse_Small | Fuse:Fuse_2920_7451Metric | https://cz.mouser.com/datasheet/2/240/Littelfuse_10_27_2023_2920L_Series_Datasheet-3359581.pdf |  | 19.2 | 2920L150/60MR | 576-2920L150/60MR |  |  |  |  |  |  | https://cz.mouser.com/ProductDetail/Littelfuse/2920L150-60MR?qs=ST9lo4GX8V38m%2FHq5uhZ8w%3D%3D
17 | 1 | FB1 | 330R@100MHz | MiSPiZ-rescue:Ferrite_Bead_Small-Device | Inductor_SMD:L_0805_2012Metric | https://cz.mouser.com/datasheet/2/54/mgmumz-1067070.pdf |  | 2.23 | MU2029-301Y | 652-MU2029-301Y | v cimře |  |  |  |  |  | https://cz.mouser.com/ProductDetail/Bourns/MU2029-301Y?qs=lrqjml%252Bjt8d7bWD70%252BoHKQ%3D%3D
18 | 3 | J1, J3, J9 | 3.5mm/2p | MiSPiZ-rescue:Conn_01x02_Female-Connector | Connector_Phoenix_MC:PhoenixContact_MC_1,5_2-G-3.5_1x02_P3.50mm_Horizontal | https://cz.mouser.com/datasheet/2/18/1/rLFHPy7mAQED-1379250.pdf |  | 8,71 | OQ0212500000G | 649-220107-C021A01LF | v cimře |  |  |  |  |  | https://cz.mouser.com/ProductDetail/Amphenol-Anytek/OQ0212500000G?qs=Mv7BduZupUhn3%2FKe8nJdbQ%3D%3D
19 | 1 | J2 | 2.54mm/3p | MiSPiZ-rescue:Conn_01x03_Female-Connector | Connector_PinHeader_2.54mm:PinHeader_1x03_P2.54mm_Vertical | https://cdn.amphenol-cs.com/media/wysiwyg/files/documentation/datasheet/boardwiretoboard/bwb_econostik_254headers.pdf |  | 2.23 | 10129378-903001BLF | 649-1012937890301BLF | v cimře |  |  |  |  |  | https://cz.mouser.com/ProductDetail/Amphenol-FCI/10129378-903001BLF?qs=0lQeLiL1qybuYTJnitumiA%3D%3D
20 | 1 | J4 | 2.54/4p | MiSPiZ-rescue:Conn_01x04_Female-Connector | Connector_PinHeader_2.54mm:PinHeader_1x04_P2.54mm_Vertical | https://cdn.amphenol-cs.com/media/wysiwyg/files/documentation/datasheet/boardwiretoboard/bwb_agilbrick_2_54mm_btb_header_g800.pdf |  | 2.45 | G800W304018EU | 523-G800W304018EU | v cimře (7+4ks) |  |  |  |  |  | https://cz.mouser.com/ProductDetail/Amphenol-Commercial-Products/G800W304018EU?qs=f9yNj16SXrKi9QS16pMdvA%3D%3D
21 | 4 | J5, J7, J8, J10 | 3.5mm/3p | MiSPiZ-rescue:Conn_01x03_Female-Connector | Connector_Phoenix_MC:PhoenixContact_MC_1,5_3-G-3.5_1x03_P3.50mm_Horizontal | https://cz.mouser.com/datasheet/2/18/1/rLFHPy7mAQED-1379250.pdf |  | 10,94 | OQ0312500000G | 649-220107-C031A01LF | v cimře |  |  |  |  |  | https://cz.mouser.com/ProductDetail/Amphenol-Anytek/OQ0312500000G?qs=Mv7BduZupUgi736aEq2YkA%3D%3D
22 | 1 | J6 | PRG_Kon | Connector_Generic:Conn_02x05_Odd_Even | Connector_PinHeader_1.27mm:PinHeader_2x05_P1.27mm_Vertical | https://cdn.amphenol-cs.com/media/wysiwyg/files/documentation/datasheet/boardwiretoboard/bwb_minitek127_btb.pdf |  | 16,51 | 20021111-00010T4LF | 649-221111-00010T4LF |  |  |  |  |  |  | https://cz.mouser.com/ProductDetail/Amphenol-FCI/20021111-00010T4LF?qs=nwYJ12Fl9gR8B5xkaYs9gA%3D%3D
23 | 1 | L1 | 47uH | Device:L | Inductor_SMD:L_Cenker_CKCS6045 | https://cz.mouser.com/datasheet/2/54/SRN6045HA_datasheet-2498144.pdf |  | 4.68 | SRN6045HA-470M | 652-SRN6045HA-470M |  |  |  |  |  |  | https://cz.mouser.com/ProductDetail/Bourns/SRN6045HA-470M?qs=e8oIoAS2J1TQqJ%2FyaON1CQ%3D%3D
24 | 1 | L2 | 10uH | Device:L_Small | Inductor_SMD:L_Wuerth_MAPI-2010 | https://cz.mouser.com/datasheet/2/54/srn2010ta-1391479.pdf |  | 4.46 | SRN2010TA-100M | 652-SRN2010TA-100M |  |  |  |  |  |  | https://cz.mouser.com/ProductDetail/Bourns/SRN2010TA-100M?qs=Vt59ZOdFuWbfYOxS0u%252BNrA%3D%3D
25 | 1 | Q1 | PJA3434_R1_00001 | Device:Q_NMOS_DGS | Package_TO_SOT_SMD:SOT-23-3 | https://cz.mouser.com/datasheet/2/115/DIOD_S_A0012994429_1-2543814.pdf |  | 5,14 | SSM3K16FV,L3F | 621-DMN2310U-7 |  |  |  |  |  |  | https://cz.mouser.com/ProductDetail/Diodes-Incorporated/DMN2310U-7?qs=xZ%2FP%252Ba9zWqY%252BAdKLxIytvQ%3D%3D
26 | 4 | Q2, Q3, Q4, Q5 | ISC080N10NM6ATMA1 | Transistor_FET:BSC440N10NS3G | Package_SON:Infineon_PG-TDSON-8_6.15x5.15mm | https://cz.mouser.com/datasheet/2/196/Infineon_ISC080N10NM6_DataSheet_v02_02_EN-3363527.pdf |  | 31.68 | ISC080N10NM6ATMA1 | 726-ISC080N10NM6ATMA |  |  |  |  |  |  | https://cz.mouser.com/ProductDetail/Infineon-Technologies/ISC080N10NM6ATMA1?qs=QNEnbhJQKvYFG853AC%2FdSQ%3D%3D
27 | 9 | R1, R2, R3, R4, R5, R15, R23, R25, R28 | 2k4 | Device:R_Small | Resistor_SMD:R_0603_1608Metric | https://www.tme.eu/Document/c283990e907c122bb808207d1578ac7f/POWER_RATING-DTE.pdf |  | 0.303 (100+) | 0603SAJ0242T5E | SMD0603-2.4K | v cimře |  |  |  |  |  | https://www.tme.eu/cz/en/details/smd0603-2.4k/smd-resistors/royal-ohm/0603saj0242t5e/
28 | 5 | R6, R7, R9, R10, R11 | 100k | Device:R_Small | Resistor_SMD:R_0603_1608Metric | https://www.tme.eu/Document/326d66a3afe39e93e71f6e8db4b86cca/ASC_WF08P-06P_V05.pdf |  | 2,45 | WF06P104JTL | WF06P-100K-5 | v cimře |  |  |  |  |  | https://www.tme.eu/cz/details/wf06p-100k-5%25/rezistory-smd/walsin/wf06p104jtl/
29 | 12 | R8, R12, R17, R18, R19, R20, R21, R24, R26, R29, R30, R31 | 10k | Device:R_Small | Resistor_SMD:R_0603_1608Metric | https://www.vishay.com/docs/20035/dcrcwe3.pdf |  | 2,23 | CRCW060310K0FKECC | 71-CRCW060310K0FKECC |  |  |  |  |  |  | https://cz.mouser.com/ProductDetail/Vishay-Dale/CRCW060310K0FKECC
30 | 7 | R13, R14, R16, R22, R27, R32, R33 | 3R3 | Device:R_Small | Resistor_SMD:R_0805_2012Metric | https://cz.mouser.com/datasheet/2/315/AOA0000C331-1141874.pdf |  | 2,69 | ERJ-P06J3R3V | 667-ERJ-P06J3R3V |  |  |  |  |  |  | https://cz.mouser.com/ProductDetail/Panasonic/ERJ-P06J3R3V
31 | 1 | R34 | 12m | Device:R_Small | Resistor_SMD:R_2512_6332Metric | https://www.eaton.com/content/dam/eaton/products/electronic-components/resources/data-sheet/eaton-msma-automotive-smd-current-sense-resistor-metal-strip-data-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 |  | 7,82 | MSMA2512R0120FGM | 504-MSMA2512R0120FGM | 1.25V při 10A |  |  |  |  |  | https://cz.mouser.com/ProductDetail/Bussmann-Eaton/MSMA2512R0120FGM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
32 | 1 | RV1 | Varistor | Device:Varistor | Resistor_SMD:R_0805_2012Metric | https://cz.mouser.com/datasheet/2/87/eaton_mlvc_general_type_multilayer_varistor_esd_su-1994298.pdf |  | 10.94 | MLVC08V048C080 | 504-MLVC08V048C080 |  | SUBCKT | ${KICAD7_SYMBOL_DIR}/Simulation_SPICE.sp | kicad_builtin_varistor | threshold=1k | 1=A 2=B | https://cz.mouser.com/ProductDetail/Bussmann-Eaton/MLVC08V048C080?qs=pUKx8fyJudBexU4jlp%252BVjg%3D%3D
33 | 1 | SW1 | 1825027-2 | Switch:SW_MEC_5E | Button_Switch_THT:SW_Tactile_SPST_Angled_PTS645Vx39-2LFS | https://cz.mouser.com/datasheet/2/670/ts11-2944009.pdf |  | 3,36 | TS11-674-135-BK-160-RA-D | 179-TS11674135160RAD | v cimře |  |  |  |  |  | https://cz.mouser.com/ProductDetail/CUI-Devices/TS11-674-135-BK-160-RA-D?qs=t7xnP681wgWTsOwVt8p6gg%3D%3D
34 | 1 | U1 | LMR38010FDDAR | LMR38010:LMR38010FDDAR | LMR38010:LMR38010FDDAR_TEX-L | https://www.ti.com/lit/gpn/lmr38010 |  | 60,96 | LMR38010FDDAR | 595-LMR38010FDDAR |  |  |  |  |  |  | https://cz.mouser.com/ProductDetail/Texas-Instruments/LMR38010FDDAR?qs=Li%252BoUPsLEntSISRTZRSlig%3D%3D
35 | 1 | U2 | UA78M33CKVURG3 | Regulator_Linear:LM78M05_TO252 | Package_TO_SOT_SMD:TO-252-2 | https://www.ti.com/lit/ds/symlink/ua78m.pdf?ts=1708768034467 |  | 13,8 | UA78M33CKVURG3 | 595-UA78M33CKVURG3 |  |  |  |  |  |  | https://cz.mouser.com/ProductDetail/Texas-Instruments/UA78M33CKVURG3?qs=0O%2FZFlpUpJXrDg4gfD1Q2g%3D%3D
36 | 2 | U3, U4 | MP1917AGR-P | MiSPiZ-rescue:MP1917AGR-Z-2021-11-05_20-06-35 | Footprints:QFN-4x4_MP1917A_MNP | https://cz.mouser.com/datasheet/2/277/MP1917A-2945459.pdf |  | 52 | MP1917AGR-Z | 946-MP1917AGR-P | V CIMŘE 3KS |  |  |  |  |  | https://cz.mouser.com/ProductDetail/Monolithic-Power-Systems-MPS/MP1917AGR-P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
37 | 1 | U5 | MCP1501T-25E/CHY | Reference_Voltage:MCP1501-12xCH | Package_TO_SOT_SMD:SOT-23-6 | https://cz.mouser.com/datasheet/2/268/MCP1501_Data_Sheet_DS20005474F-2932251.pdf |  | 18,07 | MCP1501T-25E/CHY | 579-MCP1501T-25E/CHY |  |  |  |  |  |  | https://cz.mouser.com/ProductDetail/Microchip-Technology/MCP1501T-25E-CHY?qs=8cKuZ6Ok2lamKE%2FJSRA5Gw%3D%3D
38 | 1 | U6 | ATSAME51J18A-A | MCU_Microchip_SAME:ATSAME51J18A-A | Package_DFN_QFN:QFN-64-1EP_9x9mm_P0.5mm_EP4.7x4.7mm | http://ww1.microchip.com/downloads/en/DeviceDoc/60001507E.pdf |  | 127 | ATSAME51J18A-AU | 556-ATSAME51J18AAU | v cimře |  |  |  |  |  | https://cz.mouser.com/ProductDetail/Microchip-Technology/ATSAME51J18A-AUT?qs=HXFqYaX1Q2wD9heWrczRPQ%3D%3D
39 | 1 | U7 | INA241B1IDDFR | Amplifier_Current:INA240A2D | Package_TO_SOT_SMD:TSOT-23-8 | https://www.ti.com/lit/ds/symlink/ina241a.pdf?ts=1708416613744 |  | 63.36 | INA241B1IDDFR | 595-INA241B1IDDFR |  |  |  |  |  |  | https://cz.mouser.com/ProductDetail/Texas-Instruments/INA241B1IDDFR?qs=IPgv5n7u5Qb8VGovuCsC%2FQ%3D%3D
40 | 1 | U8 | TCAN334G | Interface_CAN_LIN:TCAN334G | Package_TO_SOT_SMD:SOT-23-8 | http://www.ti.com/lit/ds/symlink/tcan337.pdf |  | 84,66 | TCAN334GDCNT | 595-TCAN334GDCNT |  |  |  |  |  |  | https://cz.mouser.com/ProductDetail/Texas-Instruments/TCAN334GDCNT?qs=gMfM3zrbS4oTuX6xdwyS1w%3D%3D
41 | 1 | U9 | MCP9700T-ELT | MiSPiZ-rescue:MCP9700T-ELT-Sensor_Temperature | Package_TO_SOT_SMD:SOT-353_SC-70-5 | https://cz.mouser.com/datasheet/2/268/MCP9700_Family_Data_Sheet_DS20001942-3132871.pdf |  | 6,48 | MCP9700T-E/LT | 579-MCP9700T-E/LT |  |  |  |  |  |  | https://cz.mouser.com/ProductDetail/Microchip/MCP9700T-E-LT?qs=RnzODY3cU8tW7jSxAPzBuw%3D%3D
42 | 2 | U10, U11 | AH49FZ3-G1 | Sensor_Magnetic:DRV5055A1xLPGxQ1 | Package_TO_SOT_THT:TO-92_Inline | https://www.diodes.com/assets/Datasheets/AH49F.pdf |  | 24.48 | AH49FZ3-G1 | 621-AH49FZ3-G1 |  |  |  |  |  |  | https://cz.mouser.com/ProductDetail/Diodes-Incorporated/AH49FZ3-G1?qs=dZoB6MK9LKPUjOBJDQRw%2FA%3D%3D
43 | 1 | Y1 | Crystal EA2532 20MEG | Device:Crystal_GND24 | Crystal:Crystal_SMD_EuroQuartz_MT-4Pin_3.2x2.5mm | https://cz.mouser.com/datasheet/2/3/EA2532-2508887.pdf |  | 12,07 | EA2532QA18-20.000M TR | 669-EA2532QA18-20T | V CIMŘE 6KS |  |  |  |  |  | https://cz.mouser.com/ProductDetail/Ecliptek-Abracon/EA2532QA18-20.000M-TR?qs=6L0a8dsrcQc%2FbW28Tk5FnQ%3D%3D

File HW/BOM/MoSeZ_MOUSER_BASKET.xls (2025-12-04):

SHOPPING BASKET
This is not an invoice
04-Apr-24 03:50:32
 | Mouser No | Mfr. No | Manufacturer | Customer No | Description | RoHS | Lifecycle | Order Qty. | Price (CZK) | Ext.: (CZK)
1 | 490-CMI-1295IC-0385T | CMI-1295IC-0385T | CUI Devices |  | Piezo Buzzers & Audio Indicators buzzer, 12 mm x 9.5 mm deep, M, 3 V, 85 dB, Through Hole, Integrated Circuit Audio Indicator |  |  | 1 | 24,00 Kč | 24,00 Kč
2 | 667-EEU-FS1K151B | EEU-FS1K151B | Panasonic |  | Aluminium Electrolytic Capacitors - Radial Leaded 80VDC 150uF 930mA Polar | RoHS Compliant |  | 2 | 18,07 Kč | 36,14 Kč
3 | 80-C0603C223K1R | C0603C223K1RACTU | KEMET |  | Multilayer Ceramic Capacitors MLCC - SMD/SMT 100V 0.022uF X7R 0603 10% | RoHS Compliant |  | 7 | 2,23 Kč | 15,61 Kč
4 | 187-CL21A226MAYNNNE | CL21A226MAYNNNE | Samsung Electro-Mechanics |  | Multilayer Ceramic Capacitors MLCC - SMD/SMT 22uF+/-20% 25V X5R 2 0805 | RoHS Compliant |  | 7 | 5,59 Kč | 39,13 Kč
5 | 187-CL21A225KAFNNNG | CL21A225KAFNNNG | Samsung Electro-Mechanics |  | Multilayer Ceramic Capacitors MLCC - SMD/SMT 2.2uF+/-10% 25V X5R 0805 | RoHS Compliant |  | 3 | 2,69 Kč | 8,07 Kč
6 | 810-CGA3E2X7R2A102K | CGA3E2X7R2A102K080AA | TDK |  | Multilayer Ceramic Capacitors MLCC - SMD/SMT CGA 0603 100V 1000pF X7R 10% AEC-Q200 | RoHS Compliant |  | 4 | 2,23 Kč | 8,92 Kč
7 | 603-SMAJ48CA/TR13 | SMAJ48CA/TR13 | YAGEO |  | ESD Suppressors / TVS Diodes SMAJ DO-214AC 48V 77.4V | RoHS Compliant By Exemption |  | 3 | 6,70 Kč | 20,10 Kč
8 | 637-BYG10D | BYG10D | Diotec Semiconductor |  | Rectifiers Diode, SMA, 200V, 1.5A | RoHS Compliant By Exemption |  | 2 | 3,58 Kč | 7,16 Kč
9 | 576-2920L150/60MR | 2920L150/60MR | Littelfuse |  | Resettable Fuses - PPTC PTC 60V POLYFUSE SURF MOUNT 2920 1.50A | RoHS Compliant | New Product | 2 | 19,20 Kč | 38,40 Kč
10 | 523-G800W304018EU | G800W304018EU | Amphenol |  | Headers & Wire Housings Pin Header 2.54mm Pitch STR DIP,1x4Pin,FULL G/F,NY6T,6.1mm*2.5mm*3.0mm,Color-Black,BAG | RoHS Compliant |  | 1 | 2,45 Kč | 2,45 Kč
11 | 649-221111-00010T4LF | 20021111-00010T4LF | Amphenol |  | Headers & Wire Housings 1.27x1.27mm BTB, Hdr Unshrd,Vert,T/H, 10 | RoHS Compliant |  | 1 | 16,51 Kč | 16,51 Kč
12 | 652-SRN6045HA-470M | SRN6045HA-470M | Bourns |  | Power Inductors - SMD Ind,6x6x4.7mm,47uH+/-20%,1A,semi-shd | RoHS Compliant |  | 1 | 4,68 Kč | 4,68 Kč
13 | 652-SRN2010TA-100M | SRN2010TA-100M | Bourns |  | Power Inductors - SMD 10uH 20% 0.45A non-shdSMD AEC-Q200 | RoHS Compliant |  | 1 | 4,46 Kč | 4,46 Kč
14 | 621-DMN2310U-7 | DMN2310U-7 | Diodes Incorporated |  | MOSFET MOSFET BVDSS: 8V-24V SOT23 T&R 3K | RoHS Compliant |  | 1 | 5,14 Kč | 5,14 Kč
15 | 726-ISC080N10NM6ATMA | ISC080N10NM6ATMA1 | Infineon |  | MOSFET TRENCH >=100V | RoHS Compliant |  | 4 | 34,32 Kč | 137,28 Kč
16 | 71-CRCW060310K0FKECC | CRCW060310K0FKECC | Vishay |  | Thick Film Resistors - SMD 1/10Watt 10Kohms 1% Commercial Use | RoHS Compliant By Exemption |  | 12 | 0,36 Kč | 4,32 Kč
17 | 667-ERJ-P06J3R3V | ERJ-P06J3R3V | Panasonic |  | Thick Film Resistors - SMD 0805 3.3ohms 0.5W 5% Tol AEC-Q200 | RoHS Compliant By Exemption |  | 7 | 2,69 Kč | 18,83 Kč
18 | 504-MSMA2512R0120FGM | MSMA2512R0120FGM | Eaton |  | Current Sense Resistors - SMD MSMA, 2512 SIZE, 3 Watt, 12 mohm, 50 TCR MnCu Metal AEC-Q | RoHS Compliant | New Product | 1 | 7,82 Kč | 7,82 Kč
19 | 504-MLVC08V048C080 | MLVC08V048C080 | Eaton |  | Varistors 48VDC 080PF | RoHS Compliant |  | 1 | 10,94 Kč | 10,94 Kč
20 | 595-LMR38010FDDAR | LMR38010FDDAR | Texas Instruments |  | Switching Voltage Regulators SIMPLE SWITCHER® 80-V, 1.0-A, 2.2-MHz step-down converter with 40-uA IQ 8-SO PowerPAD -40 to 150 | RoHS Compliant |  | 1 | 60,96 Kč | 60,96 Kč
21 | 595-UA78M33CKVURG3 | UA78M33CKVURG3 | Texas Instruments |  | Linear Voltage Regulators 3.3 V 500mA Fix Pos Voltage Regulator | RoHS Compliant |  | 1 | 13,18 Kč | 13,18 Kč
22 | 946-MP1917AGR-P | MP1917AGR-P | Monolithic Power Systems (MPS) |  | Gate Drivers "100V, 4A, High Frequency Half-Bridge Gate Driver" | RoHS Compliant |  | 2 | 51,12 Kč | 102,24 Kč
23 | 579-MCP1501T-25E/CHY | MCP1501T-25E/CHY | Microchip |  | Voltage References Precision Buffered Voltage Reference | RoHS Compliant |  | 1 | 18,07 Kč | 18,07 Kč
24 | 595-INA241B1IDDFR | INA241B1IDDFR | Texas Instruments |  | Current Sense Amplifiers -5-V to 110-V bidirectional high-precision current sense amplifier with enhanced PWM rejection 8-SOT-23-THIN -40 to 125 | RoHS Compliant | New Product | 1 | 63,36 Kč | 63,36 Kč
25 | 595-TCAN334GDCNT | TCAN334GDCNT | Texas Instruments |  | CAN Interface IC 3.3-V CAN Transceivers with CAN FD (Flexible Data Rate) 8-SOT-23 -40 to 125 | RoHS Compliant |  | 1 | 80,64 Kč | 80,64 Kč
26 | 579-MCP9700T-E/LT | MCP9700T-E/LT | Microchip |  | Board Mount Temperature Sensors Tiny 10mV/oC | RoHS Compliant |  | 1 | 6,70 Kč | 6,70 Kč
27 | 621-AH49FZ3-G1 | AH49FZ3-G1 | Diodes Incorporated |  | Board Mount Hall Effect/Magnetic Sensors Linear Hall Effect 10V Vcc 400mW | RoHS Compliant |  | 2 | 24,48 Kč | 48,96 Kč
28 | 669-EA2532QA18-20T | EA2532QA18-20.000M TR | ABRACON |  | Crystals 20MHz 18pF 15ppm -40C +85C | RoHS Compliant |  | 1 | 11,11 Kč | 11,11 Kč
By submitting your order you agree to these terms and conditions. (https://cz.mouser.com/saleterms) |  |  |  |  |  |  |  |  | Merchandise: | 815,18 Kč
Prices are reflected at the date and time shown. |  |  |  |  |  |  |  |  | Delivery Charge: | 500,00 Kč
 |  |  |  |  |  |  |  |  | Back-order Delivery: | 0,00 Kč

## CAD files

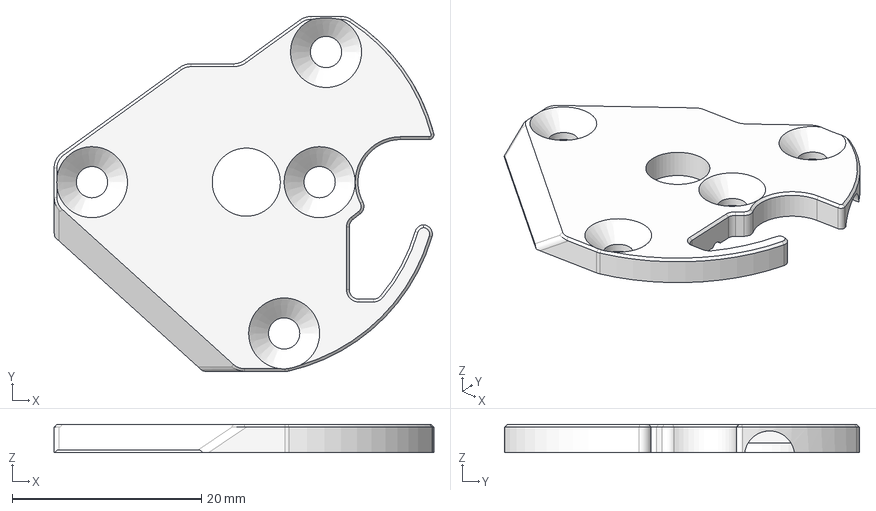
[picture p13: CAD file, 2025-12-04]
3D_Printer_Projects/Cable_hall_holder_1.01/Assembly 1 - Díl3^A760-920.step
40.1 x 37.5 x 3.00 mm

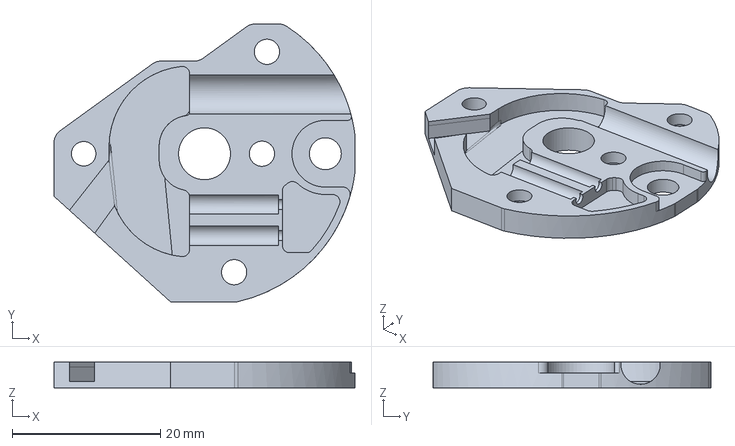
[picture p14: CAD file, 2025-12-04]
3D_Printer_Projects/Cable_hall_holder_1.01/Assembly 1 - Part 2 - Surface 0.step
40.6 x 37.5 x 3.50 mm

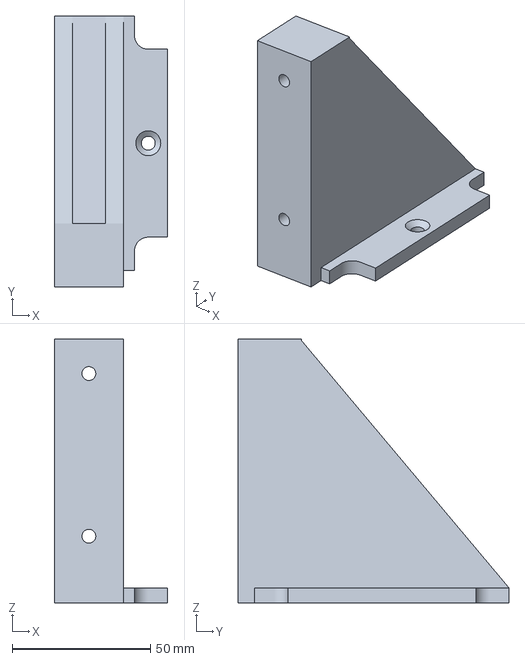
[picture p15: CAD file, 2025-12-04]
3D_Printer_Projects/Incremental_sensor_bridge/inc_sens_brdg.3mf
41.0 x 98.0 x 95.5 mm

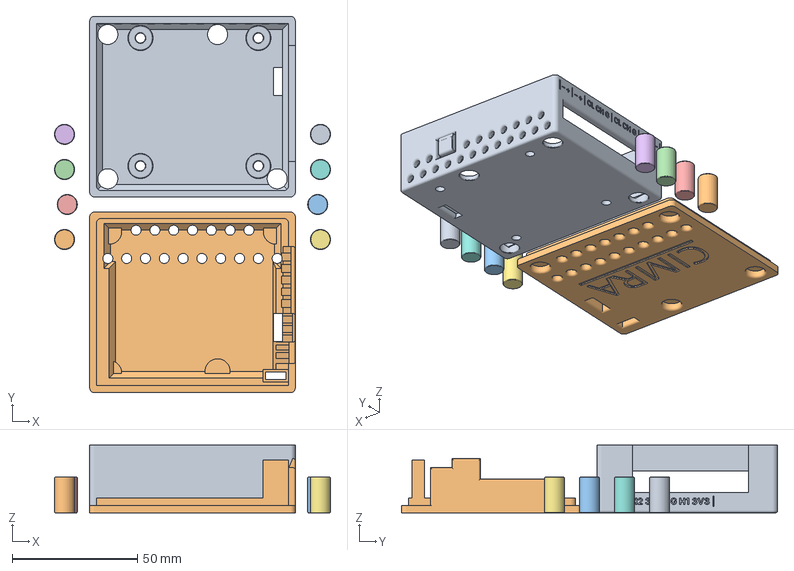
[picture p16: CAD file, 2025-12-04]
3D_Printer_Projects/MoSeZ_BOX_v1.08/MoSeZ_BOX_v1.08.3mf
110.0 x 150.0 x 27.0 mm
MoSeZ_BOX - Box
MoSeZ_BOX - Cover
MoSeZ_BOX - Part 3 x 2
MoSeZ_BOX - Part 4 x 2
MoSeZ_BOX - Part 5 x 2
MoSeZ_BOX - Part 6 x 2

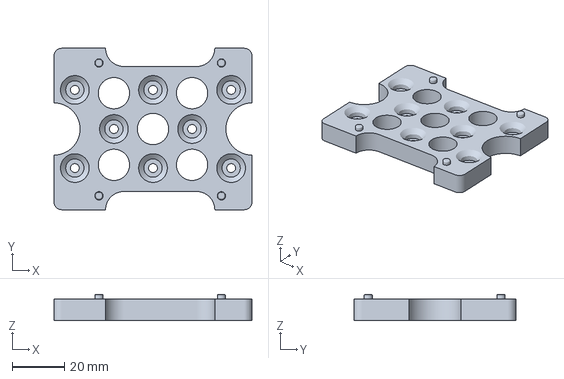
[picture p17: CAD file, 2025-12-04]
3D_Printer_Projects/MoSeZ_pcb_holders/MoSeZ_HOLDER.3mf
76.0 x 62.0 x 10.1 mm

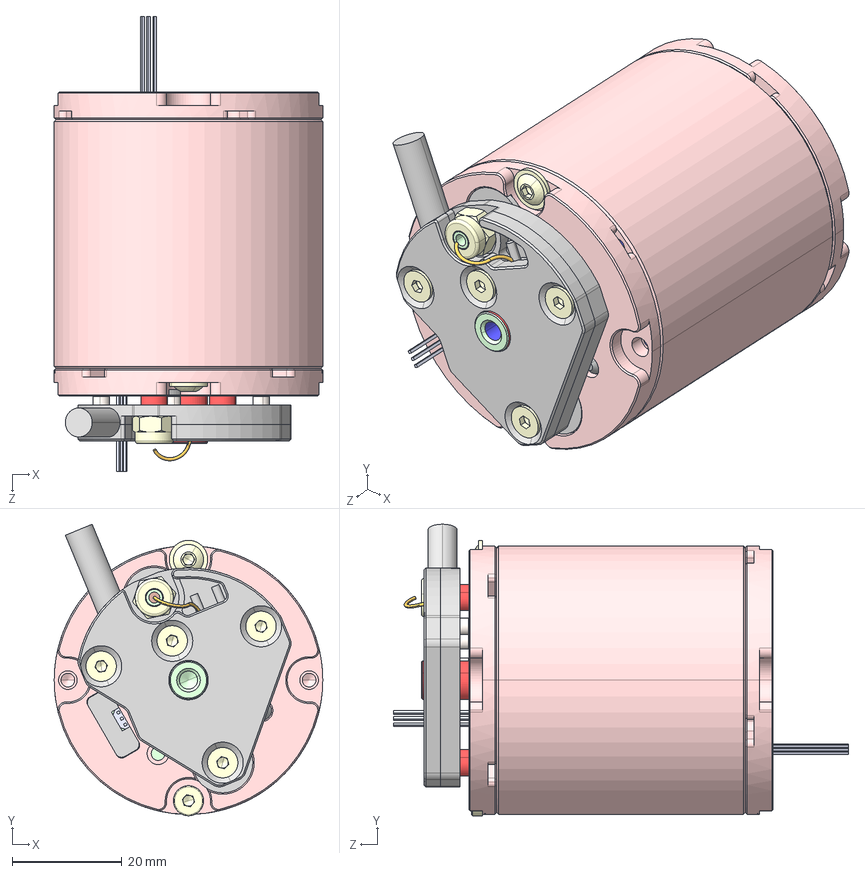
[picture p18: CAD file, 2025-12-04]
3D_Printer_Projects/Original_vibrator/A760-920.STEP
49.0 x 53.2 x 83.0 mm
P760-917-001
P760-919-002
P760-919-003
P760-919-004
P760-919-005^A760-920
P760-917-007
Cívka^A760-920
Linear Hall Sensor DRV5053-Q1 x 2
Magnet^A760-920 x 2
GFM-0507-04^A760-920 x 2
GFM-0709-12^A760-920 x 2
Matice - ISO 10511_M4
Sroub - ISO 7380-2_Sroub M3 x 8
Sroub - DIN 7984_ Sroub_M 3 x 8
Aliexpress A 2.5 Silicone Rubber Snap-on Hole Plug^A760-920 x 2
Díl1^A760-920
Matice - ISO 4035_Matice M3 x 3
Díl3^A760-920
Sroub - ISO 10642_Sroub M3 x 8 Z8 x 3
Sroub - ISO 10642_Sroub M3 x 12 Z12

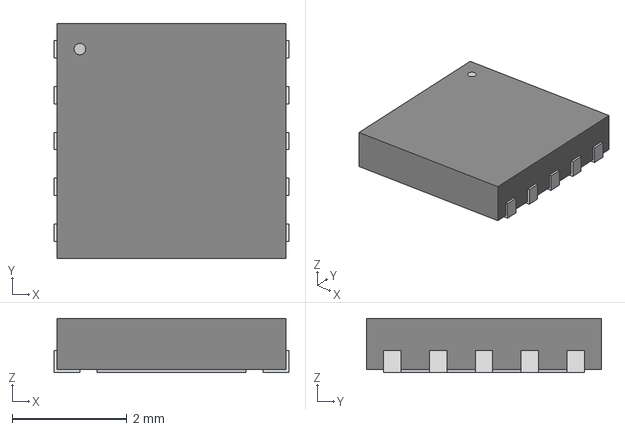
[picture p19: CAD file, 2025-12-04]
HW/3D_Models/QFN-4x4_MP1917A_MNP.step
4.09 x 4.09 x 0.942 mm

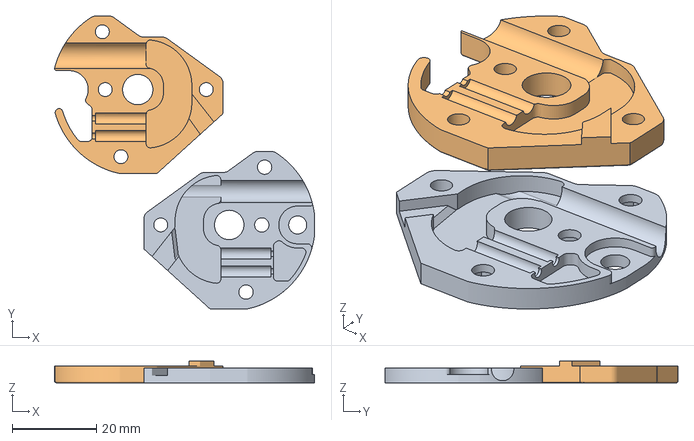
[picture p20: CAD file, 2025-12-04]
3D_Printer_Projects/Cable_hall_holder_1.01/hall_holder_1.01.3mf
61.9 x 69.7 x 5.15 mm
hall_holder - Part 2
hall_holder - hall_holder_TOP

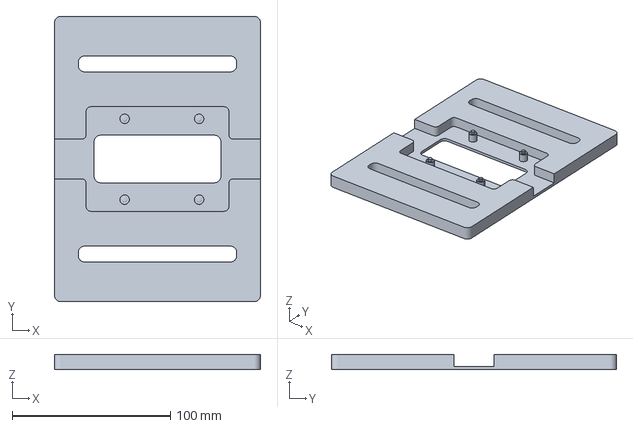
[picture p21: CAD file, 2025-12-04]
3D_Printer_Projects/MoSeZ_pcb_holders/PCB paste holder.3mf
130.0 x 180.0 x 9.63 mm

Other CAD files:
3D_Printer_Projects/Cable_hall_holder_1.01/Assembly 1 - Part 2.step

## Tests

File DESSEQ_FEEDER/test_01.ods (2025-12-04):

Moving M6 nuts left to right |  |  |  |  |  |  |  |  | Moving M6 nuts left to right |  |  |  |  |  |  |  | Moving M6 nuts left to right
15 Hz |  |  |  |  |  |  |  |  | L. Actuator |  |  | R Actuator |  |  |  |  | L. Actuator |  |  | R Actuator
L. Actuator |  |  | R Actuator |  |  |  |  |  | Amplitude (mm) | Offset (mm) | Phase (°) | Amplitude (mm) | Offset (mm) | Phase (°) | Time(s) |  | Amplitude (mm) | Offset (mm) | Phase (°) | Amplitude (mm) | Offset (mm) | Phase (°) | Time(s)
Amplitude (mm) | Offset (mm) | Phase (°) | Amplitude (mm) | Offset (mm) | Phase (°) | Time(s) | Note | 15Hz | 3.5 | 4.5 | 0 | 0 | 0 | 0 | 16.87 | 15Hz | 2.5 | 5.5 | 0 | 0.5 | 1.5 | 270 | 22.33
3.5 | 4.5 | 0 | 0 | 0 | 0 | 16.87 |  |  | 2.5 | 5.5 | 0 | 0 | 0 | 0 | 30.15 |  | 2.5 | 5.5 | 0 | 2 | 3 | 270 | 19.5
2.5 | 5.5 | 0 | 0 | 0 | 0 | 30.15
1.5 | 6.5 | 0 | 0 | 0 | 0 | >40 |  | 20Hz | 3.5 | 4.5 | 0 | 0 | 0 | 0 | 8.5 | 20Hz | 2.5 | 5.5 | 0 | 0.5 | 1.5 | 270 | 28.35
0.5 | 7.5 | 0 | 0 | 0 | 0 | N/A |  |  | 2.5 | 5.5 | 0 | 0 | 0 | 0 | 13.84
0.5 | 7.5 | 0 | 0.5 | 1.5 | 0 | N/A |  |  | 1.5 | 6.5 | 0 | 0 | 0 | 0 | 19.2 | 25 Hz | 1.0 | 7.0 | 0 | 1 | 2 | 270 | 14.44
2.5 | 5.5 | 0 | 0.5 | 1.5 | 90 | 28.36
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

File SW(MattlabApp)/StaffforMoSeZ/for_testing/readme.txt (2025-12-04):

Staff Executable

1. Prerequisites for Deployment 

Verify that MATLAB Runtime(R2023b) is installed.   
If not, you can run the MATLAB Runtime installer.
To find its location, enter
  
    >>mcrinstaller
      
at the MATLAB prompt.

Alternatively, download and install the Linux version of the MATLAB Runtime for R2023b 
from the following link on the MathWorks website:

    https://www.mathworks.com/products/compiler/mcr/index.html
   
For more information about the MATLAB Runtime and the MATLAB Runtime installer, see 
"Distribute Applications" in the MATLAB Compiler documentation  
in the MathWorks Documentation Center.

2. Files to Deploy and Package

Files to Package for Standalone 
================================
-Staff 
-run_Staff.sh (shell script for temporarily setting environment variables and executing 
               the application)
   -to run the shell script, type
   
       ./run_Staff.sh <mcr_directory> <argument_list>
       
    at Linux or Mac command prompt. <mcr_directory> is the directory 
    where MATLAB Runtime(R2023b) is installed or the directory where 
    MATLAB is installed on the machine. <argument_list> is all the 
    arguments you want to pass to your application. For example, 

    If you have MATLAB Runtime(R2023b) installed in 
    /mathworks/home/application/R2023b, run the shell script as:
    
       ./run_Staff.sh /mathworks/home/application/R2023b
       
    If you have MATLAB installed in /mathworks/devel/application/matlab, 
    run the shell script as:
    
       ./run_Staff.sh /mathworks/devel/application/matlab
-MCRInstaller.zip
    Note: if end users are unable to download the MATLAB Runtime using the
    instructions in the previous section, include it when building your 
    component by clicking the "Runtime included in package" link in the
    Deployment Tool.
-This readme file 

3. Definitions

For information on deployment terminology, go to
https://www.mathworks.com/help and select MATLAB Compiler >
Getting Started > About Application Deployment >
Deployment Product Terms in the MathWorks Documentation
Center.

4. Appendix 

A. Linux systems:
In the following directions, replace MR/R2023b by the directory on the target machine 
   where MATLAB is installed, or MR by the directory where the MATLAB Runtime is 
   installed.

(1) Set the environment variable XAPPLRESDIR to this value:

MR/R2023b/X11/app-defaults

(2) If the environment variable LD_LIBRARY_PATH is undefined, set it to the following:

MR/R2023b/runtime/glnxa64:MR/R2023b/bin/glnxa64:MR/R2023b/sys/os/glnxa64:MR/R2023b/sys/opengl/lib/glnxa64

If it is defined, set it to the following:

${LD_LIBRARY_PATH}:MR/R2023b/runtime/glnxa64:MR/R2023b/bin/glnxa64:MR/R2023b/sys/os/glnxa64:MR/R2023b/sys/opengl/lib/glnxa64

    For more detailed information about setting the MATLAB Runtime paths, see Package and 
   Distribute in the MATLAB Compiler documentation in the MathWorks Documentation Center.

        NOTE: To make these changes persistent after logout on Linux 
              or Mac machines, modify the .cshrc file to include this  
              setenv command.
        NOTE: The environment variable syntax utilizes forward 
              slashes (/), delimited by colons (:).  
        NOTE: When deploying standalone applications, you can
              run the shell script file run_Staff.sh 
              instead of setting environment variables. See 
              section 2 "Files to Deploy and Package".

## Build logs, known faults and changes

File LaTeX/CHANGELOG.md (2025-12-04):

Našli jste chybu? Neváhejte nás kontaktovat a společně můžeme vytvořit lepší verzi.

### v1.4 (6.6.2023)
- Juřík
  - BP nahrazena ZPR se všemi náležitostmi
- Formánek
  - Opraven příkaz *nadpis*, aby nezvětšoval font ve zbytku dokumentu
- Vítek
  - Změněn styl citací na [ISO690](citace.zcu.cz)

### v1.3 (24.5.2022)
- Juřík
  - Opraveny odkazy na poznámky pod čarou a číslování rovnic.
- Vítek
  - Balíček `siunitx` vypisuje čísla s desetinnou čárkou místo tečky.

### v1.2 (24.4.2022)
- Juřík
  - Opraveno číslování obrázků napříč více kapitolami. Vylepšeny přílohy.

### v1.1 (14.3.2022)  
- Juřík
  - Opravena zadávající katedra na titulní straně.

### v1.0 (17.2.2022)  
- Juřík
  - Šablona upravena dle fakultních předpisů. Přidán návod na LaTeX.

### v0.2 (17.11.2021)
- Vácha, Mužík
  - Optimalizace funkčnosti pro OverLeaf

### v0.1 (27.10.2021)
- Vácha, Mužík
  - Vytvořena první varianta šablony, která vzešla ze spolupráce na BP.

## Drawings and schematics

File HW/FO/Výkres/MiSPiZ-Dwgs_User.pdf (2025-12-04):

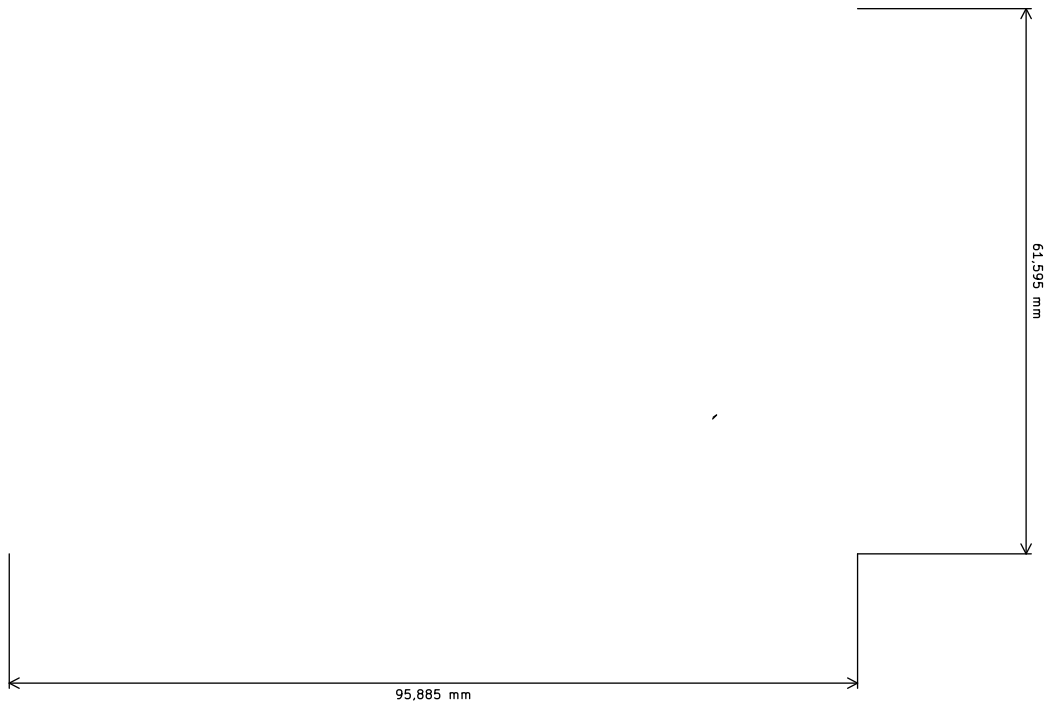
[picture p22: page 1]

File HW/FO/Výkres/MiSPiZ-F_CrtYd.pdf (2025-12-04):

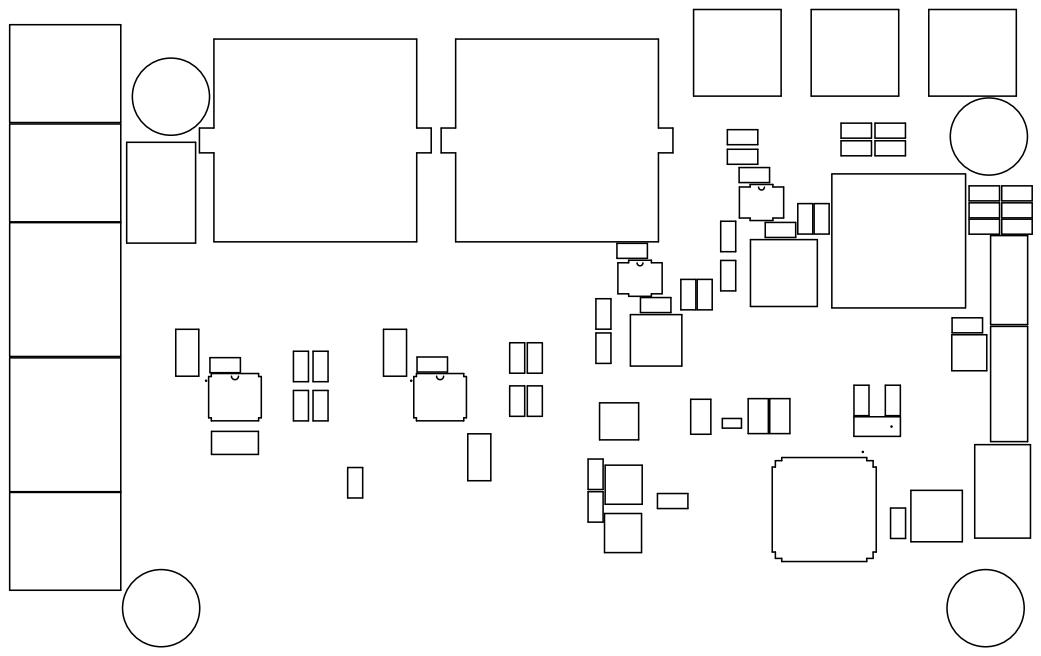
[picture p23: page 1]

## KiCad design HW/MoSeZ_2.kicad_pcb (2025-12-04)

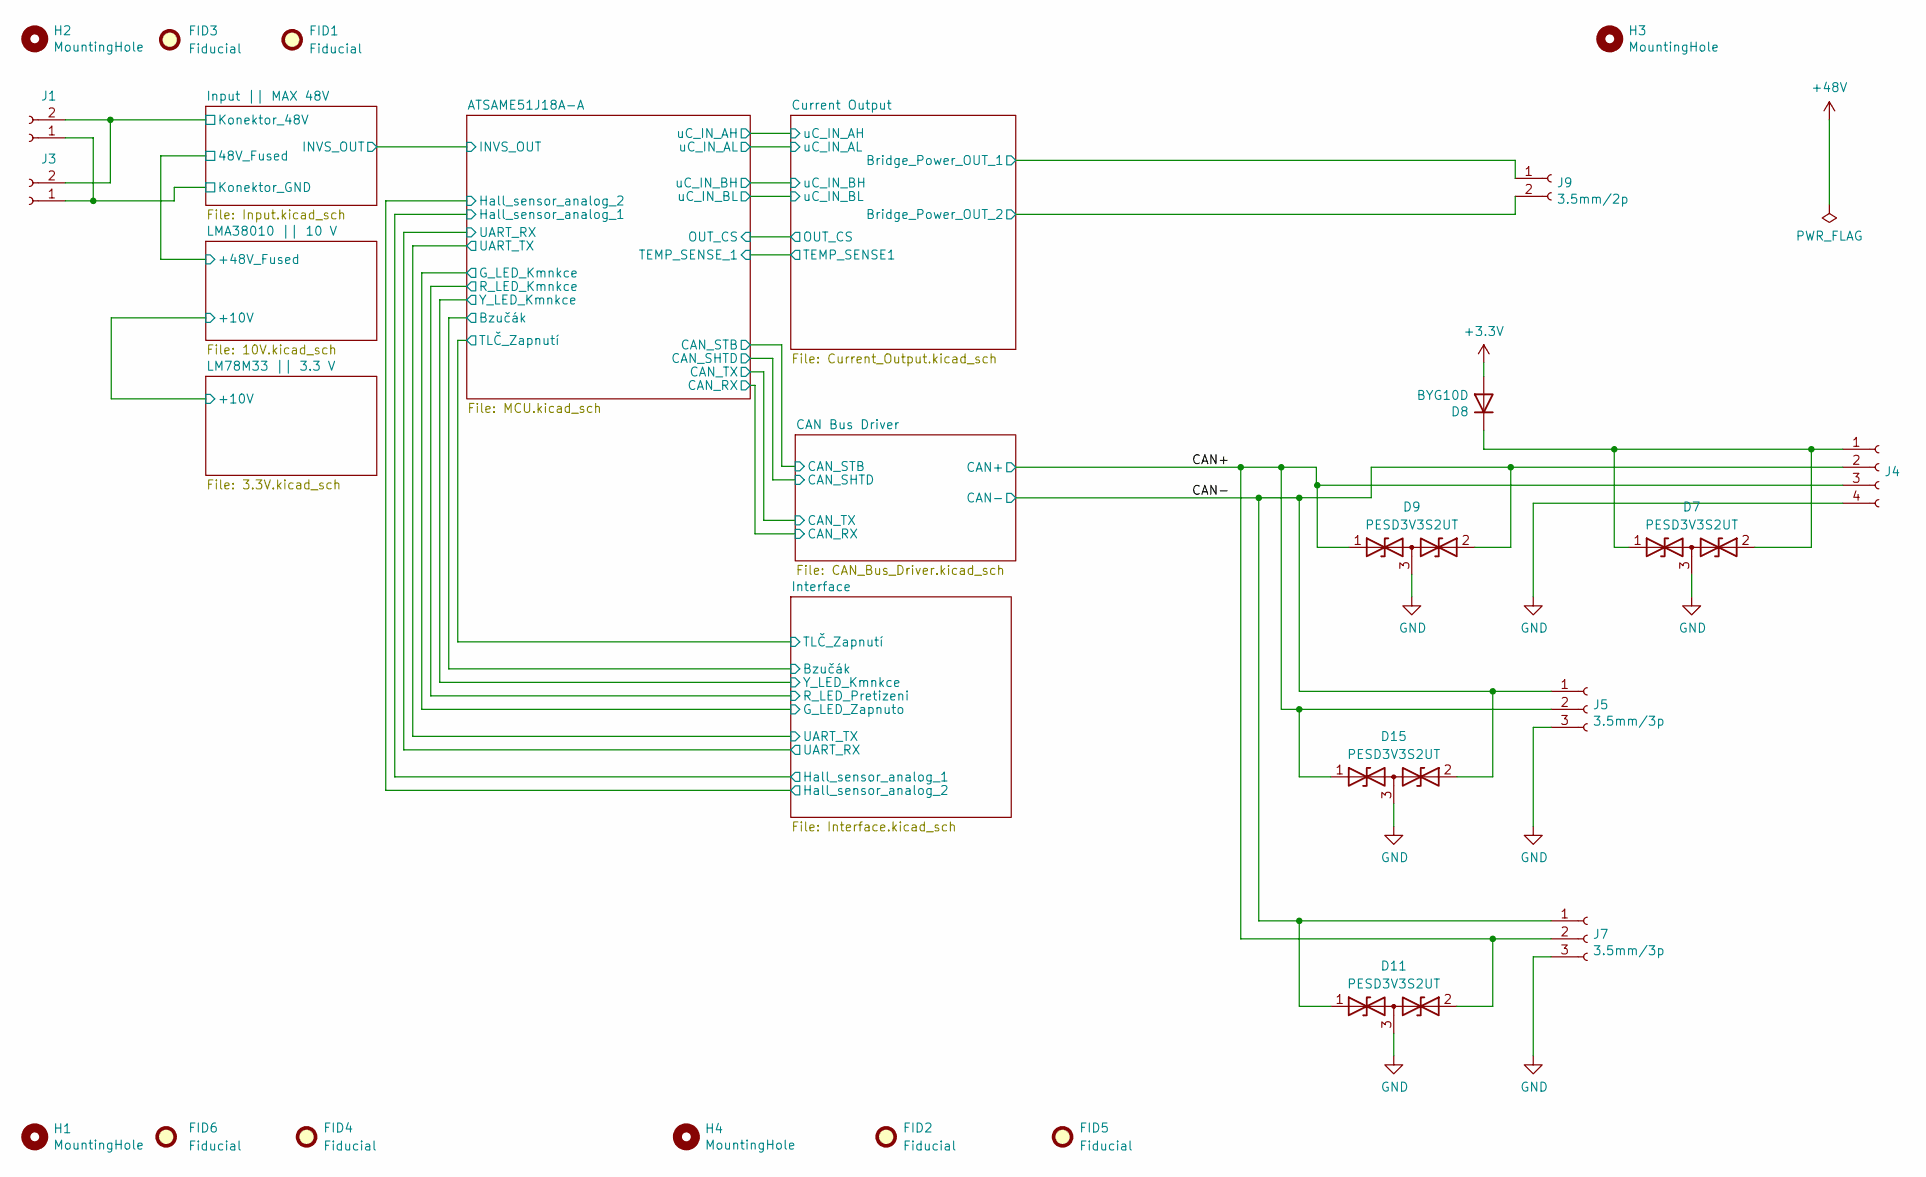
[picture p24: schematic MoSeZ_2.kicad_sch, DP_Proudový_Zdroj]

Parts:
D7, D9, D11, D15: PESD3V3S2UT; SOT-23
D8: BYG10D; D_SMA
FID1, FID2, FID3, FID4, FID5, FID6: Fiducial; Fiducial_1mm_Mask2mm
H1, H2, H3, H4: MountingHole; MountingHole_3.5mm_Pad
J1, J3, J9: 3.5mm/2p; PhoenixContact_MC_1,5_2-G-3.5_1x02_P3.50mm_Horizontal
J4: 2.54/4p; PinHeader_1x04_P2.54mm_Vertical
J5, J7: 3.5mm/3p; PhoenixContact_MC_1,5_3-G-3.5_1x03_P3.50mm_Horizontal

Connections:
+3.3V: D8.2 (A); also elsewhere on the board
+48V: J1.2, J3.2; also elsewhere on the board
/CAN+: D9.1 (A1), D11.2 (A2), D15.1 (A1), J4.3, J5.2, J7.2; also elsewhere on the board
/CAN-: D9.2 (A2), D11.1 (A1), D15.2 (A2), J4.2, J5.1, J7.1; also elsewhere on the board
/Current Output/Bridge_Power_OUT_2: J9.2; also elsewhere on the board
/Current Output/DRIVER_1_SW: J9.1; also elsewhere on the board
GND: D7.3 (common), D9.3 (common), D11.3 (common), D15.3 (common), J1.1, J3.1, J4.4, J5.3, J7.3; also elsewhere on the board
unnamed: D7.1 (A1), D7.2 (A2), D8.1 (K), J4.1

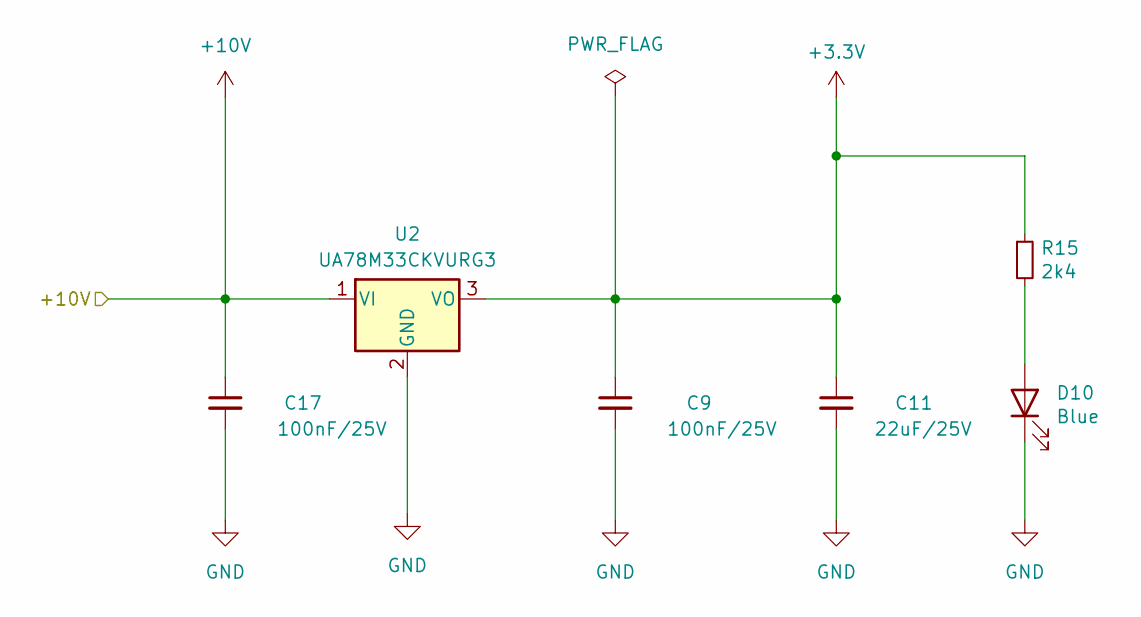
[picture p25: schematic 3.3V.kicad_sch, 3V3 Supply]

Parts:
C9, C17: 100nF/25V; C_0603_1608Metric
C11: 22uF/25V; C_0805_2012Metric
D10: Blue; D_0603_1608Metric
R15: 2k4; R_0603_1608Metric
U2: UA78M33CKVURG3; TO-252-2

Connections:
+3.3V: C9.1, C11.1, R15.1, U2.3 (VO); also elsewhere on the board
+10V: C17.1, U2.1 (VI); also elsewhere on the board
GND: C9.2, C11.2, C17.2, D10.1 (K), U2.2 (GND); also elsewhere on the board
unnamed: D10.2 (A), R15.2

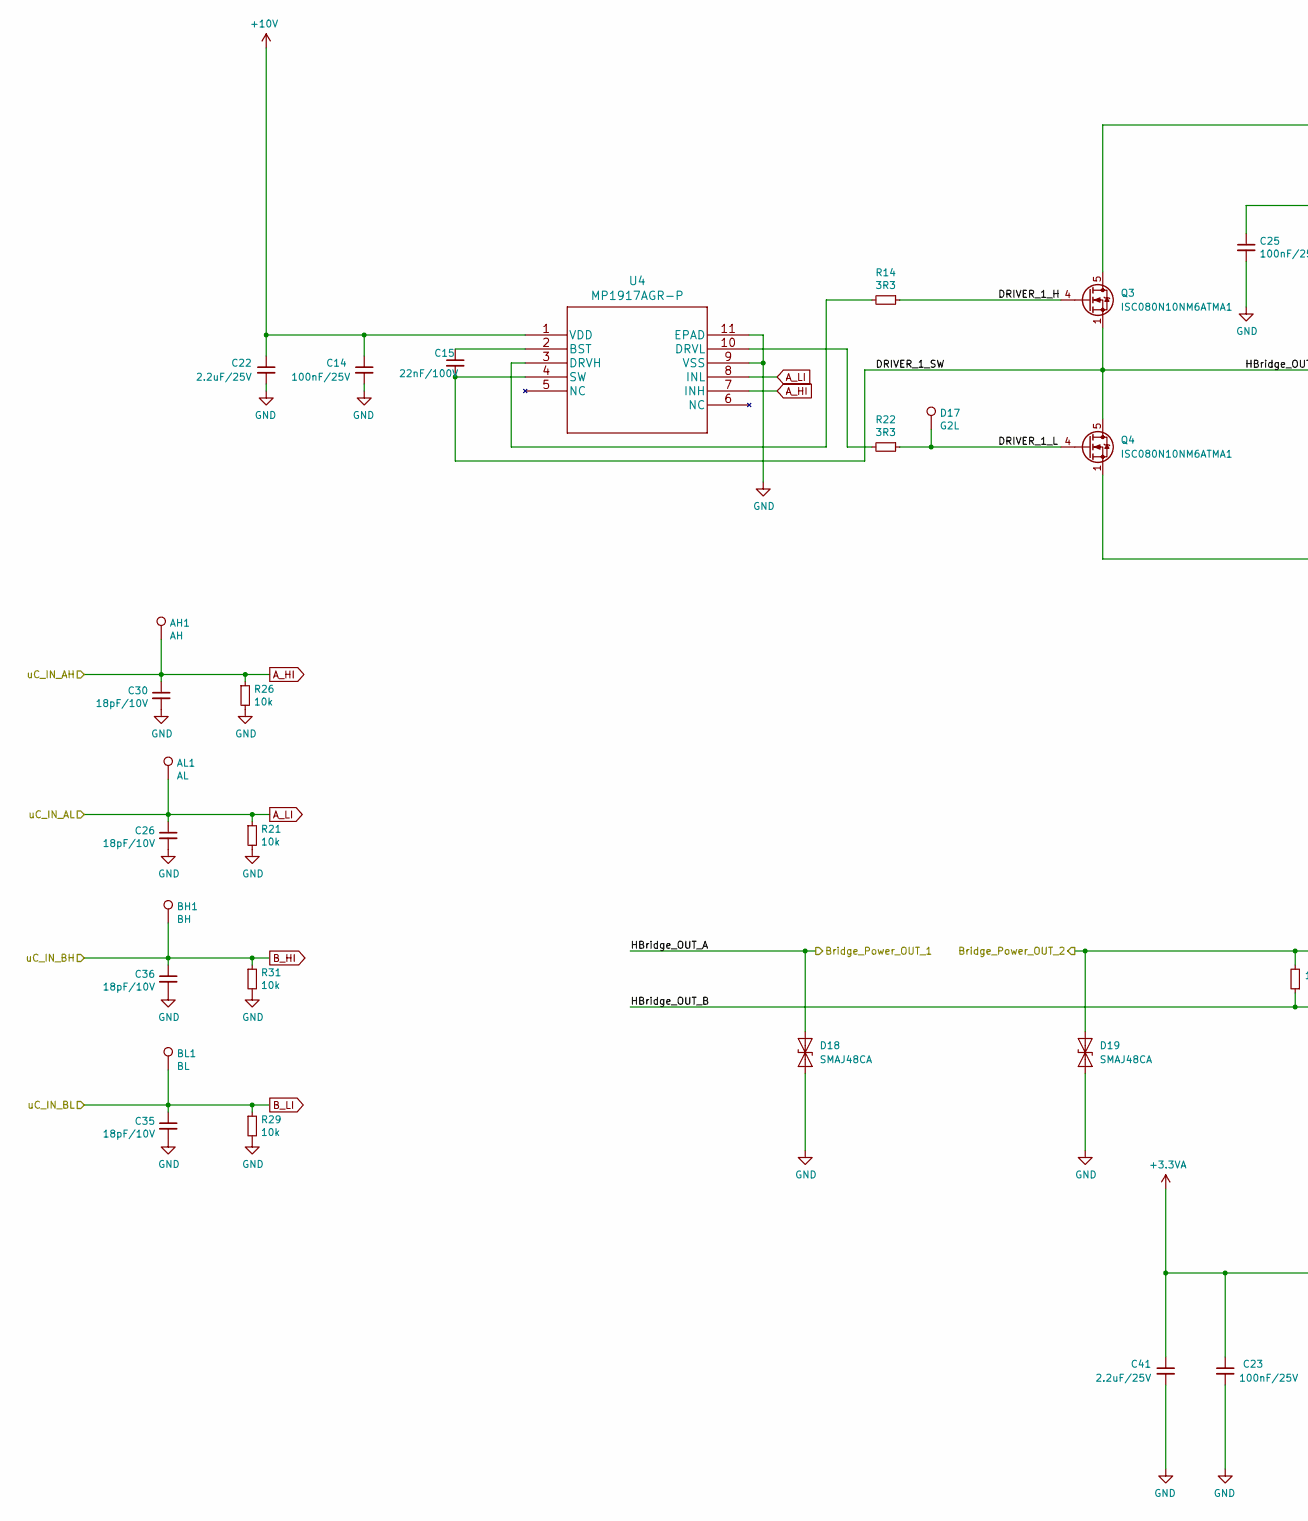
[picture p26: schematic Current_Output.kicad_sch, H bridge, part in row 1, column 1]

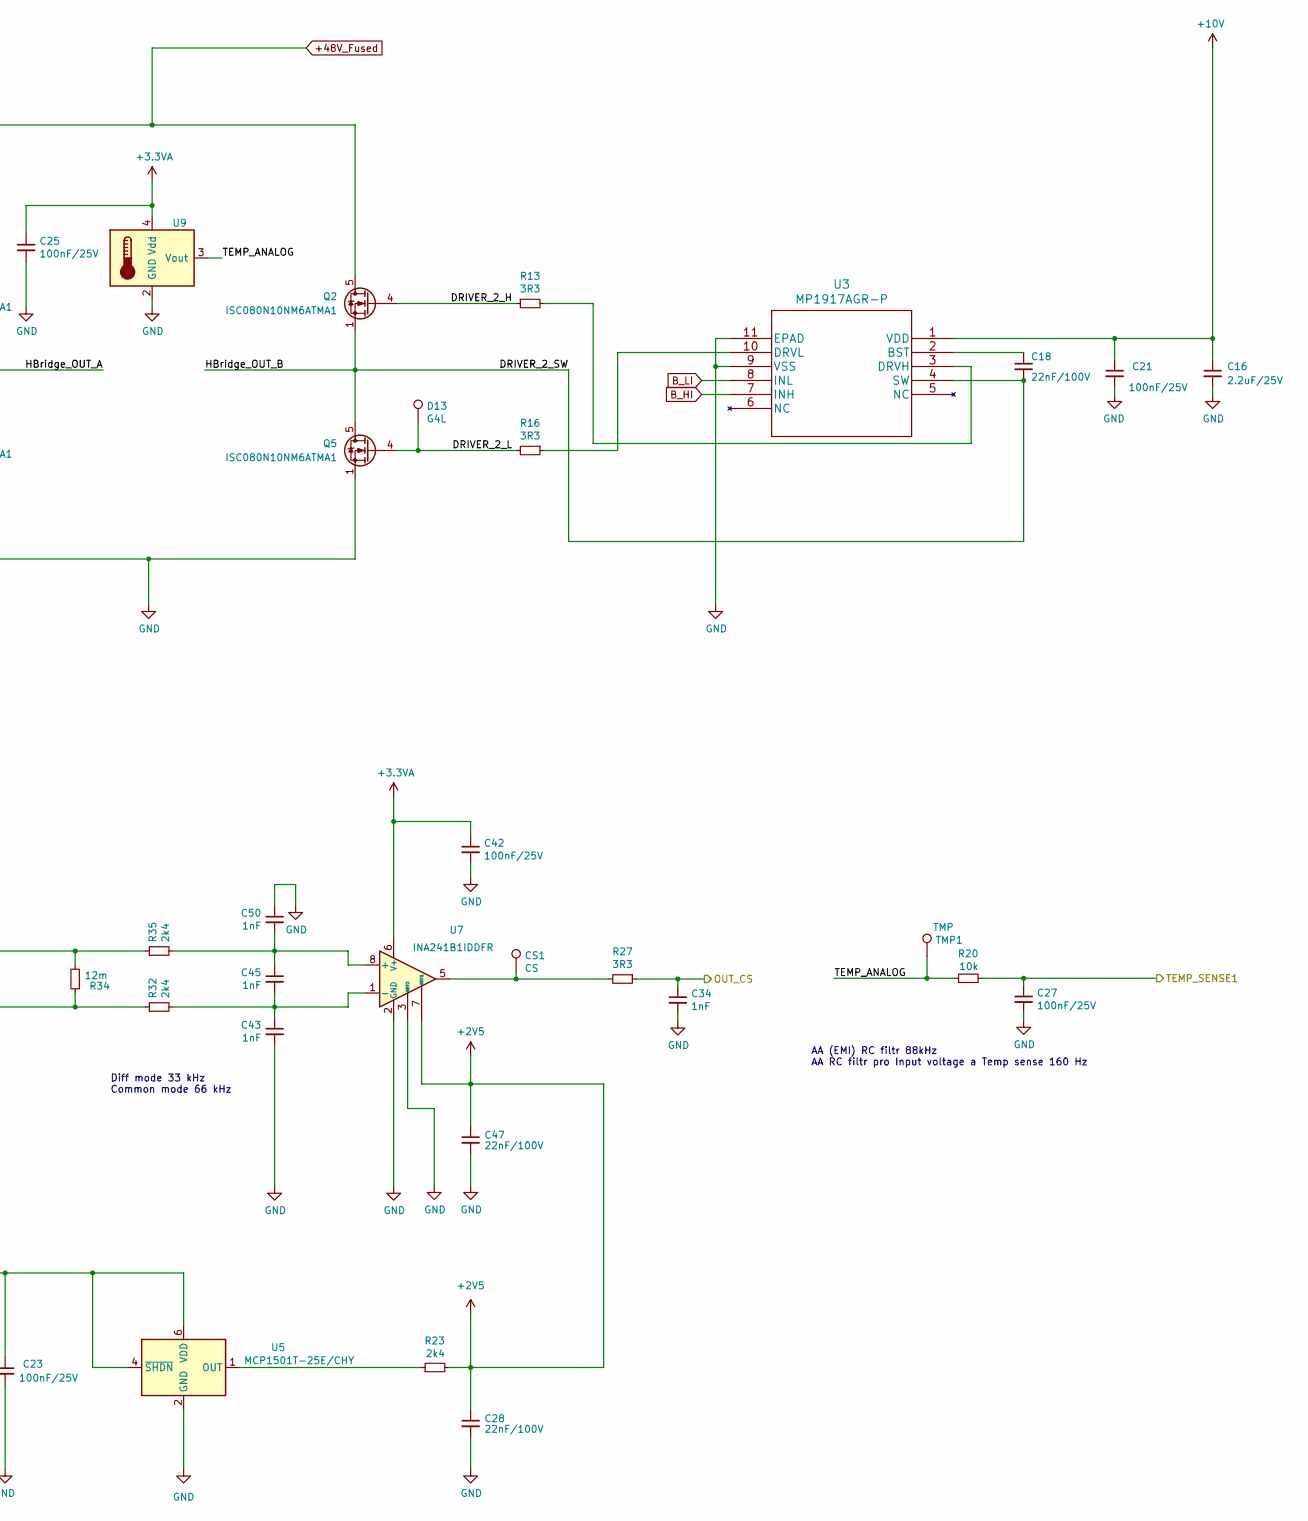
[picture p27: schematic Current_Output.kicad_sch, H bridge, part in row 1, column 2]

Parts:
AH1: AH; TestPoint_Pad_1.5x1.5mm
AL1: AL; TestPoint_Pad_1.5x1.5mm
BH1: BH; TestPoint_Pad_1.5x1.5mm
BL1: BL; TestPoint_Pad_1.5x1.5mm
C14, C21, C23, C25, C27, C42: 100nF/25V; C_0603_1608Metric
C15, C18, C28, C47: 22nF/100V; C_0603_1608Metric
C16, C22, C41: 2.2uF/25V; C_0805_2012Metric
C26, C30, C35, C36: 18pF/10V; C_0603_1608Metric
C34, C43, C45, C50: 1nF; C_0603_1608Metric
CS1: CS; TestPoint_Pad_1.5x1.5mm
D13: G4L; TestPoint_Pad_1.5x1.5mm
D17: G2L; TestPoint_Pad_1.5x1.5mm
D18, D19: SMAJ48CA; D_SMA
Q2, Q3, Q4, Q5: ISC080N10NM6ATMA1; Infineon_PG-TDSON-8_6.15x5.15mm
R13, R14, R16, R22, R27: 3R3; R_0805_2012Metric
R20, R21, R26, R29, R31: 10k; R_0603_1608Metric
R23, R32, R35: 2k4; R_0603_1608Metric
R34: 12m; R_2512_6332Metric
TMP1: TMP; TestPoint_Pad_1.5x1.5mm
U3, U4: MP1917AGR-P; QFN-4x4_MP1917A_MNP
U5: MCP1501T-25E/CHY; SOT-23-6
U7: INA241B1IDDFR; TSOT-23-8
U9: MCP9700T-ELT; SOT-353_SC-70-5

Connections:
+2V5: C28.1, C47.1, R23.2, U7.7 (REF1); also elsewhere on the board
+3.3VA: C23.1, C25.1, C41.1, C42.1, U5.4 (~SHDN), U5.6 (VDD), U7.6 (V+), U9.4 (Vdd); also elsewhere on the board
+10V: C14.1, C16.1, C21.1, C22.1, U3.1 (VDD), U4.1 (VDD); also elsewhere on the board
+48V_Fused: Q2.5 (D), Q3.5 (D); also elsewhere on the board
/ATSAME51J18A-A/OUT_CS: C34.1, R27.1; also elsewhere on the board
/ATSAME51J18A-A/TEMP_SENSE_1: C27.1, R20.2; also elsewhere on the board
/Current Output/Bridge_Power_OUT_2: D19.2 (A2), R34.2, R35.1; also elsewhere on the board
/Current Output/DRIVER_1_H: Q3.4 (G), R14.1
/Current Output/DRIVER_1_L: D17.1, Q4.4 (G), R22.1
/Current Output/DRIVER_1_SW: C15.2, D18.2 (A2), Q3.1 (S), Q3.2 (S), Q3.3 (S), Q4.5 (D), U4.4 (SW); also elsewhere on the board
/Current Output/DRIVER_2_H: Q2.4 (G), R13.1
/Current Output/DRIVER_2_L: D13.1, Q5.4 (G), R16.2
/Current Output/DRIVER_2_SW: C18.2, Q2.1 (S), Q2.2 (S), Q2.3 (S), Q5.5 (D), R32.1, R34.1, U3.4 (SW)
/Current Output/TEMP_ANALOG: R20.1, TMP1.1, U9.3 (Vout)
A_HI: AH1.1, C30.1, R26.1, U4.7 (INH); also elsewhere on the board
A_LI: AL1.1, C26.1, R21.1, U4.8 (INL); also elsewhere on the board
B_HI: BH1.1, C36.1, R31.1, U3.7 (INH); also elsewhere on the board
B_LI: BL1.1, C35.1, R29.1, U3.8 (INL); also elsewhere on the board
GND: C14.2, C16.2, C21.2, C22.2, C23.2, C25.2, C26.2, C27.2, C28.2, C30.2, C34.2, C35.2, C36.2, C41.2, C42.2, C43.2, C47.2, C50.1, D18.1 (A1), D19.1 (A1), Q4.1 (S), Q4.2 (S), Q4.3 (S), Q5.1 (S), Q5.2 (S), Q5.3 (S), R21.2, R26.2, R29.2, R31.2, U3.9 (VSS), U3.11 (EPAD), U4.9 (VSS), U4.11 (EPAD), U5.2 (GND), U5.3 (GND), U5.5 (GND), U7.2 (GND), U7.3 (REF2), U7.4 (GND), U9.2 (GND); also elsewhere on the board
unnamed: CS1.1, R27.2, U7.5
unnamed: C18.1, U3.2 (BST)
unnamed: R13.2, U3.3 (DRVH)
unnamed: R16.1, U3.10 (DRVL)
unnamed: C15.1, U4.2 (BST)
unnamed: R14.2, U4.3 (DRVH)
unnamed: R22.2, U4.10 (DRVL)
unnamed: R23.1, U5.1 (OUT)
unnamed: C45.1, C50.2, R35.2, U7.8 (+)
unnamed: C43.1, C45.2, R32.2, U7.1 (-)

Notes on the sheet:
Diff mode 33 kHz Common mode 66 kHz
AA (EMI) RC filtr 88kHz AA RC filtr pro Input voltage a Temp sense 160 Hz

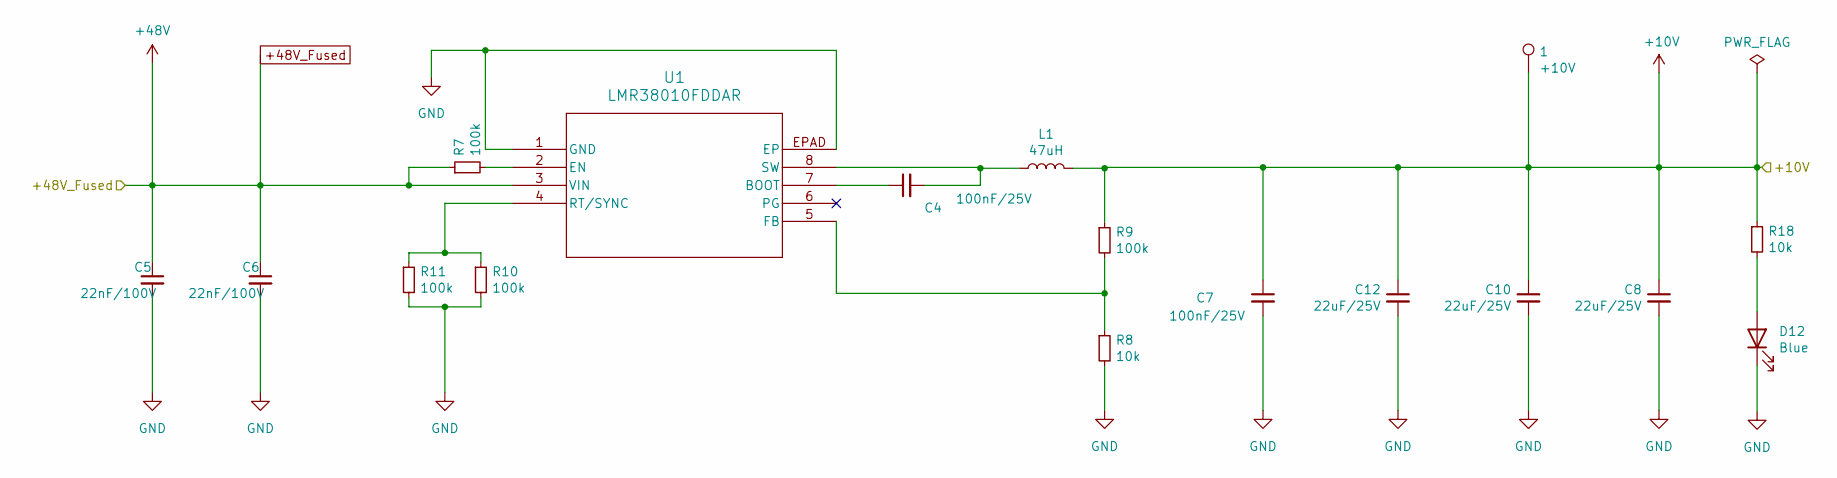
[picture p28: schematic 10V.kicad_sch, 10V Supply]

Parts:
1: +10V; TestPoint_Pad_1.5x1.5mm
C4, C7: 100nF/25V; C_0603_1608Metric
C5, C6: 22nF/100V; C_0603_1608Metric
C8, C10, C12: 22uF/25V; C_0805_2012Metric
D12: Blue; D_0603_1608Metric
L1: 47uH; L_Cenker_CKCS6045
R7, R9, R10, R11: 100k; R_0603_1608Metric
R8, R18: 10k; R_0603_1608Metric
U1: LMR38010FDDAR; LMR38010FDDAR_TEX-L

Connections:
+10V: 1.1, C7.1, C8.1, C10.1, C12.1, L1.2, R9.1, R18.1; also elsewhere on the board
+48V_Fused: C5.1, C6.1, R7.1, U1.3 (VIN); also elsewhere on the board
GND: C5.2, C6.2, C7.2, C8.2, C10.2, C12.2, D12.1 (K), R8.2, R10.2, R11.2, U1.1 (GND), U1.EPAD (EP); also elsewhere on the board
unnamed: D12.2 (A), R18.2
unnamed: C4.1, U1.7 (BOOT)
unnamed: R7.2, U1.2 (EN)
unnamed: R8.1, R9.2, U1.5 (FB)
unnamed: R10.1, R11.1, U1.4 (RT/SYNC)
unnamed: C4.2, L1.1, U1.8 (SW)

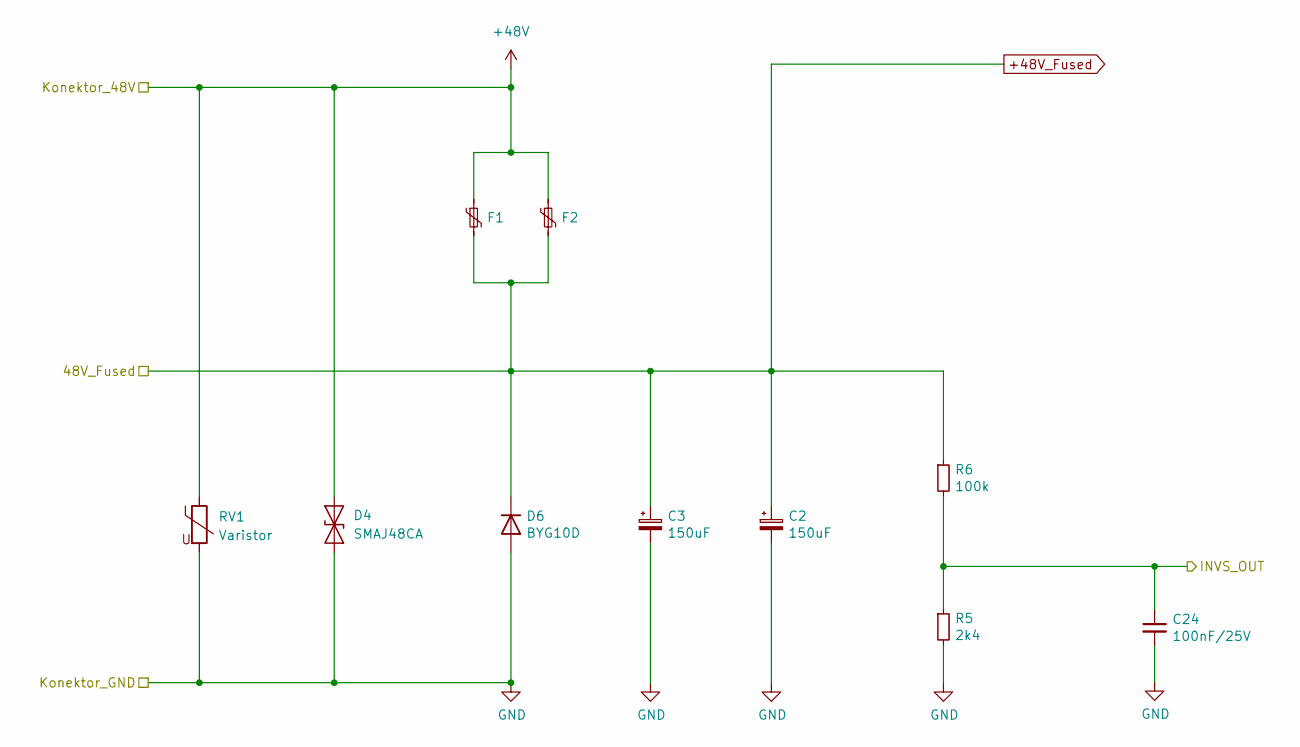
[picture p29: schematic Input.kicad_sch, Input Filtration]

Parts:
C2, C3: 150uF; CP_Radial_D10.0mm_P5.00mm
C24: 100nF/25V; C_0603_1608Metric
D4: SMAJ48CA; D_SMA
D6: BYG10D; D_SMA
F1, F2: 2920L150/60MR; Fuse_2920_7451Metric
R5: 2k4; R_0603_1608Metric
R6: 100k; R_0603_1608Metric
RV1: Varistor; R_0805_2012Metric

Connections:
+48V: D4.2 (A2), F1.1, F2.1, RV1.1; also elsewhere on the board
+48V_Fused: C2.1, C3.1, D6.1 (K), F1.2, F2.2, R6.1; also elsewhere on the board
/ATSAME51J18A-A/INVS_OUT: C24.1, R5.1, R6.2; also elsewhere on the board
GND: C2.2, C3.2, C24.2, D4.1 (A1), D6.2 (A), R5.2, RV1.2; also elsewhere on the board

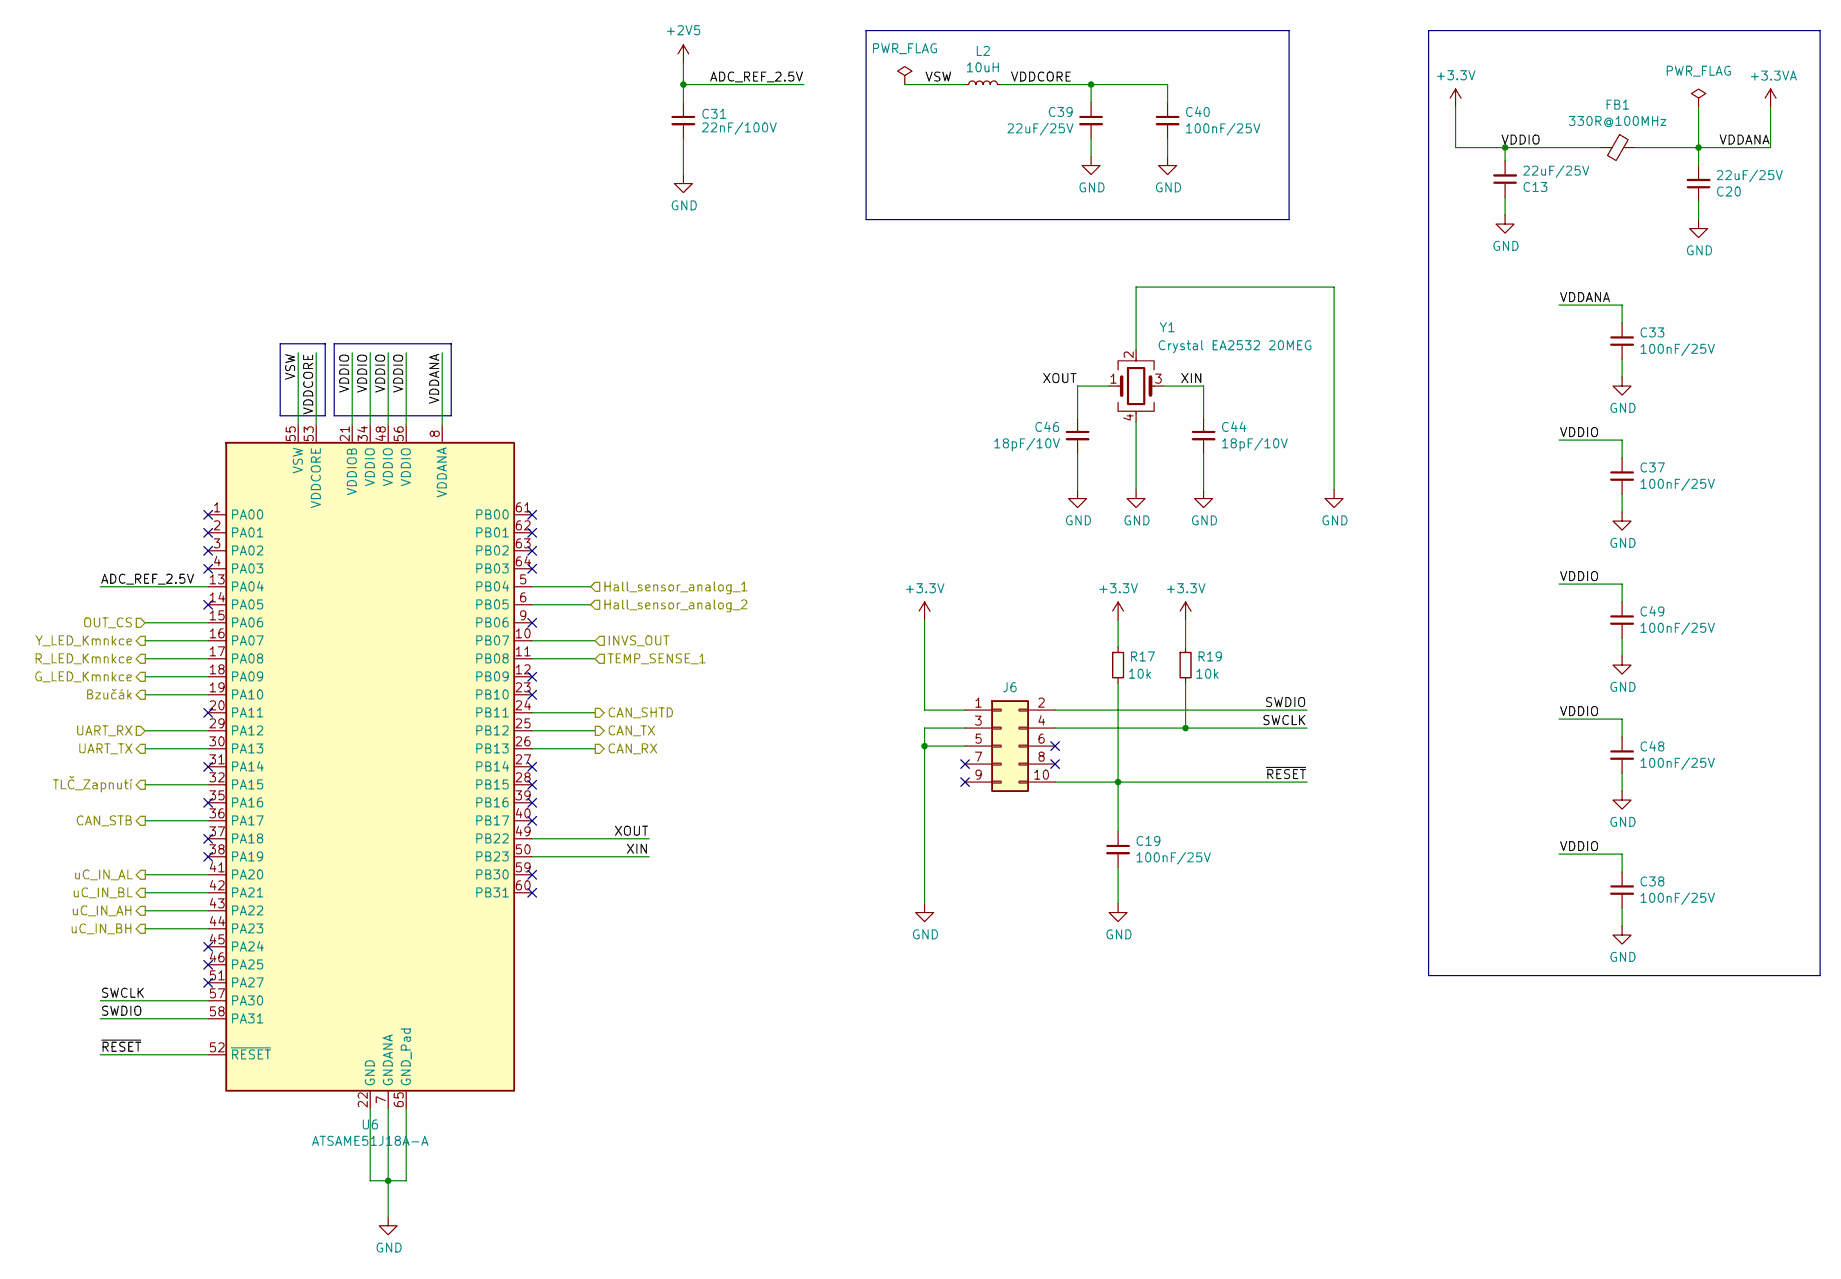
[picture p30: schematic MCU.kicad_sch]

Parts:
C13, C20, C39: 22uF/25V; C_0805_2012Metric
C19, C33, C37, C38, C40, C48, C49: 100nF/25V; C_0603_1608Metric
C31: 22nF/100V; C_0603_1608Metric
C44, C46: 18pF/10V; C_0603_1608Metric
FB1: 330R@100MHz; L_0805_2012Metric
J6: PRG_Kon; PinHeader_2x05_P1.27mm_Vertical
L2: 10uH; L_Wuerth_MAPI-2010
R17, R19: 10k; R_0603_1608Metric
U6: ATSAME51J18A-A; QFN-64-1EP_9x9mm_P0.5mm_EP4.7x4.7mm
Y1: Crystal EA2532 20MEG; Crystal_SMD_EuroQuartz_MT-4Pin_3.2x2.5mm

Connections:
+2V5: C31.1, U6.13 (PA04); also elsewhere on the board
+3.3V: C13.2, C37.1, C38.1, C48.1, C49.1, FB1.2, J6.1, R17.1, R19.1, U6.21 (VDDIOB), U6.34 (VDDIO), U6.48 (VDDIO), U6.56 (VDDIO); also elsewhere on the board
+3.3VA: C20.2, C33.1, FB1.1, U6.8 (VDDANA); also elsewhere on the board
/ATSAME51J18A-A/Bzučák: U6.19 (PA10); also elsewhere on the board
/ATSAME51J18A-A/CAN_RX: U6.26 (PB13); also elsewhere on the board
/ATSAME51J18A-A/CAN_SHTD: U6.24 (PB11); also elsewhere on the board
/ATSAME51J18A-A/CAN_STB: U6.36 (PA17); also elsewhere on the board
/ATSAME51J18A-A/CAN_TX: U6.25 (PB12); also elsewhere on the board
/ATSAME51J18A-A/G_LED_Kmnkce: U6.18 (PA09); also elsewhere on the board
/ATSAME51J18A-A/Hall_sensor_analog_1: U6.5 (PB04); also elsewhere on the board
/ATSAME51J18A-A/Hall_sensor_analog_2: U6.6 (PB05); also elsewhere on the board
/ATSAME51J18A-A/INVS_OUT: U6.10 (PB07); also elsewhere on the board
/ATSAME51J18A-A/OUT_CS: U6.15 (PA06); also elsewhere on the board
/ATSAME51J18A-A/R_LED_Kmnkce: U6.17 (PA08); also elsewhere on the board
/ATSAME51J18A-A/SWCLK: J6.4, R19.2, U6.57 (PA30)
/ATSAME51J18A-A/SWDIO: J6.2, U6.58 (PA31)
/ATSAME51J18A-A/TEMP_SENSE_1: U6.11 (PB08); also elsewhere on the board
/ATSAME51J18A-A/TLČ_Zapnutí: U6.32 (PA15); also elsewhere on the board
/ATSAME51J18A-A/UART_RX: U6.29 (PA12); also elsewhere on the board
/ATSAME51J18A-A/UART_TX: U6.30 (PA13); also elsewhere on the board
/ATSAME51J18A-A/VDDCORE: C39.1, C40.1, L2.2, U6.53 (VDDCORE)
/ATSAME51J18A-A/VSW: L2.1, U6.55 (VSW)
/ATSAME51J18A-A/XIN: C44.1, U6.50 (PB23), Y1.3
/ATSAME51J18A-A/XOUT: C46.1, U6.49 (PB22), Y1.1
/ATSAME51J18A-A/Y_LED_Kmnkce: U6.16 (PA07); also elsewhere on the board
/ATSAME51J18A-A/~RESET: C19.1, J6.10, R17.2, U6.52 (~RESET)
A_HI: U6.43 (PA22); also elsewhere on the board
A_LI: U6.41 (PA20); also elsewhere on the board
B_HI: U6.44 (PA23); also elsewhere on the board
B_LI: U6.42 (PA21); also elsewhere on the board
GND: C13.1, C19.2, C20.1, C31.2, C33.2, C37.2, C38.2, C39.2, C40.2, C44.2, C46.2, C48.2, C49.2, J6.3, J6.5, U6.7 (GNDANA), U6.22 (GND), U6.33 (GND), U6.47 (GND), U6.54 (GND), U6.65 (GND_Pad), Y1.2, Y1.4; also elsewhere on the board

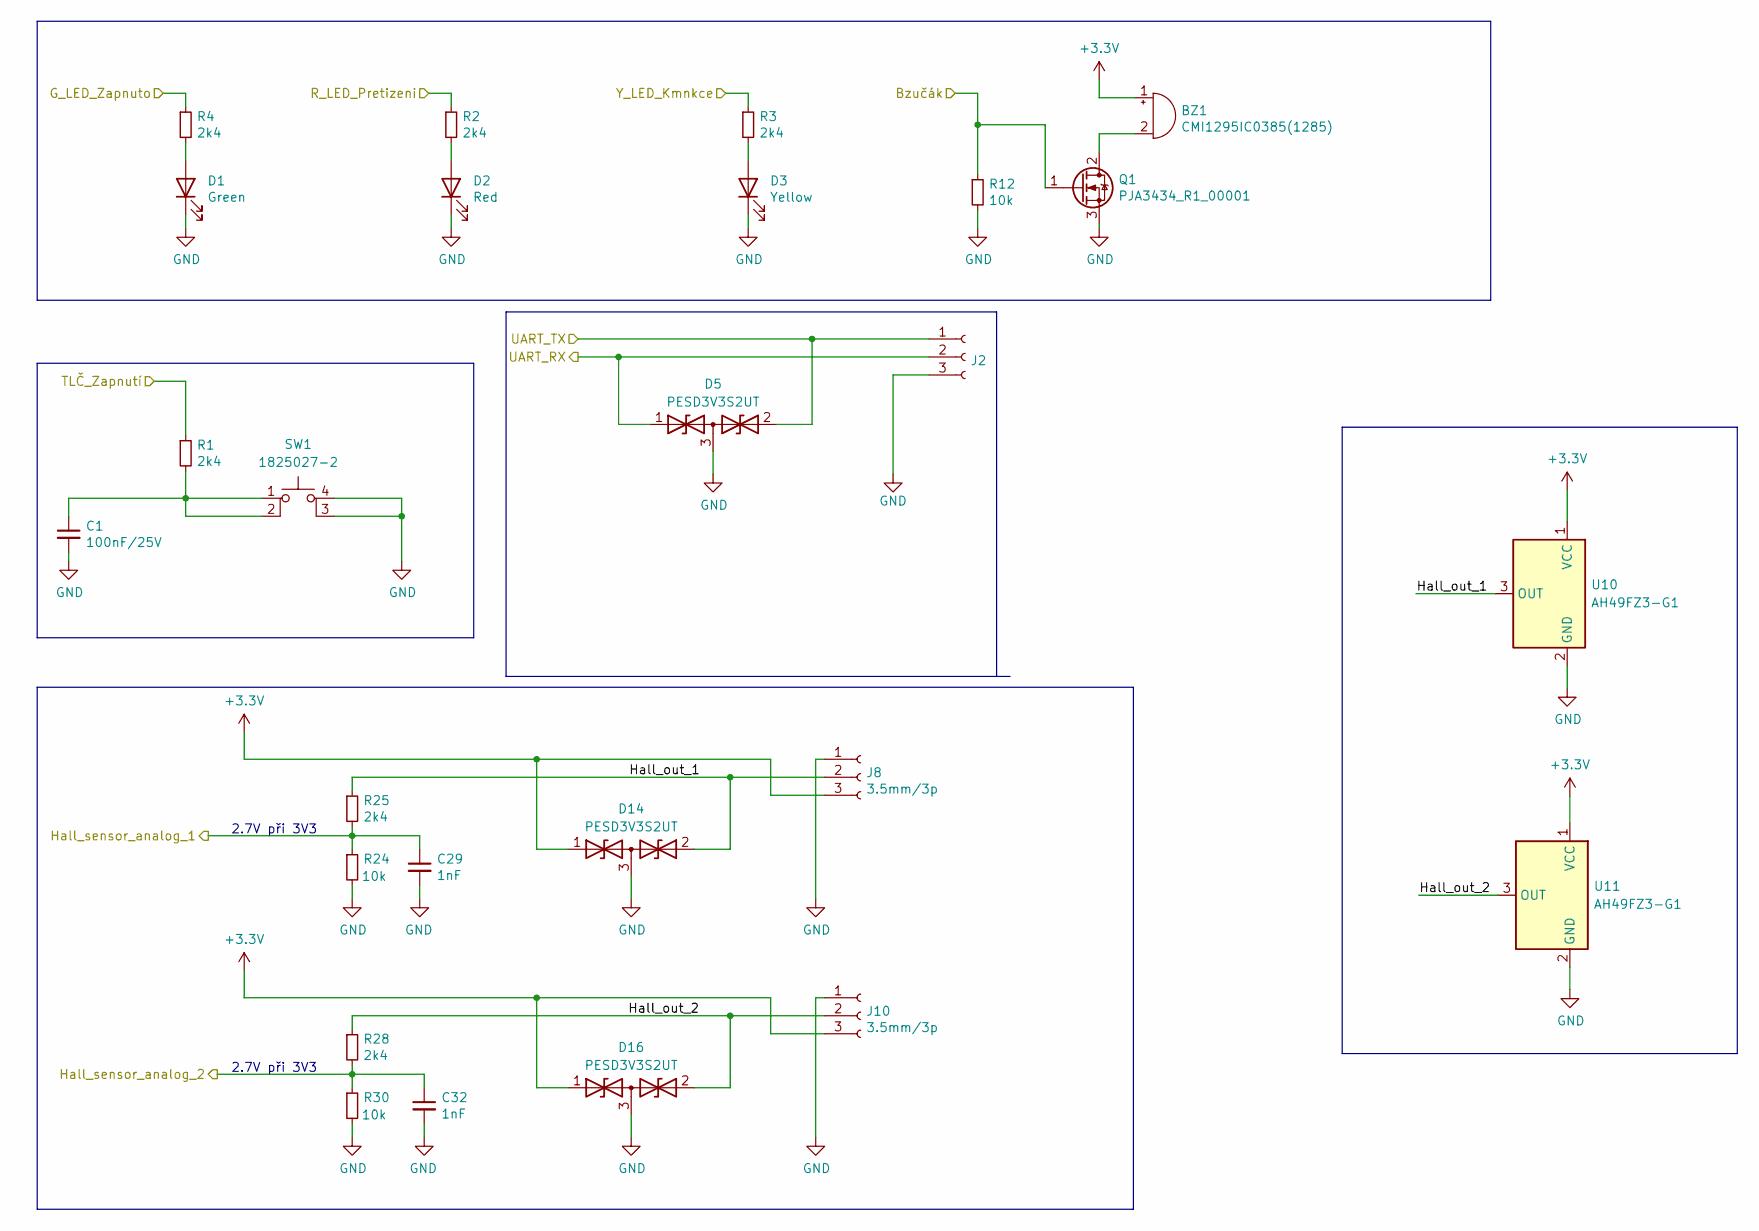
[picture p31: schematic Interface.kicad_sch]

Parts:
BZ1: CMI1295IC0385(1285); Buzzer_12x9.5RM7.6
C1: 100nF/25V; C_0603_1608Metric
C29, C32: 1nF; C_0603_1608Metric
D1: Green; D_0603_1608Metric
D2: Red; D_0603_1608Metric
D3: Yellow; D_0603_1608Metric
D5, D14, D16: PESD3V3S2UT; SOT-23
J2: 2.54mm/3p; PinHeader_1x03_P2.54mm_Vertical
J8, J10: 3.5mm/3p; PhoenixContact_MC_1,5_3-G-3.5_1x03_P3.50mm_Horizontal
Q1: PJA3434_R1_00001; SOT-23-3
R1, R2, R3, R4, R25, R28: 2k4; R_0603_1608Metric
R12, R24, R30: 10k; R_0603_1608Metric
SW1: 1825027-2; SW_Tactile_SPST_Angled_PTS645Vx39-2LFS
U10, U11: AH49FZ3-G1; TO-92_Inline

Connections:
+3.3V: BZ1.1 (-), D14.1 (A1), D16.1 (A1), J8.3, J10.3, U10.1 (VCC), U11.1 (VCC); also elsewhere on the board
/ATSAME51J18A-A/Bzučák: Q1.1 (G), R12.1; also elsewhere on the board
/ATSAME51J18A-A/G_LED_Kmnkce: R4.1; also elsewhere on the board
/ATSAME51J18A-A/Hall_sensor_analog_1: C29.1, R24.1, R25.2; also elsewhere on the board
/ATSAME51J18A-A/Hall_sensor_analog_2: C32.1, R28.2, R30.1; also elsewhere on the board
/ATSAME51J18A-A/R_LED_Kmnkce: R2.1; also elsewhere on the board
/ATSAME51J18A-A/TLČ_Zapnutí: R1.1; also elsewhere on the board
/ATSAME51J18A-A/UART_RX: D5.1 (A1), J2.2; also elsewhere on the board
/ATSAME51J18A-A/UART_TX: D5.2 (A2), J2.1; also elsewhere on the board
/ATSAME51J18A-A/Y_LED_Kmnkce: R3.1; also elsewhere on the board
/Interface/Hall_out_1: D14.2 (A2), J8.2, R25.1, U10.3 (OUT)
/Interface/Hall_out_2: D16.2 (A2), J10.2, R28.1, U11.3 (OUT)
GND: C1.2, C29.2, C32.2, D1.1 (K), D2.1 (K), D3.1 (K), D5.3 (common), D14.3 (common), D16.3 (common), J2.3, J8.1, J10.1, Q1.3 (S), R12.2, R24.2, R30.2, SW1.3 (K), SW1.4 (A), U10.2 (GND), U11.2 (GND); also elsewhere on the board
unnamed: BZ1.2 (+), Q1.2 (D)
unnamed: C1.1, R1.2, SW1.1, SW1.2
unnamed: D1.2 (A), R4.2
unnamed: D2.2 (A), R2.2
unnamed: D3.2 (A), R3.2

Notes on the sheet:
2.7V při 3V3

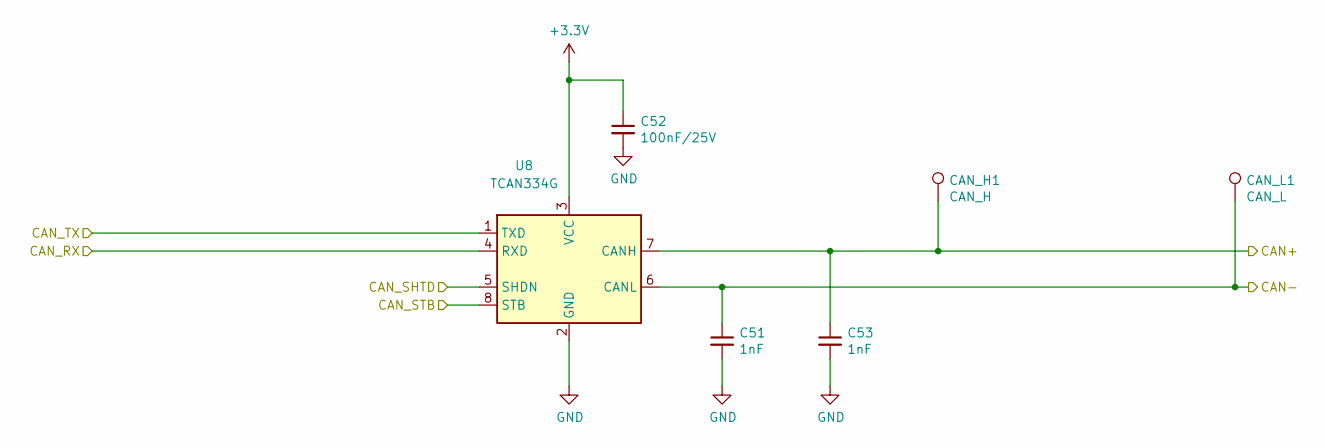
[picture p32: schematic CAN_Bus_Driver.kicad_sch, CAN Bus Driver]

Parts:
C51, C53: 1nF; C_0603_1608Metric
C52: 100nF/25V; C_0603_1608Metric
CAN_H1: CAN_H; TestPoint_Pad_1.5x1.5mm
CAN_L1: CAN_L; TestPoint_Pad_1.5x1.5mm
U8: TCAN334G; SOT-23-8

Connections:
+3.3V: C52.1, U8.3 (VCC); also elsewhere on the board
/ATSAME51J18A-A/CAN_RX: U8.4 (RXD); also elsewhere on the board
/ATSAME51J18A-A/CAN_SHTD: U8.5 (SHDN); also elsewhere on the board
/ATSAME51J18A-A/CAN_STB: U8.8 (STB); also elsewhere on the board
/ATSAME51J18A-A/CAN_TX: U8.1 (TXD); also elsewhere on the board
/CAN+: C53.1, CAN_H1.1, U8.7 (CANH); also elsewhere on the board
/CAN-: C51.1, CAN_L1.1, U8.6 (CANL); also elsewhere on the board
GND: C51.2, C52.2, C53.2, U8.2 (GND); also elsewhere on the board

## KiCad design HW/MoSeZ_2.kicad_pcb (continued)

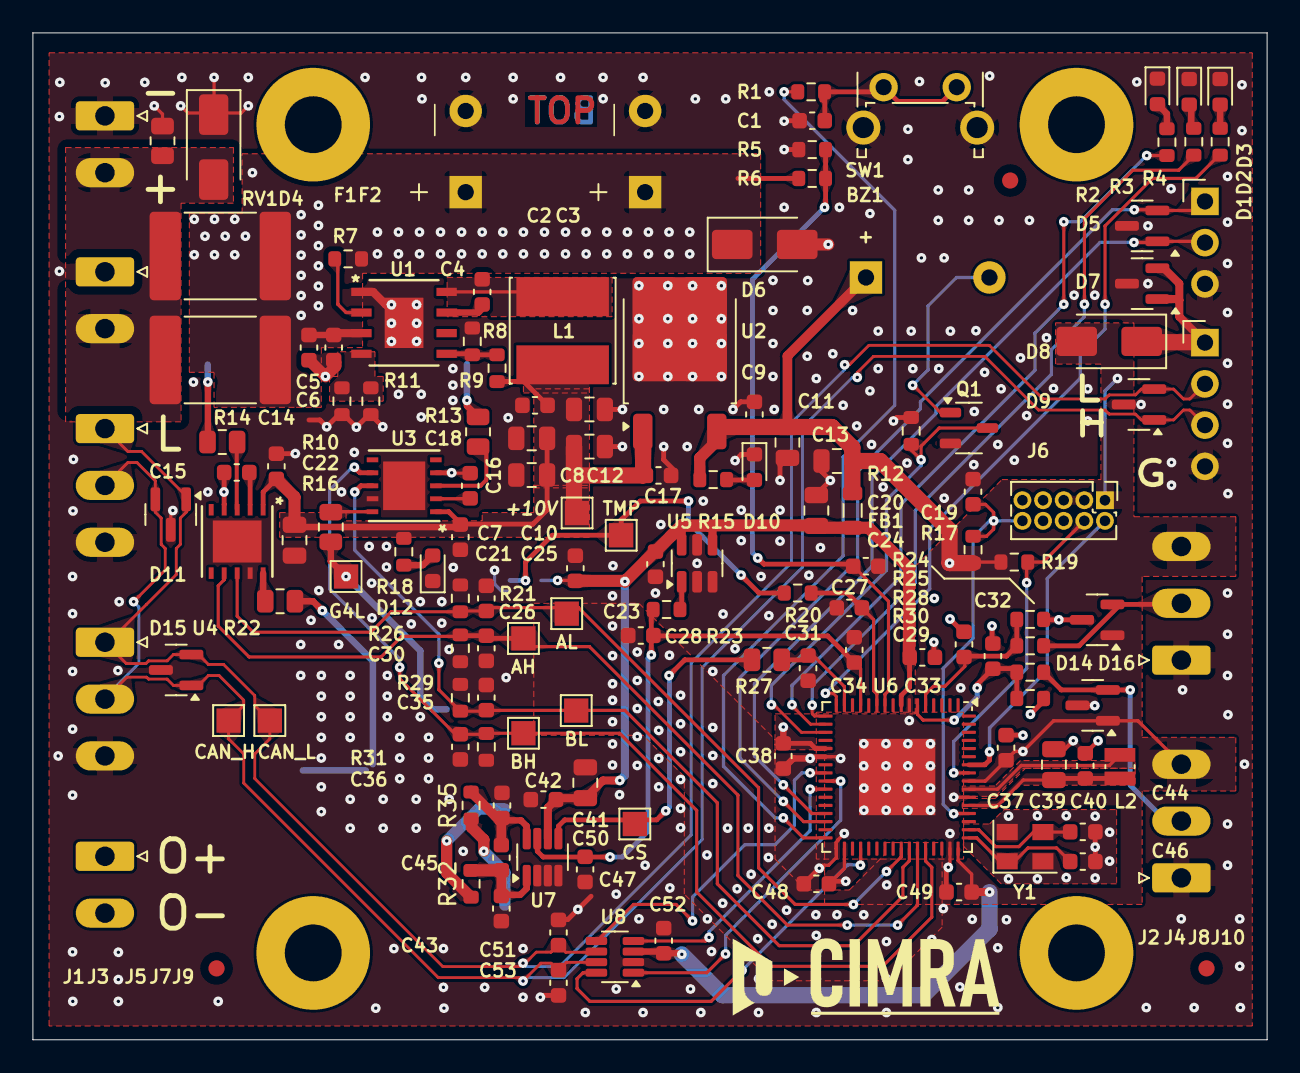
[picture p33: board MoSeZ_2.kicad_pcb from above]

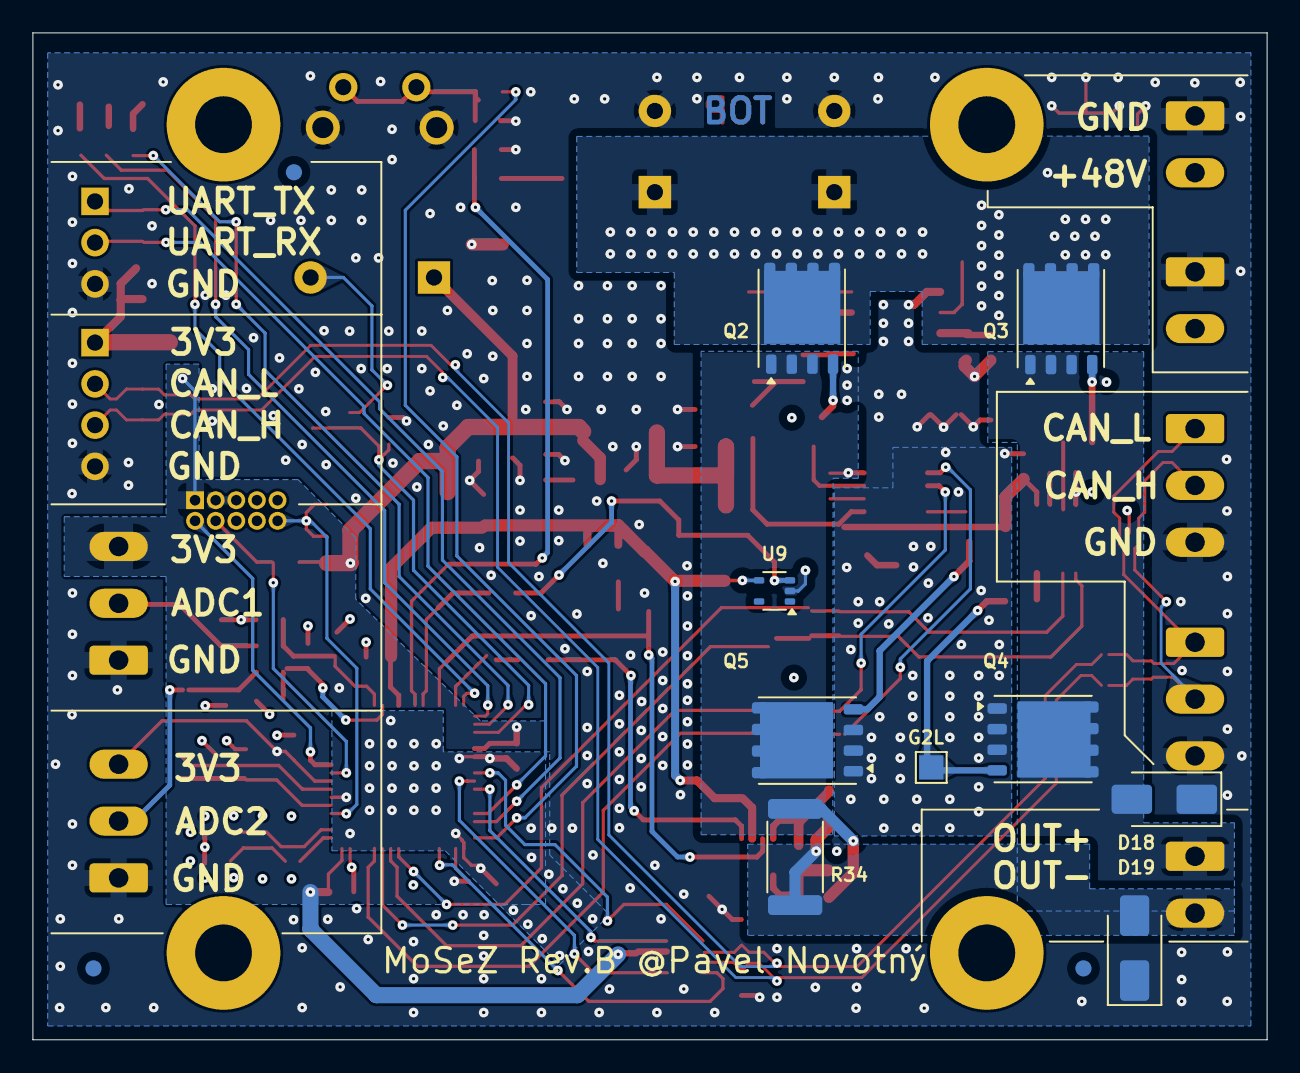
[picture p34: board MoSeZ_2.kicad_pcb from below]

Board: 4 copper layers, 76.0 x 62.0 mm, 160 parts (12 on the bottom side), 69 nets.

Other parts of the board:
G1: LOGO; cimra
G2: LOGO; zcu

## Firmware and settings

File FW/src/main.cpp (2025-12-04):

#include "aron/init.hpp"

using namespace nd;

int main()
{
    aron::init_sequence();                              // Initialization Of MCU And Its Peripherials
    aron::Communication::init(aron::Interface::can, 1); // <-- Adjust Defualtly Programmed CAN ID Here
    // aron::Interface::init_can_logger();              // <-- Logs On UART When Commented, Uncomment For Redirection Of Logs To CAN

#pragma clang diagnostic push
#pragma ide diagnostic ignored "EndlessLoop"
    while (true)
    {
        aron::Communication::rx_handler(); // Proccessing Messages From CAN And UART
        aron::TimerManager::run();         // General Timed Events
        aron::watch_dog_reset();           // WatchDog Feeding
    }
#pragma clang diagnostic pop
}

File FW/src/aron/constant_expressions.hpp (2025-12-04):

#pragma once
namespace aron
{
    namespace CommandConstants
    {
        // Validation Constants
        static constexpr int32_t OUTPUT_DISABLED = 0;                // -
        static constexpr int32_t OUTPUT_ENABLED = 1;                 // -
        static constexpr int32_t DUTY_CYCLE_MIN = 0;                 // %
        static constexpr int32_t DUTY_CYCLE_MAX = 100;               // %
        static constexpr int32_t RAMP_MIN = 0;                       // %
        static constexpr int32_t RAMP_MAX = 50;                      // %
        static constexpr int32_t PHASE_MIN = 0;                      // Degrees
        static constexpr int32_t PHASE_MAX = 360;                    // Degrees
        static constexpr int32_t OFFSET_MIN = -8000;                 // mA
        static constexpr int32_t OFFSET_MAX = 8000;                  // mA
        static constexpr int32_t CURRENT_MIN = -10000;               // mA
        static constexpr int32_t CURRENT_MAX = 10000;                // mA
        static constexpr int32_t FREQUENCY_MIN = 1;                  // Hz
        static constexpr int32_t FREQUENCY_MAX = 3000;               // Hz
        static constexpr int32_t SEQ_PERIOD_MIN = 1;                 // Mininmal number of periods
        static constexpr int32_t SEQ_MS_MIN = 1;                     // Mininmal number of periods
        static constexpr float POSITION_AMPLITUDE_OFFSET_MAX = 8.0f; // mm
        static constexpr float POSITION_AMPLITUDE_OFFSET_MIN = 1.0f; // mm

        // Declare constexpr command strings
        static constexpr std::string_view CURRENT_COMMAND = "I";
        static constexpr std::string_view AC_OFFSET_COMMAND = "O";
        static constexpr std::string_view SQUARE_DUTY_COMMAND = "C";
        static constexpr std::string_view SQUARE_RAMP_COMMAND = "RT";
        static constexpr std::string_view PHASE_SHIFT_COMMAND = "F";
        static constexpr std::string_view POSITION_AMPLITUDE_COMMAND = "R";
        static constexpr std::string_view POSITION_OFFSET_COMMAND = "V";
        static constexpr std::string_view WAVEFORM_HARMONIC_COMMAND = "H"; // or WAVEFORM_COMMAND
        static constexpr std::string_view WAVEFORM_TRIANGLE_COMMAND = "T"; // or WAVEFORM_COMMAND
        static constexpr std::string_view WAVEFORM_SQUARE_COMMAND = "S";   // or WAVEFORM_COMMAND
        static constexpr std::string_view OUTPUT_DC_COMMAND = "D";         // or OUTPUT_SELECT_COMMAND
        static constexpr std::string_view OUTPUT_AC_COMMAND = "A";         // or OUTPUT_SELECT_COMMAND
        static constexpr std::string_view OUTPUT_PULSE_COMMAND = "P";      // or OUTPUT_SELECT_COMMAND
    }
    namespace UniqueMessageIDs
    {
        // Unique message IDs
        static constexpr uint8_t Broadcast{255};
        static constexpr uint8_t HeartBeat{254};
        static constexpr uint8_t PendingIDConfirmation{253};
        static constexpr uint8_t GeneralInfo{252};
        static constexpr uint8_t GeneralProblem{251};
        static constexpr uint8_t valid_msg_ids[] = {HeartBeat, PendingIDConfirmation, GeneralInfo, GeneralProblem};
        static constexpr size_t valid_msg_ids_size = sizeof(valid_msg_ids) / sizeof(valid_msg_ids[0]);
    };
}

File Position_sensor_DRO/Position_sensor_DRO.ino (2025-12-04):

const int pinA = 2, pinB = 3;
const int phaseLookup[] = {0, -1, 1, -1, 1, 0, -1, -1, -1, 1, 0, 1, 1, 1, -1, 0};

volatile bool A = false, B = false;
volatile long counter = 0; 
volatile int phase = 0;

unsigned long lastPrintTime = 0; 

void setup()
{
  Serial.begin(230400);
  
  pinMode(pinA, INPUT);
  pinMode(pinB, INPUT);
  
  attachInterrupt(digitalPinToInterrupt(pinA), trig, CHANGE);
  attachInterrupt(digitalPinToInterrupt(pinB), trig, CHANGE);
}

void trig()
{
  uint8_t newPhase = (digitalRead(pinA) << 1) | digitalRead(pinB);

  // Check for valid transitions
  uint8_t expectedPhase = (phase & 0x3); // Last two bits of the phase
  if (((expectedPhase == 0b00) && (newPhase == 0b01 || newPhase == 0b10)) ||
      ((expectedPhase == 0b01) && (newPhase == 0b11 || newPhase == 0b00)) ||
      ((expectedPhase == 0b11) && (newPhase == 0b10 || newPhase == 0b01)) ||
      ((expectedPhase == 0b10) && (newPhase == 0b00 || newPhase == 0b11)))
  {
    phase = ((phase << 2) | newPhase) & 0xF;
    counter += phaseLookup[phase];
  }
}

  
void loop()
{
  unsigned long currentTime = millis(); 
  if (currentTime - lastPrintTime >= 10) // Update faster
  {
    Serial.println(float(-counter * 0.005)); 
    lastPrintTime = currentTime; 
  }
}

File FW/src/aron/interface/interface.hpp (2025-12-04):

#pragma once

#include <cstdint>
#include <array>
#include <string_view>
#include <sam.h>
#include <cctype>
#include <charconv>

#include "drivers/gpio/gpio_same5x.hpp"
#include "drivers/systick/systick.hpp"
#include "drivers/can/transcievers/tcan334.h"
#include "drivers/can/can_same5x.hpp"
#include "drivers/sam5x/gclk.hpp"
#include "drivers/sam5x/mclk.hpp"

#include "utils/logging/Logger.hpp"
#include "utils/logging/LoggerUart.hpp"
#include "utils/logging/LoggerCan.hpp"

#include "aron/communication/communication.hpp"

namespace aron
{

    using namespace nd;
    class Interface
    {
    public:
        /* LEDs */
        static inline drivers::Gpio_same5x led_green{drivers::gpio_pins::pa09};
        static inline drivers::Gpio_same5x led_yellow{drivers::gpio_pins::pa07};
        static inline drivers::Gpio_same5x led_red{drivers::gpio_pins::pa08};
        /* BUTTON */
        static inline drivers::Gpio_same5x button_1{drivers::gpio_pins::pa15, true};
        /* CAN */
        static inline drivers::TCAN334<drivers::Gpio_same5x> can_xcvr{drivers::gpio_pins::pa17, drivers::gpio_pins::pb11};
        static inline drivers::CAN_ATSAM_C_E can{CAN1, drivers::gpio_pins::pb13, drivers::gpio_pins::pb12};
        /* LOGGER */
        static inline nd::utils::LoggerUart logger{SERCOM4, drivers::gpio_pins::pa13, drivers::gpio_pins::pa12, 921'600, drivers::Gpio_alt_functions::D, 1, 0, 0};
        static inline nd::utils::LoggerCan can_logger; // Define the static member can_logger

        static void init_led();
        static void init_button();
        static void init_communication();
        static void init_can_logger();
        static void init_all();
        static void button_press();
    };
}
